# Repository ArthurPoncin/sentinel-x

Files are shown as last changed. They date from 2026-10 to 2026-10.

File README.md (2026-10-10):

<div align="center">

# Sentinel-X

**An autonomous surveillance outpost for remote industrial sites.**

One enclosure senses gas leaks, overheating and intruders, raises its own alarm,
and shows the whole site on a real-time 3D Digital Twin.

<p>
  
  
  
</p>

<p>
  
  
  
  
  
  <br>
  
  
  
  
  
  
  <br>
  
  
  
  
</p>

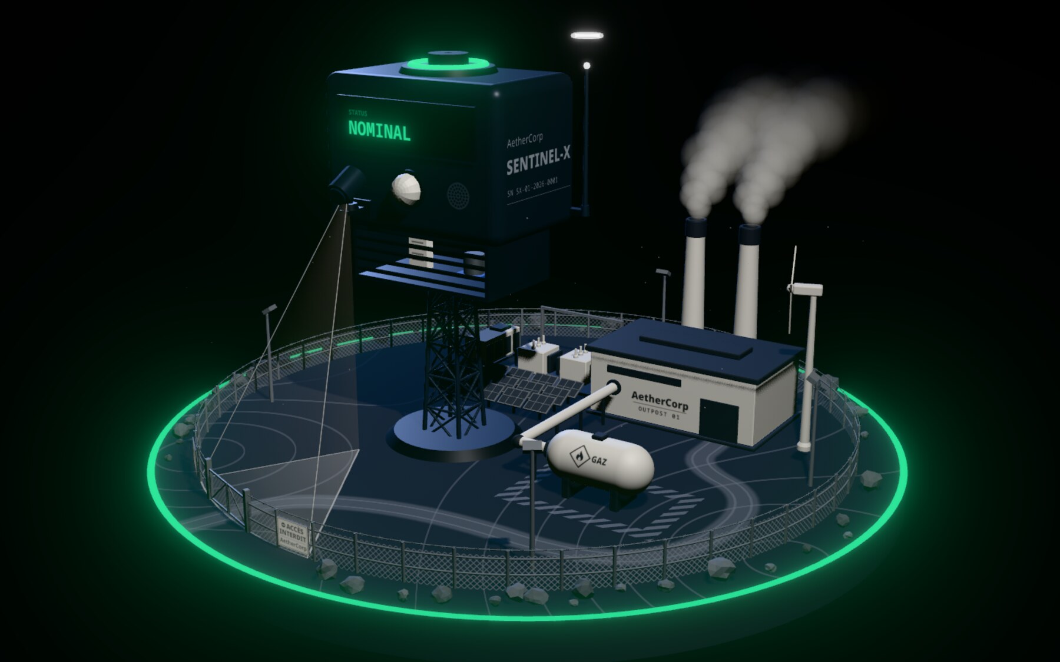
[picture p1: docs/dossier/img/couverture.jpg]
The Digital Twin of the outpost, Status nominal: the Sentinel-X enclosure on its mast, the generator hall, the gas tank, the fence and the camera's field


[Screens](#screens) · [Features](#features) · [Architecture](#architecture) · [Security](#security) · [Quick start](#quick-start) · [Documentation](#documentation)

</div>

## Overview

Sentinel-X answers a brief from the EPSI Workshop 2026: protect a micro power plant in a remote, hostile area where no staff can stay on site. An ESP32 and a Raspberry Pi 4 share one 3D-printed enclosure. Together they watch the site, decide alone, and report to an Operator over an isolated, encrypted Wi-Fi link.

| It guards against | How | Decided on |
|---|---|---|
| Gas leak, overheating | MQ-2 and DHT22 probes, thresholds with hysteresis, siren fired locally | ESP32 |
| Presence, noise | PIR and sound sensor | ESP32 |
| Intrusion | Person detection on a USB webcam that turns to follow whoever it sees | Raspberry Pi 4 |
| A failure before it happens | Isolation Forest on the trend of temperature and gas, no fixed threshold | Raspberry Pi 4 |
| Network attack | TLS and authentication on every channel, two service ports exposed | Whole stack |

Five students built it in one week: more than 270 commits, 78 merged pull requests and 1,483 automated tests.

## Screens

The Twin is not an illustration. It is driven by the same event stream the real enclosure emits.

<table>
  <tr>
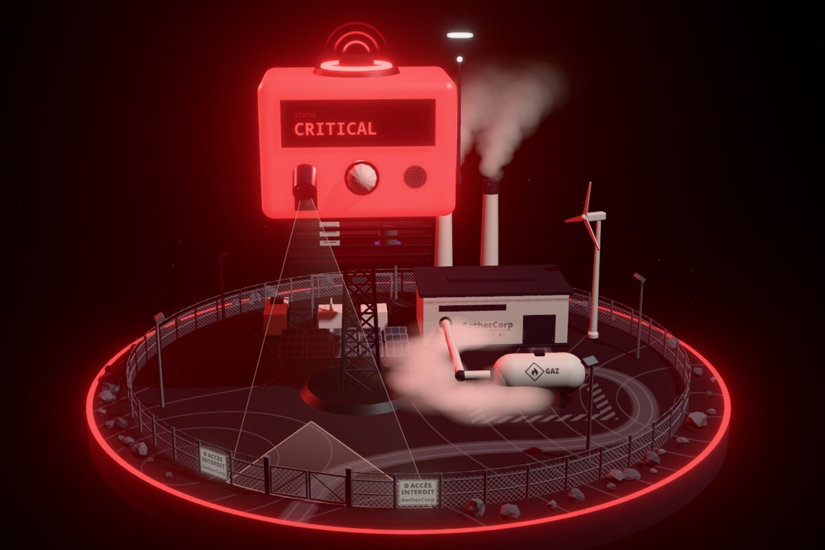
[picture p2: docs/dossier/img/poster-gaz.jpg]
Digital Twin during a gas leak: Status critical, haze around the gas pipe
    <td width="33%"></td>
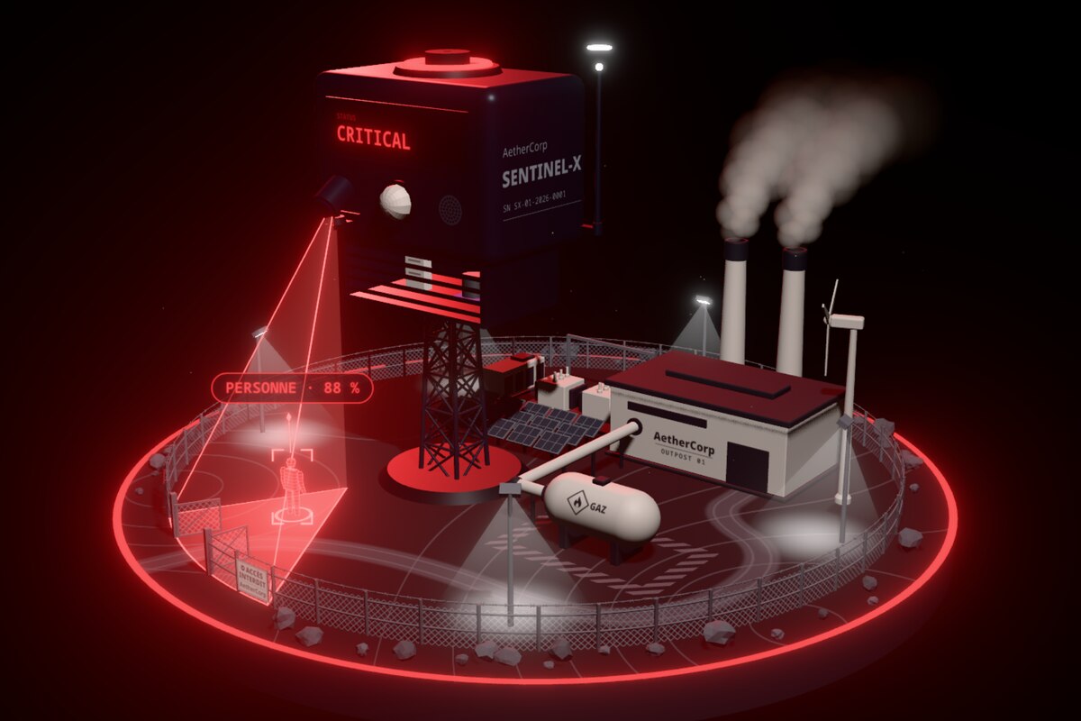
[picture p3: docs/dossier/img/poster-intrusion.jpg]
Digital Twin during an intrusion: a hologram figurine inside the fence, labelled with the model's confidence
    <td width="33%"></td>
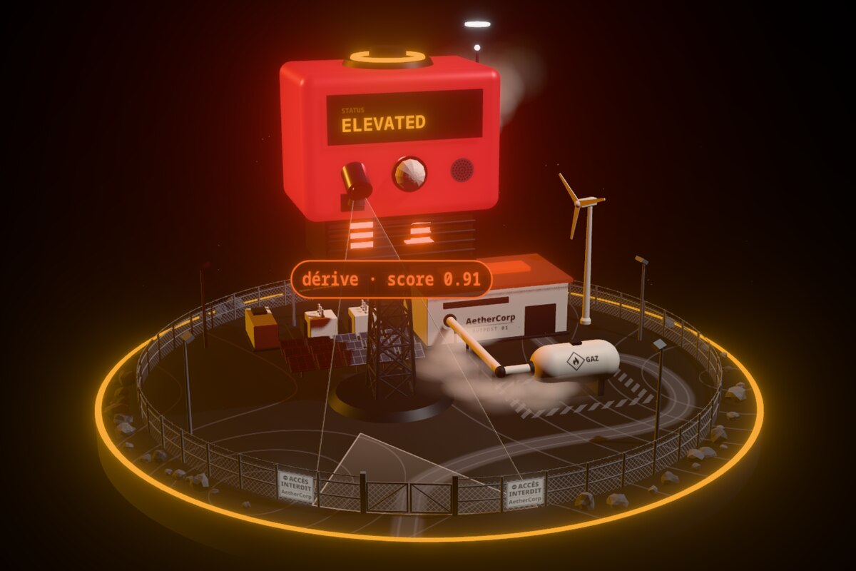
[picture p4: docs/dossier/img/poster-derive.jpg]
Digital Twin during a predicted drift: Status elevated, anomaly score 0.91
    <td width="33%"></td>
  </tr>
  <tr>
    <td align="center"><b>Gas leak</b><br><sub>Status critical, haze thickens at the pipe, the siren sounds</sub></td>
    <td align="center"><b>Intrusion</b><br><sub>A figurine stands where the camera sees the person, floodlights on</sub></td>
    <td align="center"><b>Predicted drift</b><br><sub>The drifting component pulses before any threshold is crossed</sub></td>
  </tr>
</table>

<p align="center">
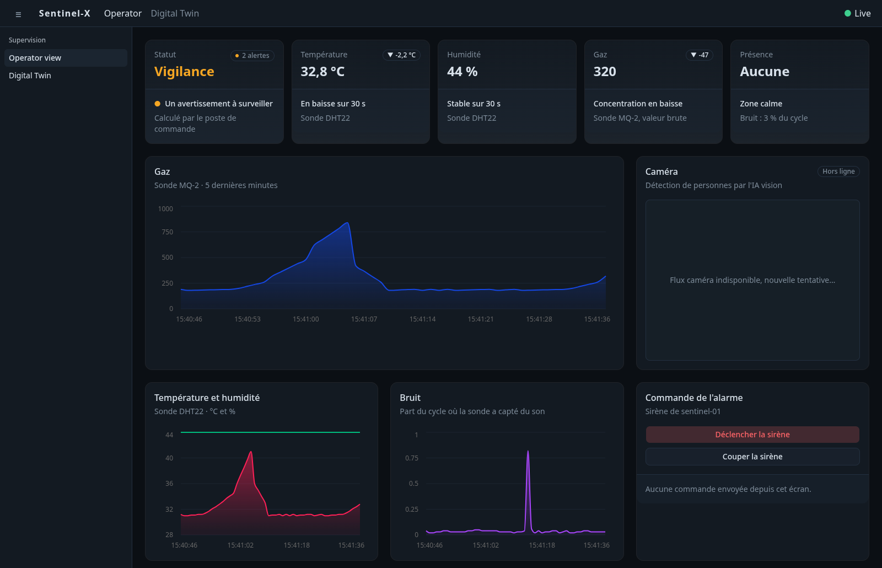
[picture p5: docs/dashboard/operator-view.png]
Operator view: Status, live Readings, gas, temperature and noise charts, camera panel and siren control
  
  <br>
  <sub><b>Operator view.</b> Status, live Readings, charts, camera panel and siren control. Captured on the scripted mock feed, so the camera panel has no webcam to show.</sub>
</p>

<table>
  <tr>
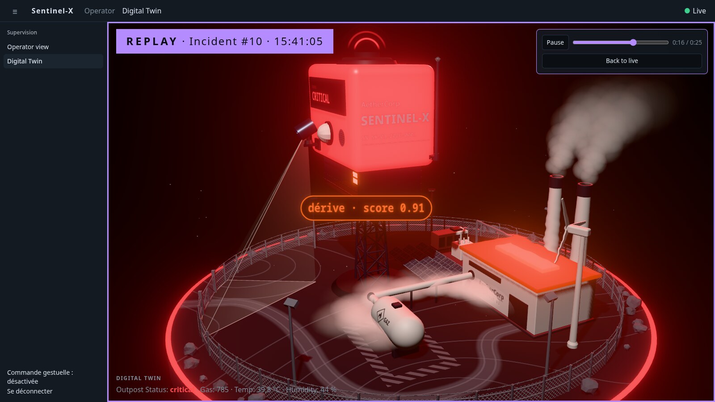
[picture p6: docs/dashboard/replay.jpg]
The Digital Twin replaying a recorded Incident, with the time-scrubber at 0:16 of 0:25
    <td width="50%"></td>
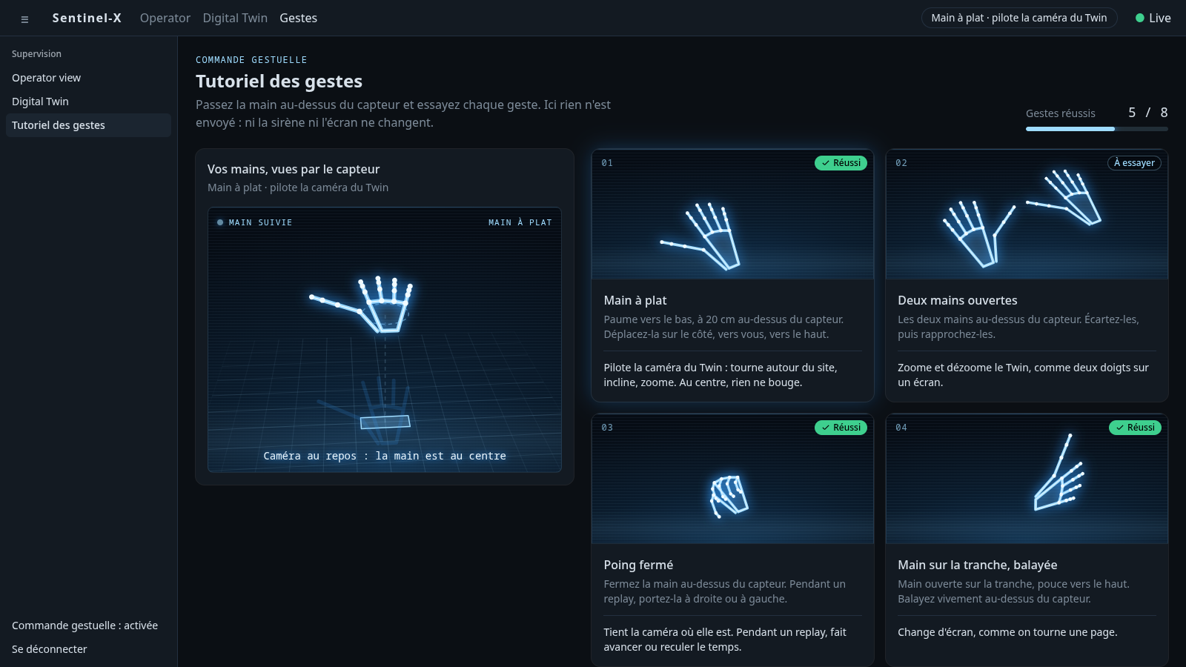
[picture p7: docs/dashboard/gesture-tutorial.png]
Gesture tutorial: the tracked hand in hologram and the gestures already made
    <td width="50%"></td>
  </tr>
  <tr>
    <td align="center"><b>Time-scrubber</b><br><sub>Any recorded Incident replays second by second on the Twin</sub></td>
    <td align="center"><b>Hand control</b><br><sub>The gesture tutorial, here with the bridge's simulated hand</sub></td>
  </tr>
</table>

A 60-second teaser is in the repository: [`docs/livrables/sentinel-x-teaser.mp4`](docs/livrables/sentinel-x-teaser.mp4).

## Features

**Digital Twin.** A live 3D model of the outpost (Three.js, react-three-fiber) fed by the Command Post's WebSocket stream.

| Signal | What the Twin does |
|---|---|
| Gas Reading | Haze thickens around the gas pipe, the enclosure glows red |
| Temperature | The generator hall's roof glows, the air above it ripples on a thermal Alert |
| Presence (PIR) | An amber sweep goes round the fence, the floodlights come on |
| Noise | A wave of light spreads from the enclosure, scaled to how loud it was |
| Intrusion | A hologram figurine stands where the person is, the camera's field turns with the real camera |
| Predictive drift | The drifting component pulses orange, with its anomaly score |
| Status | The scene is flooded in the Status color, then the ring and the LCD keep it |
| Feed lost | The picture drops out like a screen's, so a lost link never passes for a calm site |

**Autonomy at the edge.** The Sentinel decides its own Alerts and fires the siren even when the Command Post is down. One Alert is one transition: hysteresis on every threshold, no flapping.

**Vision.** EfficientDet-Lite0 on LiteRT keeps the `person` class only. A tracker follows the nearest person, tells of up to four others, and sends where they stand (`x_norm`, `h_norm`, `pan`) so the Twin places each one. A stepper motor turns the webcam toward the person followed.

**Predictive maintenance.** No `if temp > 40`. An Isolation Forest scores a 120-second window of seven features: the levels of temperature, humidity and gas, then the slopes and rolling means of temperature and gas. The model in service was trained on 32,101 readings from the real Sentinel (20,009 vectors), and its raise and clear levels are learned from held-out nominal data. On the synthetic drift shipped with the repo, the Alert comes about 43 minutes before the warning threshold.

**Time-scrubber.** Every Incident is recorded in SQLite and replays on the Twin, labelled REPLAY, with the camera turning to where each Alert happens.

**Hand control.** A Leap Motion Controller on the Operator's laptop steers the Twin's camera, winds a replay, changes screen, and sounds or silences the siren with a held thumb. A tutorial screen teaches the eight gestures.

**Plug and play.** One script takes a Raspberry Pi from a fresh OS to a running outpost: Wi-Fi access point, certificates and secrets, container stack, firmware built and flashed on the ESP32. The arm64 images are prebuilt by CI and pulled from GHCR.

## Architecture

The Raspberry Pi 4 is the single server (the brief's Option A, "embedded centralization"). It sits in the enclosure with the ESP32. The Operator's laptop is a browser, nothing more.

```mermaid
flowchart LR
    subgraph enclosure["Sentinel-X Enclosure · 3D-printed"]
        subgraph sentinel["Sentinel · ESP32"]
            DHT["DHT22 · temp / humidity"]
            MQ2["MQ-2 · gas"]
            PIR["PIR · presence"]
            SND["Sound sensor"]
            ALARM["Alarm · speaker"]
        end
        subgraph cp["Command Post · Raspberry Pi 4 · Wi-Fi AP"]
            CAM["USB webcam on a stepper motor"]
            SCREEN["HDMI status screen"]
            subgraph docker["Docker Compose"]
                PROXY["reverse-proxy · HTTPS/WSS :443"]
                BROKER["mosquitto · MQTTS :8883"]
                API["api · REST + WebSocket"]
                DB[("history · SQLite")]
                DASH["dashboard · 3D Twin"]
                VISION["vision · person detection"]
                PRED["predictive · Isolation Forest"]
            end
        end
    end
    OP["Operator laptop · browser only"]

    sentinel -- "MQTTS: telemetry + Alerts" --> BROKER
    BROKER -- "MQTTS: actuator commands" --> sentinel
    BROKER <--> API
    API <--> DB
    CAM --> VISION
    BROKER -- "read-only" --> SCREEN
    VISION -- "POST /api/v1/alerts + token" --> API
    BROKER -- "live telemetry" --> PRED
    DB -. "read-only, training" .-> PRED
    PRED -- "POST /api/v1/alerts + token" --> API
    OP -- "HTTPS / WSS + Operator session" --> PROXY
    PROXY --> DASH
    PROXY --> API
    PROXY -- "camera feed" --> VISION
```

Two ingress paths feed one Alert pipeline: the Sentinel publishes over MQTTS, the AI services post to `POST /api/v1/alerts` on the internal Docker network. The API validates every message against a shared schema, derives the Outpost's `Status` (`nominal`, `elevated`, `critical`), stores the history and pushes it to the dashboard. The contract is in [`docs/ARCHITECTURE.md`](docs/ARCHITECTURE.md).

| Layer | Stack | Folder |
|---|---|---|
| Firmware | C++, Arduino core, PlatformIO, PubSubClient, ArduinoJson | [`firmware/`](firmware/) |
| API | Node 22, TypeScript, Fastify, WebSocket, MQTT.js, Zod, SQLite | [`backend/`](backend/) |
| Dashboard | React 19, react-three-fiber, Three.js, Vite, Tailwind CSS, Recharts | [`dashboard/`](dashboard/) |
| Vision | Python, OpenCV, LiteRT (EfficientDet-Lite0) | [`ai/vision/`](ai/vision/) |
| Predictive | Python, scikit-learn (Isolation Forest), paho-mqtt | [`ai/predictive/`](ai/predictive/) |
| Hand bridge | Node 22, TypeScript, Ultraleap LeapC through FFI | [`leap/`](leap/) |
| Platform | Docker Compose, Mosquitto, Caddy, NetworkManager, dnsmasq, chrony | [`infra/`](infra/) |
| Security | OpenSSL team CA, UFW, hardening and audit scripts | [`cyber/`](cyber/) |
| Enclosures | OpenSCAD, STL for the Creality K2 Plus, no supports | [`enclosure/`](enclosure/) |

## Security

| Channel | Protection |
|---|---|
| Sentinel to broker | MQTTS only, TLS 1.2 or later, broker verified against the team CA, one account and one ACL per client, no anonymous access |
| Operator to dashboard | HTTPS and WSS behind Caddy, login rate-limited to 5 a minute, session cookie `HttpOnly`, `Secure`, `SameSite=Strict` |
| AI services to API | Internal Docker network, one bearer token per service, each bound to its own kind of Alert |
| Network | Isolated WPA2 Wi-Fi access point with no route out, two service ports published (443 and 8883), no plaintext listener |
| Containers | `cap_drop: ALL`, `no-new-privileges`, read-only root filesystem, non-root users, log rotation |
| Payloads | Identity is never read from a message body: the Sentinel comes from the MQTT topic, the source from the channel |
| Repository | No secret in git, checked by CI on every pull request |

The engineering report lists 19 controls: six are proven by the API's automated tests, nine are read in the versioned configuration, and four depend on the host hardening script [`cyber/harden.sh`](cyber/harden.sh) (UFW, key-only SSH, Docker ports kept to the table Wi-Fi).

## Quick start

**On a laptop, without hardware** (Node 22 or later). The API plays a scripted scenario in a loop: a gas leak, a clap, an intruder.

```bash
git clone https://github.com/ArthurPoncin/sentinel-x.git && cd sentinel-x

# terminal 1: the API on its mock feed
cd backend && npm install && OPERATOR_AUTH=off MOCK_FEED=true HISTORY_FILE=:memory: npm run dev

# terminal 2: the dashboard, on http://localhost:5173 (Operator view at /, Twin at /twin)
cd dashboard && npm install && npm run dev
```

**On a Raspberry Pi 4**, with the ESP32 plugged into one of its USB ports and Ethernet for the first run:

```bash
git clone https://github.com/ArthurPoncin/sentinel-x.git && cd sentinel-x
infra/plug-and-play.sh X     # X = table number: the Pi becomes 192.168.X.1
```

The dashboard is then on `https://192.168.X.1/`. Step by step, from a blank SD card: [`docs/INSTALLATION-PI.md`](docs/INSTALLATION-PI.md) (in French).

## Quality

| Aspect | State |
|---|---|
| Tests | 1,483 on `main` on 9 October 2026: 776 dashboard, 437 AI, 255 API, 15 hand bridge |
| CI, on every pull request | Typecheck and tests, production build, smoke render of the dashboard in a headless browser, AI tests on Python 3.11 and 3.13, firmware build, shellcheck, Compose validation, secret check |
| Images | Five arm64 images built on GitHub's Arm runners and published on GHCR on every push to `main` |
| Workflow | One issue per user story, one branch per issue, pull request before `main` |

## Status and limits

- The predictive model trained on the real Sentinel has been in service on the Pi since 9 October 2026.
- `cyber/harden.sh` is ready and was verified in a Debian 12 container. It was not applied to the demo Pi.
- Vision runs on a Pi 4 where the brief assumes a Pi 5. Its latency on the Pi was not recorded; the benchmark tool is `python -m vision.bench`.
- Hand control needs Ultraleap's tracking software, so the bridge runs on a Windows or macOS laptop, not on the Pi.
- The Operator's interface is in French.

## Documentation

| Document | Content |
|---|---|
| [`docs/ARCHITECTURE.md`](docs/ARCHITECTURE.md) | Topology, Alert ownership, JSON contract, security model, network plan |
| [`docs/DIGITAL-TWIN.md`](docs/DIGITAL-TWIN.md) | What each signal does on the Twin, and why |
| [`docs/SCOPE.md`](docs/SCOPE.md) | Demo scenario and build tiers |
| [`GLOSSARY.md`](GLOSSARY.md) | The project's vocabulary: Outpost, Sentinel, Command Post, Alert, Incident |
| [`docs/INSTALLATION-PI.md`](docs/INSTALLATION-PI.md) | Installing the Command Post, step by step (French) |
| [`docs/DURCISSEMENT-PI.md`](docs/DURCISSEMENT-PI.md) | Hardening the Pi before a pentest (French) |
| [`cyber/PENTEST-PLAN.md`](cyber/PENTEST-PLAN.md) | Defensive checklist and offensive audit plan (French) |
| [`docs/dossier/`](docs/dossier/) and [`docs/soutenance/`](docs/soutenance/) | Sources of the engineering report and of the defence deck (French) |

Each folder has its own README: [`firmware`](firmware/README.md), [`backend`](backend/README.md), [`dashboard`](dashboard/README.md), [`ai`](ai/README.md), [`leap`](leap/README.md), [`infra`](infra/README.md), [`cyber`](cyber/README.md), [`enclosure`](enclosure/README.md) (French).

## Team

Built by five students (three developers, two infrastructure) for the EPSI Workshop 2026, from 5 to 9 October 2026. See the [contributors](https://github.com/ArthurPoncin/sentinel-x/graphs/contributors).

The brief is in the repository: [`Workshop-2026_BAC+4_Sujet_Sentinel-X.pdf`](Workshop-2026_BAC+4_Sujet_Sentinel-X.pdf) (French).

## License

[MIT](LICENSE)

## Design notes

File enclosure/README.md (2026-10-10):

# enclosure/ : les boîtiers à imprimer

Trois objets, huit fichiers STL dans [`stl/`](stl/), chacun déjà posé dans le bon sens pour l'impression. Aucun ne demande de support.

| Objet | Ce qu'il contient | Taille hors tout |
|---|---|---|
| **Poste de commande** | Raspberry Pi 4, écran HDMI 800×480 en façade, webcam USB sur un plateau tournant, moteur 28BYJ-48 et sa carte ULN2003 | 150 × 140 × 95 mm, plus la webcam |
| **Sentinel** | ESP32 sur ses deux demi-breadboards, DHT22, MQ-2, PIR HC-SR501, micro CZN-15E, enceinte | 151 × 155 × 61 mm |
| **Support Leap Motion** | Le Leap Motion Controller d'origine, à plat sur le bureau de l'Opérateur | 128 × 58 × 15 mm |

| Poste de commande | Arrière | Intérieur |
|---|---|---|
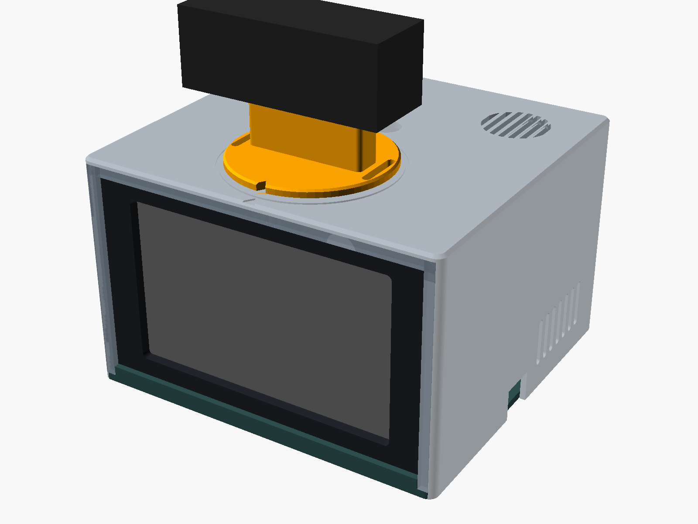
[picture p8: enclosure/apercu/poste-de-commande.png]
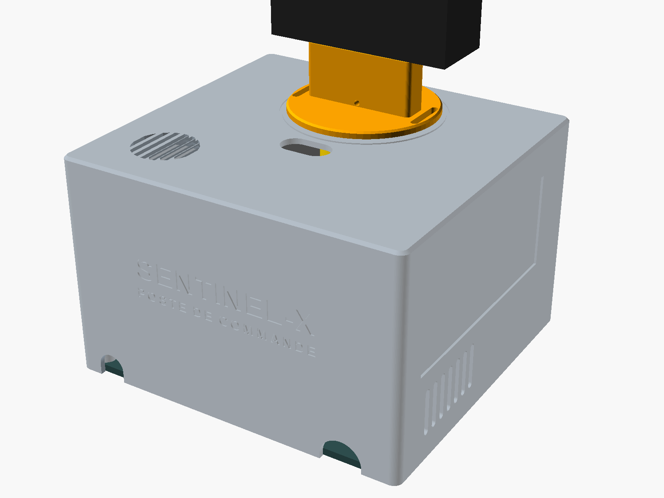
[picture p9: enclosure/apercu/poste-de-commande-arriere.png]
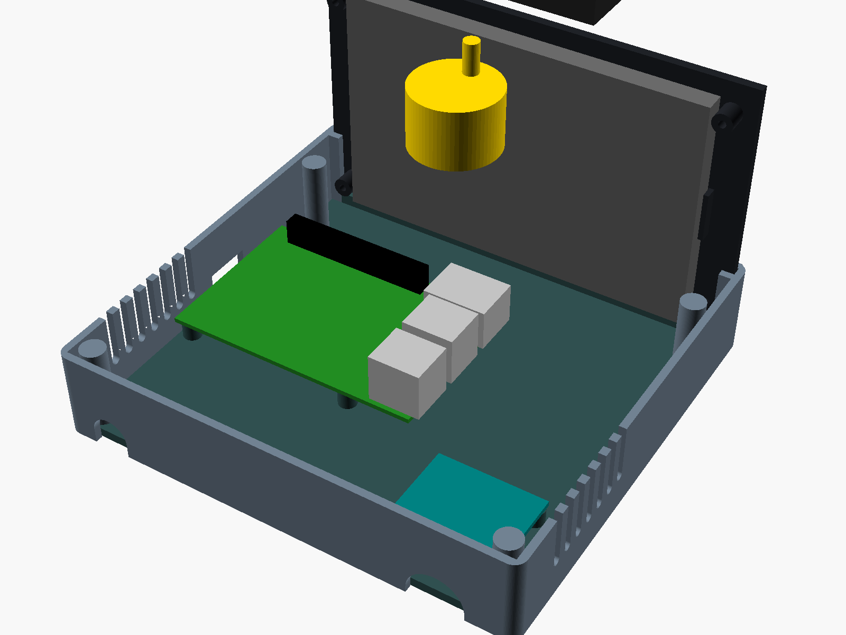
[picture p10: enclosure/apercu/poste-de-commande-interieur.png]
|  |  |  |

| Sentinel | Intérieur, vu de l'arrière | Support Leap Motion |
|---|---|---|
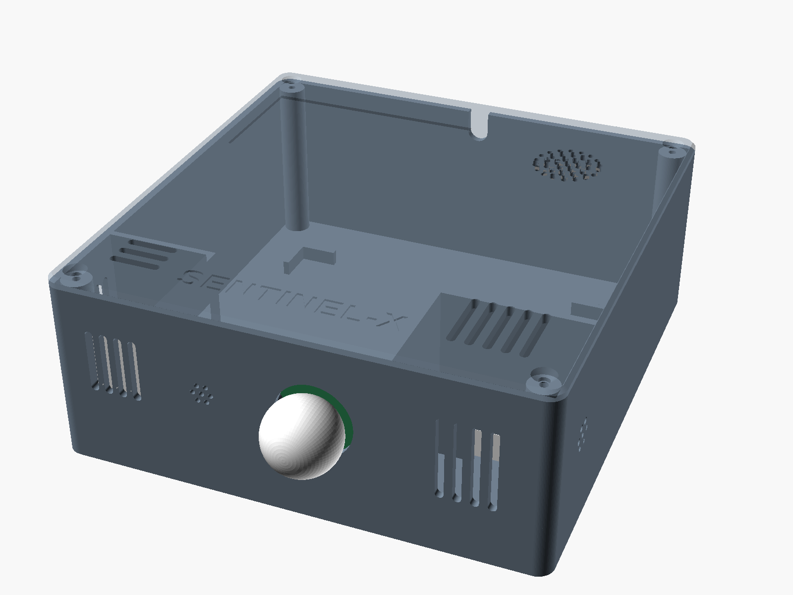
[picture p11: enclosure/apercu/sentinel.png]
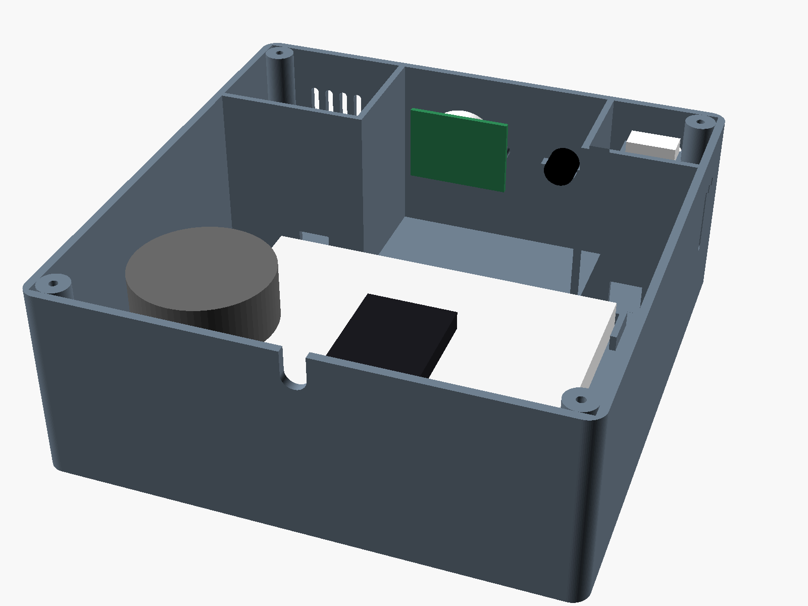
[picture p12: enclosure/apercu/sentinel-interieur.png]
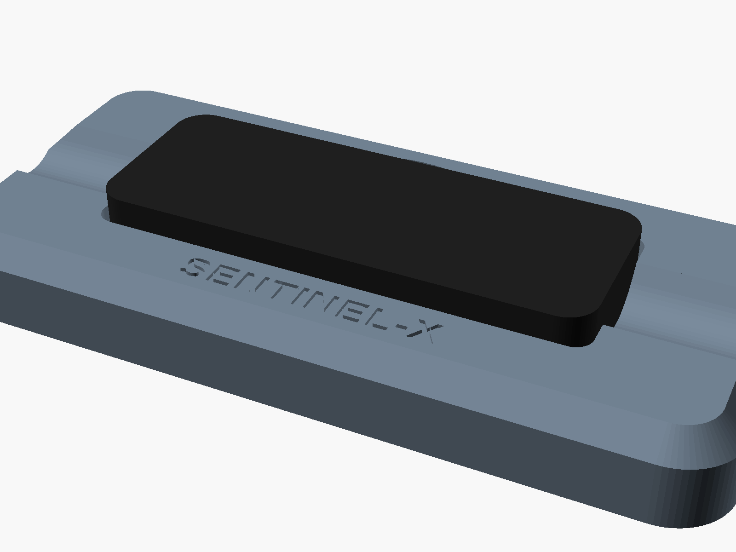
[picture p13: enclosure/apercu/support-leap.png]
|  |  |  |

## Les fichiers

| Fichier | Pièce | Posée sur le plateau par |
|---|---|---|
| `command-post-shell.stl` | Coque : toit et trois murs | le toit |
| `command-post-base.stl` | Socle : le Pi, la carte ULN2003 | le dessous |
| `command-post-bezel.stl` | Façade : la fenêtre de l'écran | la face avant |
| `command-post-clamps.stl` | Les deux brides qui tiennent l'écran | à plat |
| `command-post-turntable.stl` | Plateau de la webcam, sur l'axe du moteur | le dessous |
| `sentinel-base.stl` | Boîte du Sentinel : fond, murs, compartiments | le fond |
| `sentinel-lid.stl` | Couvercle du Sentinel, avec le support de l'enceinte | le dessus |
| `leap-stand-stand.stl` | Support du Leap Motion | le dessous |

## Impression

Sur la Creality K2 Plus du myDiL (350 mm de plateau : chaque pièce passe en une fois).

- **Matière** : PLA pour le Poste de commande et le Leap. **PETG** de préférence pour le Sentinel : la chauffe du MQ-2 dégage près d'un watt dans son compartiment.
- Couches de 0,2 mm, 3 périmètres, remplissage 15 à 20 % (gyroïde), sans support, sans bordure.
- Au plus 750 g de filament pour le tout (le volume plein des pièces), moins avec le remplissage.

## Visserie et petit matériel

| Pour | Quoi |
|---|---|
| Le Pi sur le socle | 4 vis M2,5 × 6 |
| Le socle sous la coque | 4 vis M3 × 12 tête fraisée, par en dessous |
| Le moteur sous le toit | 2 vis M3 × 8 tête fraisée et 2 écrous M3 |
| L'écran sur la façade | 4 vis M3 × 10 |
| La carte ULN2003 | 4 vis M3 × 6, ou un carré d'adhésif double face mousse si ses trous ne tombent pas (prévus à 29,5 × 27 mm) |
| Le plateau sur l'axe, s'il a du jeu | 1 vis M3 × 8, par le trou au dos de la barre |
| Le couvercle du Sentinel | 4 vis M3 × 12 tête fraisée |
| Le PIR | 2 vis M2 × 6, ou un point de colle chaude |
| Le micro, le MQ-2, l'enceinte | Colle chaude |
| Sous chaque boîtier et sous le Leap | 4 patins caoutchouc de 10 mm |
| Option : ventilateur 30 × 30 mm 5 V sous la grille du toit | 4 vis M3 × 16, ses fils sur les broches 2 (5 V) et 6 (GND) du Pi |

## Montage du Poste de commande

1. **Écran sur la façade.** Face contre la façade, la zone affichée dans la fenêtre. Les deux brides se vissent sur les quatre plots, le long de ses bords haut et bas.
2. **Pi sur le socle.** Carte SD vers la droite (l'encoche du mur droit la laisse accessible), connecteur GPIO vers l'avant, ports USB et Ethernet vers la gauche. Quatre vis M2,5.
3. **Carte ULN2003** sur les quatre plots du coin arrière gauche.
4. **Moteur sous le toit.** Son axe sort par le trou du toit, son fil bleu vers l'arrière. Deux vis fraisées par le dessus, les écrous dessous, sur ses pattes.
5. **Plateau.** Enfoncé sur l'axe, sa pointe en face du triangle gravé sur le toit : la caméra regarde droit devant. C'est le zéro du moteur, à refaire avant chaque démarrage (il compte ses pas depuis là).
6. **Webcam.** Son clip se pose sur la barre du plateau comme sur le haut d'un écran. Sans clip, une sangle velcro passe par les deux fentes. Son câble descend par la fente derrière le plateau, jusqu'à un port USB du Pi.
7. **Câblage**, comme sur [`docs/cablage/raspberry-pi.html`](../docs/cablage/raspberry-pi.html) : broches 31, 33, 35, 37 vers IN1 à IN4, 39 vers −, 4 vers + ; le moteur dans la prise blanche de l'ULN2003 ; l'écran sur le micro-HDMI 1, son alimentation USB sur un port USB du Pi. Le câble USB de l'ESP32 et, si besoin, l'Ethernet passent dans l'encoche arrière gauche, l'alimentation USB-C dans l'encoche arrière droite. Toutes les fiches restent dedans : à l'arrière ne sortent que l'alimentation et le câble de l'ESP32, plus l'Ethernet s'il est branché.
8. **Fermeture.** La façade debout dans la rainure à l'avant du socle, on descend la coque par-dessus : la façade glisse dans les rainures des murs jusqu'à celle du toit. Quatre vis M3 × 12 par-dessous.

## Montage du Sentinel

1. **Breadboards** collées entre les quatre équerres du fond (leur adhésif suffit). L'ESP32 à cheval sur la jonction, **son USB contre le mur du fond**, à l'aplomb de l'encoche.
2. **DHT22** glissé par le haut dans son support, grille contre les fentes, posé sur ses deux piliers : ses quatre fiches Dupont passent dessous. Ses fils sortent du compartiment par le passage au ras du fond.
3. **MQ-2** : sa capsule dans le berceau du mur droit, face aux trous, un point de colle chaude sur la carte (pas sur la capsule, qui chauffe). Fils par le passage de son compartiment.
4. **PIR** : le dôme sort par le trou de la façade, la carte se visse sur les deux plots (M2) ou se colle. Ses deux potentiomètres et son cavalier restent accessibles couvercle ouvert.
5. **CZN-15E** : sa capsule dans le petit berceau, face aux trous, un point de colle.
6. **Enceinte** dans la marche du couvercle à sa taille (28, 36, 40 ou 50 mm), un cordon de colle chaude autour. Fils assez longs pour ouvrir le couvercle.
7. Une fois câblé comme sur [`docs/cablage/esp32.html`](../docs/cablage/esp32.html), un bout de mousse ou de ruban bouche les deux passages de fils : la chaleur du MQ-2 reste dans son compartiment, loin du DHT22.
8. Le câble USB couché dans l'encoche du fond, le couvercle se visse aux quatre coins (M3 × 12 fraisées).

## Support Leap Motion

Le capteur se pose dans le creux, sa LED verte vers l'Opérateur ; son câble sort par l'un ou l'autre bout. L'encoche à l'arrière sert à le soulever. Le dessus du capteur dépasse le bord : rien ne gêne son champ de vision.

## Gravure laser

Le sujet demande des plaques gravées (logo, consignes, numéro de série) sur le boîtier. Deux logements de 1 mm de profondeur les attendent :

- Poste de commande, mur gauche : **100 × 40 mm**, plaque à découper à 99,4 × 39,4 mm ;
- Sentinel, couvercle : **70 × 40 mm**, plaque à 69,4 × 39,4 mm.

En plexiglas ou contreplaqué de 3 mm sur la Creality Falcon A1, collées.

## Ce qui a été supposé, à vérifier avant d'imprimer

Toutes ces cotes sont en tête des fichiers `.scad`. Après un changement, `./build.sh` refait les STL et les aperçus (OpenSCAD 2024 ou plus récent : `brew install --cask openscad@snapshot`).

| Cote | Valeur prise | Fichier, variable | Si c'est faux |
|---|---|---|---|
| **Écran** : carte, zone affichée, épaisseur au bord | 121,2 × 78 mm, 108,5 × 65,5 mm, 7 mm (un 5 pouces HDMI 800×480 type Waveshare) | `command-post.scad`, `scr`, `scr_view`, `scr_view_off`, `scr_edge` | Seules la façade et les brides changent, sauf si l'écran est plus grand : la coque et le socle s'élargissent alors d'eux-mêmes |
| Trous de la carte ULN2003 | 29,5 × 27 mm | `uln_holes` | Adhésif mousse sur les plots |
| Pied carré de la lentille du PIR | 4 mm entre le mur et sa carte | `sentinel.scad`, `pir_skirt` | Un point de colle |
| Capsule du MQ-2, du micro | Ø 19,8 mm, Ø 9,7 mm | `cradle(...)` dans `sentinel.scad` | Colle chaude |
| Leap Motion d'origine | 80 × 30 mm | `leap-stand.scad`, `leap` | — |
| Axe du 28BYJ-48 | Ø 5 mm, méplats à 3 mm | `turntable()` | Vis M3 au dos de la barre |
| Webcam | Un clip d'écran | `tt_bar` (barre de 12 mm d'épaisseur) | Sangle velcro par les fentes |

Les sources sont les fichiers `.scad` : `common.scad` (outils partagés), `command-post.scad`, `sentinel.scad`, `leap-stand.scad`. Chacun prend `part="..."` : une pièce posée pour l'impression, `assembly` le boîtier monté avec ses composants en couleur, `inside` son intérieur.

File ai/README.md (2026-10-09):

# ai/ — Local AI & Data

**Node:** Command Post (Raspberry Pi 4) · **Language:** Python · **Runs as:** `vision` and `predictive` containers in the Pi's Docker-Compose stack

Two jobs, both on the Pi (the brief's Option A): **see** (intrusion on the USB webcam) and **predict** (correlation-based maintenance). Results are posted to the API as Alerts.

## Vision — intrusion detection
- **Base:** [`automaticdai/rpi-object-detection`](https://github.com/automaticdai/rpi-object-detection) (MIT) — lightweight Python + OpenCV, built for the Pi. We reuse `src/object-detection-tflite` (EfficientDet-Lite0 or SSD MobileNet, COCO labels) and keep only the `person` class; `src/motion-detection` (OpenCV) is the fallback. Keep its license notice in the copied code.
- Capture the **USB webcam** with OpenCV's `VideoCapture`. In the container: its device node passed with `devices:` — never `privileged`. The ZIF camera first planned (Joy-IT RB-Camera-JT, OV5647, read with Picamera2) was dropped: the Pi detected it but never got a frame from it.
- Resize/throttle frames (**≤ 640x480**, target **< 100 ms/frame**).
- Emit an `intrusion` Alert with **`x_norm`** (normalized horizontal position 0→1), **`h_norm`** (how tall the person is in the image, 0→1: how near) and **`pan`** (how far the camera is turned), so the 3D twin can stand the intruder where they are on the site — and **`others`**, the other people in the image, for it to stand a figurine for each.
- **Turn the camera** to the person it follows, when it is on a servo (`PAN_DRIVE=pwm`, [below](#the-camera-on-its-servo--pan_drivepwm)) or on a stepper motor (`PAN_DRIVE=stepper`, [below](#the-camera-on-a-stepper-motor--pan_drivestepper)).
- `vision` is the only process that opens the camera, so it also **serves the camera feed** to the dashboard (MJPEG, detections drawn), through the reverse proxy behind the Operator session.

### The intrusion Alert's lifecycle — `vision.tracker.IntruderTracker`
Pure, camera and model aside: each inference's person boxes in, the Alerts to post out, the time passed in by the caller.
- **One intrusion at a time, however many people make it.** One of them is **followed**: the nearest, the tallest in the image, when nobody is followed yet (of two as near, the one the detector is surest of). They stay the one for as long as they are seen, whoever comes nearer meanwhile: the Alert places them, and the camera turns to them. `x_norm` = their box's horizontal centre / image width, clamped to 0→1; `h_norm` = their box's height / image height, the box clipped to the image; `bbox` = `[x, y, w, h]` in whole pixels of the captured image, clipped to it; `id` tells them from the others. `severity: critical`.
- **The others**, at most 4, the nearest first: `others: [{ id, x_norm, h_norm, confidence }]`. Someone is told of once seen on 2 inferences, and for 1 s after the detector last saw them (`hold`): a flash is nobody, and a miss of a frame or two takes nobody away. Beyond 5 people in the image, the furthest are left out.
- **The same person from one inference to the next** is the one seen within a quarter of the field of view of where they stood (`gate`, 15° at 60°) — around the camera, not across its image, so a camera that turns does not make everyone someone else. One person left without a detection and one detection left without a person are the same one, who went further than that: someone alone who walks fast keeps their `id`.
- **When the person followed leaves**, the nearest of the others seen often enough is followed in their place, on the same `alert_id`. While there is nobody else, they stay the one the Alert tells of, where they last were, until it clears: a flash elsewhere does not move the last known position.
- **`raised`** once a person is seen on **2 inferences in a row**: a one-frame flash raises nothing.
- **`raised` again, same `alert_id`**, when what the Alert tells has changed since the last one sent: someone moved by **≥ 0.05** across the image or by **≥ 0.08** of its height, the camera turned by **≥ 3°**, someone came or left, or another person is followed — **at most every 500 ms**; a change made inside those 500 ms is sent once they are over, unless it was undone. People standing still in front of a camera that does not turn send nothing.
- **`cleared`** once nobody has been seen for **3 s** (`CLEAR_AFTER_S`), with the last known detail — also when inference stalls, through `tick()`. A shorter miss changes nothing; whoever comes after a clear gets a new `alert_id`.
- **`pan`** is how far the camera was turned when the image was taken, in degrees from where it rests, positive toward the right of its image; `0.0` for a camera that does not turn. The tracker is given it with each inference, and `CAMERA_FOV_DEG` (60), the lens's horizontal field of view, which turns a place across the image into an angle — the same value as the Twin's (`SITE.camera.fov`).
- **`h_norm` says how near only with a person detector.** A blob of `DETECTOR=motion` is as tall as what moved.

### The service — `python -m vision`
The camera in, the tracker's Alerts posted with `VISION_TOKEN`, the annotated feed out. Runs on a laptop with a webcam or a video file: no Pi needed.
- **Source** (`vision.sources`, `CAMERA_SOURCE`): `opencv:0` a webcam (the stack's default: the Pi's USB webcam), `picamera2` the Pi's ZIF camera, `opencv:/path/video.mp4` a video file played in a loop at its own frame rate. Frames larger than 640x480 are shrunk, proportions kept. A capture thread keeps only the **latest** frame. A camera absent or lost stops nothing: `/health` says `down`, the feed shows a "camera down" card, and the source opens it again on its own (after 0.5 s, doubling up to every 10 s).
- **Detector** (`vision.detectors`, `DETECTOR`): `tflite`, the person detector (EfficientDet-Lite0, [below](#the-person-detector--detectortflite)), or `motion`, OpenCV's MOG2 background subtraction, worked at 320 px wide; the largest blobs are the detections, `confidence` = blob area / 4 % of the frame (about a person at the fence), capped at 1. It learns the still scene for 20 frames before reporting anything, and someone who stops moving fades into the background within seconds: motion says someone moves, not that someone is there.
- **Loop** (`vision.service.Vision`): the detector on every `INFER_EVERY`-th new frame, detections under `MIN_CONFIDENCE` dropped, the tracker's Alerts queued on the Alert client. The tracker is ticked between frames too, so a camera that stalls still clears. On SIGTERM / Ctrl-C it stops, clears the intrusion in progress (the api would keep it raised), parks the camera where it rests and sends what is queued.
- **HTTP** on `HTTP_PORT` (8000), never published: the reverse proxy serves it under `/camera`, behind the Operator session.
  - `GET /`, whatever the query string (the dashboard asks for `/camera?attempt=N`, the proxy strips `/camera`): `multipart/x-mixed-replace; boundary=frame`, the latest frame with its boxes, their confidence, a heavier box around the person followed and a status line (time, fps, inference ms, `INTRUSION` / `clear`, and `pan` when the camera turns), at most `STREAM_FPS` (15) a second, each picture encoded once for every client. `MAX_CLIENTS` (4) at once; the next one gets a `503`.
  - `GET /health`: `{"camera": "ok"|"down", "fps", "inference_ms", "clients", "detector"}`, and `"pan"`, in degrees, when the camera is on a servo; `200` while the camera works, `503` when it is down. Anything else is a `404`. Requests are not logged.
- **Configuration**, all from the environment: [`vision/.env.example`](vision/.env.example). `VISION_TOKEN` is required (32 characters or more); a bad variable stops the service at start, with its name.
- **The ZIF camera** (`picamera2`), no longer the stack's (infra/README.md): Picamera2 asks libcamera for 640x480 at 15 frames a second, in its `RGB888` format — bytes in OpenCV's `[B, G, R]` order, nothing to convert. Only the Pi's image carries Picamera2: the Dockerfile adds the Raspberry Pi apt archive (its key checked by sha256) and `python3-picamera2` when it builds for arm64. A camera libcamera does not see, or Picamera2 missing, is a camera down like any other; a camera silent for 2 s is lost and opened again.
- **Another source or detector**: a `CaptureThread` subclass with `_connect` / `_grab` / `_disconnect` (and `_wait_next` if the camera does not set the pace itself) and a line in `SOURCES`; a class with `name` and `detect(image) -> list[Detection]` and a line in `DETECTORS`.

**In development**, three terminals from the repository's root (the `ai/` venv as in [Develop & test](#develop--test)):

```bash
# the api, taking the vision token, without the mock (its scripted intruder would mix with yours)
openssl rand -hex 32 > /tmp/vision-token
cd backend && VISION_TOKEN=$(cat /tmp/vision-token) OPERATOR_AUTH=off MOCK_FEED=false HISTORY_FILE=:memory: npm run dev

# vision on the laptop's webcam (or CAMERA_SOURCE=opencv:/path/video.mp4), its feed on 127.0.0.1 only
cd ai && PYTHONPATH=common:vision CAMERA_SOURCE=opencv:0 ALERTS_URL=http://127.0.0.1:8080/api/v1/alerts \
  VISION_TOKEN=$(cat /tmp/vision-token) HTTP_HOST=127.0.0.1 .venv/bin/python -m vision

# the dashboard on http://localhost:5173, its camera panel on that feed
cd dashboard && CAMERA_URL=http://127.0.0.1:8000 npm run dev
```

Walk in front of the camera: the panel draws the box, the intruder appears on the Twin, and `curl -s 127.0.0.1:8000/health` gives the frame rate and the inference time.

### The camera on its servo — `PAN_DRIVE=pwm`
The webcam stands on a servo that turns it left and right: `vision` keeps the person it follows in the middle of its image, and says how far it is turned in every Alert. `PAN_DRIVE=none` (the default) is a fixed camera: none of this runs.
- **The follower** (`vision.pan.PanFollower`), pure like the tracker: from where the person followed stands around the camera (the tracker's `target`) to how far the camera is turned, at each instant. After each inference of an intrusion in progress it aims most of the way to them (`gain` 0.7: an inference is always a little late) and leaves them be within `PAN_DEADBAND_DEG` (4°) of the middle of the image: it does not hunt. It never turns faster than `PAN_SPEED_DEG_S` (60°/s): what it frames does not blur, and the servo, which says nothing of where it is, is where it was told to be. Nor past `PAN_MIN_DEG` / `PAN_MAX_DEG` (−90° / 90°), the servo's travel.
- **It turns for an intrusion**, not for a first sighting of what may be nobody. When the last inference did not see the person followed it stays where it is, so they are found again where they were lost; once the intrusion is cleared it waits there `PAN_HOME_AFTER_S` more (2 s), then goes back to where it rests, at 30°/s.
- **Where it rests is its 0**: where the camera stands when `vision` starts, after the Pi is turned on or back on. The stepper counts its half-steps from there; `vision` parks the camera there as it stops.
- **With nobody there, it patrols**: once back where it rests, it looks around for intruders, `PAN_PATROL_DEG` (30°) to the right, as many to the left and back again, never past `PAN_MIN_DEG` / `PAN_MAX_DEG`, slowly, at `PAN_PATROL_SPEED_DEG_S` (8°/s): the image does not blur, and the motor does not work for nothing. Someone seen on the way is followed as above, beyond the patrol if need be; once they are gone, it waits, goes back to its 0 and patrols afresh. `PAN_PATROL_DEG=0` keeps it still where it rests. With `MOTION_GATE`, the gate stays open while it patrols: the camera turning, everything moves.
- **An image is always a little old.** The angle that goes with it is the one of when it was taken (`angle_at`): without that, the camera would see the person further along the way it is turning than they are, and swing past them.
- **The servo** (`vision.pan.SysfsPwmServo`): one of the Pi's hardware PWM channels through the kernel's `/sys/class/pwm` — a pulse every 20 ms, `PAN_MIN_US` (500 µs) at one end of the travel to `PAN_MAX_US` (2500 µs) at the other, `PAN_INVERT=true` for a servo mounted the other way up. The kernel times the pulses: no jitter, where pulses timed from Python make a servo, and the camera on it, shake. No package needed, and the tests run it on a temporary directory. A channel that is missing or not writable stops nothing: logged once, tried again every 5 s, the camera fixed meanwhile.
- **It needs a person detector**: with `DETECTOR=motion` the camera stays fixed, whatever `PAN_DRIVE` says, and the service says so as it starts. A camera that turns sees everything move, and would follow its own turning. `MOTION_GATE` is fine: the gate opens while it turns, and the model decides.
- **Calibrate it on the real mount** (the defaults are a standard servo's): turn it to each end with `PAN_MIN_DEG=…`/`PAN_MAX_DEG=…` and read how far it really goes, adjust `PAN_MIN_US` / `PAN_MAX_US` until −90 and 90 are a quarter turn each way, set `PAN_INVERT` if it turns away from people, and measure the webcam's field of view for `CAMERA_FOV_DEG` (and the Twin's `SITE.camera.fov`). On the Pi these go in `.env`: [`../infra/README.md`](../infra/README.md).
- **Another drive**: a class with `name`, `open()`, `turn(angle)` and `close()`, and a line in `DRIVES`; `angle_at(moment)` too if it counts how far it really turned.

### The camera on a stepper motor — `PAN_DRIVE=stepper`
The same follower, another motor: a 28BYJ-48 on its ULN2003 board (`vision.pan.GpioStepper`), its IN1 to IN4 on four of the Pi's GPIOs, `PAN_STEPPER_PINS` (6,13,19,26: pins 31, 33, 35, 37, the ground at 39 beside them).
- **Through the kernel's GPIO character device** (`/dev/gpiochip0`, `PAN_GPIO_CHIP`) and libgpiod, the Debian package `python3-libgpiod` in the image: its version 1 (Bookworm's) or 2. Imported only for this drive; the tests give it a board of their own.
- **Half-steps**, 4096 for a turn of its shaft through its gears (`PAN_STEPS_PER_TURN`), one every `PAN_STEP_MS` (2 ms) at most: faster, it misses some. That is about 44°/s, so `docker-compose.stepper.yml` sets `PAN_SPEED_DEG_S` to 40: the follower does not ask for more.
- **It says nothing of where it is**: it counts the half-steps it made from where it started. The camera is taken to rest there when `vision` starts, and parked there as it stops. Killed without stopping, or turned by hand meanwhile, it is lost: turn it back to look straight ahead before the next start, by hand or with `python -m vision.pan <degrees>`, the service stopped — it turns the camera by that much, positive toward the right of its image, and leaves it there. Also the way to see that the board is wired, and which way the motor turns.
- **A thread of its own** steps toward where it was last told to turn, and lets the coils go once there: the gears hold the camera, the motor does not heat up, and it can be turned by hand.
- **It is always behind where it was told to be**: the loop tells it once an inference, 4° later at 40°/s and 100 ms, more when the inference is slower or the follower faster than it steps. So the angle that goes with an image is the one the motor counted (`GpioStepper.angle_at`), not the follower's: with the follower's, the camera sees the person further round than they are and swings past them, by 9° at 250 ms an inference.
- **A chip or a right that is missing stops nothing**, as for the servo: logged once, tried again every 5 s, the camera fixed meanwhile. `PAN_INVERT=true` for a motor mounted the other way.

### The person detector — `DETECTOR=tflite`
`vision.tflite.TFLiteDetector`, adapted from upstream's `src/object-detection-tflite` (its MIT notice is at the top of [`vision/vision/tflite.py`](vision/vision/tflite.py)).
- **Model:** EfficientDet-Lite0 (COCO, Apache 2.0), at its native **320x320** uint8 input, with its post-processing built in (up to 25 boxes, non-maximum suppression done) — the file TensorFlow's own Raspberry Pi example uses. [`vision/fetch_model.py`](vision/fetch_model.py) pins its URL and sha256. Not MediaPipe's `efficientdet_lite0.tflite` that upstream's README links: that one leaves anchor decoding and NMS to MediaPipe (19 206 raw boxes out), which neither upstream's code nor ours reads.
- **Weights never in git:** the image fetches them when it is built (`python3 fetch_model.py /models/efficientdet_lite0.tflite`: download, sha256 check, atomic rename; non-zero exit and no file on a mismatch). The service reads `TFLITE_MODEL` (`/models/efficientdet_lite0.tflite`); a missing file stops it at start, naming the variable and the command to fetch it.
- **Runtime:** [`ai-edge-litert`](https://pypi.org/project/ai-edge-litert/), TensorFlow Lite's own package (the old `tflite-runtime` stopped at Python 3.11): wheels for 3.11 and 3.13, x86_64 and aarch64, and it runs on the Pi OS's NumPy 1.24. Imported only for `DETECTOR=tflite`. `TFLITE_THREADS` (4, the Pi 4's cores).
- **Frame → model → frame:** the frame is stretched to 320x320 (not letterboxed, as upstream and TensorFlow's example run the model), BGR → RGB. The boxes come back normalised to the whole frame: × its width and height gives its pixels, clipped to it. Only COCO's `person` (class 0, the first line of the label map inside the `.tflite`) is kept.
- **`MIN_CONFIDENCE`** keeps one meaning: under it, a detection is nobody. For `tflite` it is the model's `person` score, 0.5 by default as upstream; for `motion`, a blob half the size of a person. Both defaults are 0.5, so one variable serves; a different `DETECTOR` may call for another value. The detector filters at it itself (the service filters again, harmlessly), so that the benchmark and the motion gate see what the service sees.
- **Motion gate** (`MOTION_GATE=true`, `vision.detectors.MotionGate`): the motion detector sees every inferred frame, the model runs only while the gate is open — `MOTION_GATE_HOLD_S` (3 s) after the last movement **or the last person seen**. The second half keeps someone who stands still tracked: motion lets them fade into its background, the model keeps seeing them and each sighting holds the gate open. The gate starts open, for the motion detector's 20 warm-up frames and 3 s more: it sees nothing while it learns the scene, and someone may already be there. Once nobody moves and nobody is seen for 3 s, the model rests. The limit: someone the model misses for 3 s in a row while they stand still (turned away, half hidden) is lost until they move again — the tracker clears them after `CLEAR_AFTER_S` anyway.

From `ai/`, on a laptop:

```bash
python3 vision/fetch_model.py ~/.cache/sentinel-x/efficientdet_lite0.tflite   # once; the tests use it too
PYTHONPATH=common:vision DETECTOR=tflite TFLITE_MODEL=~/.cache/sentinel-x/efficientdet_lite0.tflite \
  CAMERA_SOURCE=opencv:0 ALERTS_URL=http://127.0.0.1:8080/api/v1/alerts VISION_TOKEN=$(cat /tmp/vision-token) \
  HTTP_HOST=127.0.0.1 .venv/bin/python -m vision
```

The tests run the model on a reference image (NASA's public-domain portrait of Eileen Collins, as scikit-image ships it, fetched once into `~/.cache/sentinel-x/` with its sha256 checked) and on empty images; they are skipped without the model or the runtime.

### Performance on the Pi 4 — benchmark Monday
The main technical risk of Option A, on a Pi 4 that is slower than the Pi 5 the brief assumes: TFLite detection on its CPU runs at a few frames per second. Levers, in order:
1. EfficientDet-Lite0 at its native **320** input (capture stays 640x480); switch to SSD MobileNet if it benchmarks faster.
2. Infer every 2nd–3rd frame (`INFER_EVERY`), and only when the motion detector sees movement (`MOTION_GATE`); the displayed stream stays at full rate. Fewer threads (`TFLITE_THREADS`) leave CPU to the rest of the stack.
3. Fallback allowed by the brief: **OpenCV** motion detection alone (`DETECTOR=motion`).

**`python -m vision.bench`** measures them, with the service's own configuration (`CAMERA_SOURCE`, `DETECTOR`, `TFLITE_*`, `MOTION_GATE`, `INFER_EVERY`; no token needed) and the frames fed as the service's loop takes them: 10 warm-up frames, then `--frames` (200). It prints a Markdown row to paste below. On the Pi, in the container, with the service stopped (one process at a time holds the camera): `docker compose run --rm --entrypoint python3 vision -m vision.bench --machine "Pi 4 4 GB"`; on a laptop, from `ai/`:

```bash
PYTHONPATH=common:vision CAMERA_SOURCE=opencv:/path/video.mp4 DETECTOR=tflite \
  TFLITE_MODEL=~/.cache/sentinel-x/efficientdet_lite0.tflite .venv/bin/python -m vision.bench --machine laptop
```

- **Capture ms:** the capture thread's time per frame, read + shrink to 640x480. A camera's read waits for its next frame, so with a live camera it is about 1000 / its fps; with a video file, the decoding only.
- **Inference ms p50 / p95:** per `detect()` call, preprocessing included; behind the motion gate, a mix of motion-only calls and model runs (**Model runs** counts the latter).
- **Camera fps / processed fps:** the frames the source delivered, and those the loop took, a second. A video file plays at its own frame rate, which caps both: the inference column is the one that says how fast the model is.

**Pi 4 results (#46)** — to fill in on the Pi, camera at 640x480:

| Machine | Source | Detector | Frames | Capture ms p50 / p95 | Inference ms p50 / p95 | Model runs | Camera fps | Processed fps |
|---|---|---|---|---|---|---|---|---|
| Pi 4 | picamera2 640x480 | tflite, 4 threads | | | | | | |
| Pi 4 | picamera2 640x480 | tflite, 4 threads, motion gate | | | | | | |
| Pi 4 | picamera2 640x480 | tflite, 4 threads, every 2 frames | | | | | | |
| Pi 4 | picamera2 640x480 | motion | | | | | | |

**Laptop, for comparison only — not the Pi** (x86_64 Xeon at 2.1 GHz, 4 vCPU, Python 3.13, ai-edge-litert 2.2.0; a synthetic 30 fps 640x480 clip, 20 s: 10 s of an empty yard, then a figure crossing it — motion for the gate, not a person the model recognises):

| Machine | Source | Detector | Frames | Capture ms p50 / p95 | Inference ms p50 / p95 | Model runs | Camera fps | Processed fps |
|---|---|---|---|---|---|---|---|---|
| laptop | opencv:yard.avi 640x480 | tflite, 4 threads | 580 | 1.3 / 1.6 | 10.6 / 13.1 | 580 / 580 | 30.0 | 30.0 |
| laptop | opencv:yard.avi 640x480 | tflite, 4 threads, motion gate | 580 | 1.3 / 1.6 | 12.2 / 15.0 | 371 / 580 | 30.0 | 30.0 |
| laptop | opencv:yard.avi 640x480 | tflite, 4 threads, every 2 frames | 580 | 1.3 / 1.6 | 11.5 / 13.6 | 290 / 290 | 30.0 | 30.0 |
| laptop | opencv:yard.avi 640x480 | tflite, 1 thread | 580 | 1.4 / 1.7 | 21.1 / 28.0 | 580 / 580 | 30.0 | 30.0 |
| laptop | opencv:yard.avi 640x480 | motion | 580 | 1.3 / 1.7 | 2.1 / 3.0 | 580 / 580 | 30.0 | 30.0 |

On the laptop the model takes about 11 ms a frame and the clip's 30 fps caps the rest. The gate adds the motion detector's 2 ms to every frame and spared the model 36 % of them here, where the yard is empty half the time; a real yard is empty most of the time. Expect the Pi 4 to be several times slower on every line.

## Predictive maintenance
- **Live:** subscribe to `sentinel/+/telemetry` over MQTTS (`mosquitto:8883`, own `predictive` MQTT user, broker verified against the team CA) and score a sliding window in memory.
- **Training:** nominal history from the api's SQLite history, opened **read-only** (`mode=ro`, `api-data` volume mounted `:ro`) — see *Capture & training* below.
- **No static thresholds** (`if temp>40` is forbidden). Isolation Forest on an enriched vector: `[temp, humidity, air]` **+ velocity features** `[Δtemp/dt, Δair/dt]` + rolling means.
- Goal: catch the *correlation* — slow temp rise + micro air deviation → predict an incident **before** the critical threshold. Emits a `predictive` Alert with `anomaly_score`.
- Train on **nominal data only**, captured Tuesday (2–4 h). No labelled incidents needed.
- Data quality: the DHT22/MQ-2 sit in their own ventilated compartment, away from the Pi — otherwise the model learns the Pi's inference heat as "thermal drift".

**Without a Sentinel:** `PYTHONPATH=common:predictive .venv/bin/python -m predictive simulate` (from `ai/`, ~3 s) trains on 2 h of synthetic nominal, replays a slow heat + gas drift and prints when the Alert is raised against `THERMAL_WARNING` / `GAS_WARNING` (~43 min ahead), then when it clears.
- **Vector** (`predictive.features`, the same code for training and live): a 120 s window per Sentinel, scored from 20 snapshots spanning ≥ 60 s — `temp`, `humidity`, `air`, `temp_slope`, `air_slope` (least squares, per minute), `temp_mean`, `air_mean`. A snapshot that is invalid, older than or as old as the last one is dropped.
- **Model** (`predictive.model`): `StandardScaler` + `IsolationForest` (200 trees, fixed seed); `anomaly_score` is its 0–1 score. Learned levels: raise ≥ quantile 0.999, clear < quantile 0.99 of **held-out** nominal scores — each 10 min block scored by a forest that never saw it; the forest's scores of its own training windows are too kind and gave a false Alert about once a day. Refuses < 100 vectors; saved with joblib, its format version and scikit-learn version, and refused if either differs.
- **Alert** (`predictive.detector`): `raised` after 5 scores in a row at or above the raise level, `cleared` after 10 in a row under the clear level, a new `alert_id` per episode, `ts` of the snapshot that tipped it; `drivers` as in [`ARCHITECTURE.md`](../docs/ARCHITECTURE.md#alert--sentinelidalert-and-body-of-post-apiv1alerts).
- **Live:** `Model.load(path)`, one `Monitor(model, sentinel)` per Sentinel, `monitor.push(sample_of(payload))` → an Alert to post, or `None`.
- The synthetic room is stationary and bounded (ventilation cycles, drafts, probe noise): the Tuesday capture must cover the demo's conditions likewise, or the model will rightly find them odd.

### The live service — `python -m predictive run` (`predictive.service`)
The image's default command. Configured by its environment, every variable in [`predictive/.env.example`](predictive/.env.example); a missing or invalid one stops it at startup with its name.
- **Broker:** `MQTT_URL` in `mqtts://` only (port 8883 by default), user `MQTT_USERNAME` (`predictive`) / `MQTT_PASSWORD`, the broker verified against `MQTT_CA_FILE` alone, its name included (TLS ≥ 1.2). Subscribes to `sentinel/+/telemetry` each time the connection comes up; retries forever while the broker is away or refuses the login (1 s, doubling up to 30 s), saying why once.
- **Messages:** the Sentinel is the topic's `<id>` (`[\w-]{1,64}`), never the payload's. A foreign topic, a payload over 4 KB or that is not a snapshot (`sample_of`), a snapshot not newer than the last: ignored and counted, the first of each kind logged with its topic, the rest summed up every 5 min.
- **Model:** `MODEL_FILE` (`/model/model.joblib`), checked every `MODEL_POLL_S` (10 s). Without it, the service reads the telemetry, scores none of it and says so (again every 5 min). As soon as it appears, and each time it changes, it is loaded and logged with its range, levels and window, and every Sentinel starts over with a fresh window. A file that cannot be loaded is logged once and skipped: the previous model, if any, keeps scoring. So `docker compose run --rm predictive train …` is enough: the running service takes the new model up by itself.
- **Alerts:** each transition is logged with its score and drivers, and posted through the `AlertClient` with `PREDICTIVE_TOKEN` to `ALERTS_URL`. A new model, or the service stopping, first clears the episodes still raised: nobody else could clear them.
- **SIGTERM / SIGINT:** disconnects, posts what is queued (5 s at most), exits. No secret in any log line.

Against a broker, from `ai/` (with a model saved by `Model.save`, e.g. the Pi's, copied):

```bash
MQTT_URL=mqtts://<pi-ip>:8883 MQTT_PASSWORD=… MQTT_CA_FILE=../infra/secrets/ca.crt \
ALERTS_URL=http://127.0.0.1:8080/api/v1/alerts PREDICTIVE_TOKEN=… MODEL_FILE=model.joblib \
PYTHONPATH=common:predictive .venv/bin/python -m predictive run
```

The image: `docker build -f ai/predictive/Dockerfile ai/` (the context is `ai/`, for `ai/common`); non-root (uid 10001), runs with `read_only` and `cap_drop: ALL`; the model lives on a volume at `/model`.

### Capture & training — Tuesday
`python -m predictive train --from <ISO> --to <ISO>` (`predictive.training`, `predictive.history`) reads the telemetry of the range from `HISTORY_FILE` (default `/history/history.sqlite`, the api's history, the time-scrubber's), opened read-only and while the api writes; `--history <file>` reads another copy, `--jsonl <file>` a capture made away from the Pi (one telemetry payload, Alert or history frame per line). Both ends of the range are included; a time without its zone is refused.
- **Kept:** the telemetry, Sentinel by Sentinel, through the live service's window. **Left out:** the snapshots taken while one of the Sentinel's own Alerts (`gas`, `thermal`, `presence`, `noise`) was active, from its `raised` to the `cleared` of the same `alert_id` — also one raised before `--from`, and to the end of the range if it is never cleared. No window spans such a period, so the levels before and after it make no slope.
- **Refused**, with what to do: a range the api's mock fed (an Alert whose `alert_id` starts with `mock-` in it, or still active at its start), a range with no telemetry, too little nominal (< 100 vectors). Nothing is saved then.
- **Saved** to `MODEL_FILE` (default `/model/model.joblib`, the `predictive-model` volume, out of git), with its range, its number of vectors, its learned levels and its format and scikit-learn versions; the file is replaced in one move, so a running service never reads half of it.

The procedure:
1. Run the stack with the real Sentinel and **`MOCK_FEED` off** (the mock is recorded like a real Sentinel: a range it fed is refused), sensors in their ventilated compartment, the room as it will be for the demo: ventilation, door, people around, the Pi under its usual load. Change nothing during the capture that the demo will not have.
2. Note the start time **in UTC** (`date -u +%FT%TZ`), let it run **2–4 h**, note the end. Don't trigger the Sentinel on purpose: a period under one of its Alerts is left out, so its time is lost to the capture.
3. Train (a few seconds on the Pi), the api still running — a read-only reader needs the `-shm` file only the running api keeps:
   ```bash
   docker compose run --rm predictive train --from 2026-10-13T08:00:00Z --to 2026-10-13T11:00:00Z
   ```
   The `predictive` service, its volumes and environment are wired in the Compose stack (`docker-compose.yml`, [`../infra/README.md`](../infra/README.md#the-ai-services)). Without it, from `ai/`: `PYTHONPATH=common:predictive .venv/bin/python -m predictive train --from … --to … --history <copy of history.sqlite> --model <file>`.
4. Read the summary (here on 4 h of synthetic telemetry, with a 5 min `presence` Alert in it):
   ```
   sentinel-01: 14400 snapshots, 14099 kept, 301 excluded (Alert active), 0 invalid → 13979 vectors
     excluded from 2026-10-06T09:00:00.000Z to 2026-10-06T09:05:00.000Z: presence Alert active
   Trained on 13979 vectors: raise at 0.589, clear under 0.565 (learned quantiles of held-out nominal scores).
   On its own training windows: 0.02% score at or above the raise level, a replay raises 0 predictive Alerts.
   ```
   - *snapshots / kept / excluded / invalid*: what the range held for each Sentinel; ~1 snapshot per second is expected. Many excluded or invalid: look at the Alerts or the Sentinel before trusting the capture.
   - *vectors*: one per kept snapshot once its window is full, the first minute of each run aside.
   - *raise at / clear under*: the learned levels the live service compares the anomaly score to.
   - *on its own training windows*: a sanity check — a share well under 1 % and a replay that raises nothing. A replay that raises on the capture itself means the capture holds an episode that is not nominal: find it in the time-scrubber and train on a range without it.

## Output
Both jobs → `POST /api/v1/alerts` over the **internal Docker network**, using the unified Alert schema in [`../docs/ARCHITECTURE.md`](../docs/ARCHITECTURE.md#alert--sentinelidalert-and-body-of-post-apiv1alerts). Each service sends its own token (`Authorization: Bearer …`, from its `.env`) and may only post its own `kind` (`intrusion` / `predictive`).

### The Alert client — `sentinel_common.alerts`
Both services post through one `AlertClient`: `post()` only queues the Alert, so the detection loop never waits on the network, and a single worker sends the queue in order, so a `cleared` never overtakes its `raised`.

- **Retried** with an exponential backoff (0.5 s, doubling, capped at 8 s, 5 sends at most): a network error, a `5xx`, a `429` after its `Retry-After`. Out of attempts, the Alert is logged and dropped: the next ones still go.
- **Not retried:** any other `4xx` — the Alert itself is wrong. Logged with the api's `message`, then skipped.
- Never through an HTTP proxy, never after a redirect, and the token appears in no log line nor `repr()`.
- `close()` (or leaving the `with`) sends what is queued, for 5 s at most: call it before exiting.

The configuration is the service's: it reads its own variables with `sentinel_common.config`, at startup, so a missing or invalid one stops it with its name — never with a secret's value.

```python
import sys

from sentinel_common.alerts import AlertClient
from sentinel_common.config import ConfigError, env_secret, env_url

try:
    url = env_url("ALERTS_URL", "http://api:8080/api/v1/alerts")
    token = env_secret("VISION_TOKEN")  # predictive: PREDICTIVE_TOKEN
except ConfigError as error:
    sys.exit(f"Invalid configuration: {error}")

with AlertClient(url, token) as alerts:
    ...
    alerts.post(alert)  # returns at once
```

## Develop & test
Product requirements: the AI PRD, issue #67. Layout, one import package per directory:

```
ai/
├── common/       # sentinel_common: the Alert contract mirror, the Alert client — stdlib only, Python 3.11+
├── predictive/   # predictive: the predictive service
└── vision/       # vision: the vision service
```

Everything is tested without a Pi, a camera, a broker or a network, from `ai/`:

```bash
python3 -m venv .venv && .venv/bin/pip install -r requirements-dev.txt
.venv/bin/pytest
```

Every Alert a service emits is checked against `sentinel_common.contract.alert_errors`, the mirror of
`backend/src/contract.ts`: what it refuses, the api refuses with a `400`.

## TODO
Done, without the hardware (PRD #67):
- [x] Alert POST client (with service token) — #68
- [x] Vision inference + `x_norm` extraction — #70, #74
- [x] Annotated MJPEG feed for the dashboard — #73, under `/camera` behind the Operator session (#75)
- [x] MQTTS telemetry subscriber (sliding window) — #72
- [x] Feature engineering + Isolation Forest, the `train` command on the api's history — #69, #71
- [x] `vision` and `predictive` in the Compose stack, their secrets from `infra/setup.sh` — #75

Left, on the hardware:
- [x] ZIF camera capture (Picamera2): the source, the image with the Raspberry Pi apt repository, the Pi 4's device nodes — #46
- [x] The USB webcam in the stack instead: its node found by `plug-and-play.sh`, `CAMERA_SOURCE=opencv:0` by default
- [ ] The image built on the Pi, and the webcam's picture in the dashboard's feed — #46
- [ ] **Latency benchmark (Monday)** on the Pi 4, in [the table above](#performance-on-the-pi-4--benchmark-monday) — #46
- [ ] A person in front of the webcam, seen on the Twin and in the dashboard's feed — #46
- [ ] Tuesday nominal-data capture session (2–4 h, real Sentinel, `MOCK_FEED` off), then `train` on that range — #47
- [ ] Drift demo: a slow rise of heat + a little gas raises the `predictive` Alert before the firmware's `thermal` / `gas` thresholds — #47

> Model weights (`*.tflite`, `*.pt`, `*.onnx`) are gitignored — share via a release or drive. Tokens live in `.env` (gitignored).

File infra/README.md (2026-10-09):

# infra/ — Platform & Network

**Node:** Command Post (Raspberry Pi 4, inside the Enclosure)

Orchestrates the whole server stack on the Pi and owns the isolated table network.

## Plug and play
Step by step, from a blank SD card to the dashboard: [`../docs/INSTALLATION-PI.md`](../docs/INSTALLATION-PI.md).

On a Raspberry Pi 4 with a recent Raspberry Pi OS (64-bit), plugged into Ethernet the first time, with the ESP32 on one of its USB ports:

```bash
git clone https://github.com/ArthurPoncin/sentinel-x.git && cd sentinel-x
infra/plug-and-play.sh X          # X = table number: the Pi becomes 192.168.X.1
```

[`plug-and-play.sh`](plug-and-play.sh) does everything below and more, and can be run again at will (it keeps what exists, `--no-flash` leaves the ESP32 alone):
1. installs Docker, dnsmasq, chrony and PlatformIO, while there is Internet;
2. makes the secrets ([`setup.sh`](setup.sh)) and starts the stack;
3. builds the Sentinel's firmware with this Pi's secrets: no `handover.txt` to carry for the ESP32;
4. turns the Pi's Wi-Fi into the table access point `SentinelX-X` (NetworkManager, 2.4 GHz, WPA2/CCMP, passphrase made once in `infra/secrets/wifi.env`), with DHCP only (dnsmasq: no DNS, no gateway, `sentinel-01` always on `.10`) and the time for the table (chrony: the network has no Internet, and every reading is time-stamped);
5. shows the Command Post's status on the Pi's HDMI screen ([below](#the-status-screen));
6. flashes the ESP32 over USB and waits for its first telemetry snapshot on the broker.

Its images come ready-made: [`.github/workflows/images.yml`](../.github/workflows/images.yml) builds each one for the Pi (linux/arm64, on GitHub's own Arm runners) on every push to `main` and publishes it on GHCR as `ghcr.io/arthurponcin/sentinel-x-<service>:<key>`, the key being that of the code it is built from ([`images.sh`](images.sh): the git trees of its paths, so the same code gives the same key on the CI as on the Pi). `plug-and-play.sh` pulls, all at once, the image whose key matches its checkout and names it as `docker-compose.yml` does; it builds on the Pi only what it cannot pull — code changed on the Pi, a key the CI has not published yet, a package still private — and, offline, keeps the images it has. The packages are private when first published: their owner makes each one public once (*Package settings → Change visibility → Public*). A new path in a Dockerfile's `COPY` goes into its service's paths in `images.sh`, or a stale image could be pulled.

It talks French, through [`ui.sh`](ui.sh): sudo and the Operator password asked first, then 10 numbered steps with a spinner and their time, the commands' output in `~/.local/share/sentinel-x/plug-and-play.log` (its last line shown under the running step), a framed reason and the failed command's last lines when a step fails, a framed summary at the end. Plain lines, without the animation, when its output is not a terminal; `NO_COLOR` turns the colours off.

Everything comes back by itself when the Pi reboots. The manual steps follow, for reference.

Once installed, an update is [`update.sh`](update.sh), with Ethernet plugged in: `git pull`, the images of the new code (pulled or built as above, through [`pull.sh`](pull.sh), which both scripts share), then `docker compose up -d`, which makes again only the containers whose image or settings changed, and a restart of the broker when `mosquitto.conf` changed. No sudo, no table number: the Wi-Fi, the secrets, the status screen and the ESP32 stay as they are, so an SSH session over the table Wi-Fi holds and the hardening stays in place. It does not apply a new firmware, a new broker account or ACL, nor a change to the Pi's own setup or to its hardening: when the pull brought one, it says so at the end, with the command to run (`plug-and-play.sh`, `harden.sh`).

Before the pentest, [`../cyber/harden.sh`](../cyber/harden.sh) closes the Pi down to what the table needs (SSH by key from the Operator laptop only, UFW, Docker's published ports kept to the table Wi-Fi) — [`../cyber/README.md`](../cyber/README.md#hardensh). Run it again after each `plug-and-play.sh`.

## Run the Command Post on the Pi
Everything runs from [`../docker-compose.yml`](../docker-compose.yml). The secrets it needs are made once, on the Pi, by [`setup.sh`](setup.sh), into `infra/secrets/` (git-ignored, never committed).

**1. Prepare the Pi** — while it still has Internet, through Ethernet:

```bash
curl -fsSL https://get.docker.com | sh          # Docker Engine + the compose plugin
sudo usermod -aG docker "$USER" && newgrp docker
git clone https://github.com/ArthurPoncin/sentinel-x.git && cd sentinel-x
```

The repo is public: no SSH key needed to clone or `git pull`. Code changes go through PRs from the laptops; the Pi only pulls.

**2. Make the secrets**, once — `X` is the table number, the Pi is `192.168.X.1`:

```bash
infra/setup.sh X
```

- It asks for the Operator's password (12 characters or more) and makes the team CA, the broker and proxy certificates, one MQTT account per client (`sentinel-01`, `api`, `predictive`), the AI services' tokens and the Operator's password hash.
- Each service gets its own file, read by Compose on the Pi (`env_file`, mode 600): `api.env` (its MQTT password, the Operator's hash, both AI tokens), `vision.env` (`VISION_TOKEN`), `predictive.env` (the `predictive` MQTT password, `PREDICTIVE_TOKEN`) — the same values on both sides, so the api takes the AI services' Alerts and the broker their login.
- What exists is kept: run it again after a `git pull` to pick up a new ACL. An install made before `vision.env` and `predictive.env` gets them on the next run, from `api.env` and `handover.txt`, nothing else made again; only if `handover.txt` no longer holds the `predictive` password is a new one made, in place of the old one in the broker's `passwd`: then `docker compose restart mosquitto`, as the script says. To start over: `sudo rm -rf infra/secrets` (some files belong to the containers' users).
- The proxy certificate is for `192.168.X.1` and for `sentinel-x.local`. The table Wi-Fi has no DNS, and avahi is off once the Pi is hardened: the Operator laptop gets the name from its hosts file (`192.168.X.1 sentinel-x.local`), written by [`operator.sh`](operator.sh). A certificate made before the name is made again by `infra/plug-and-play.sh`, by the same CA.
- `EXTRA_SAN=IP:<ethernet ip> infra/setup.sh X` also puts the Pi's Ethernet address in the HTTPS certificate, to test from the school network.
- **`infra/secrets/handover.txt`** holds what the other teams need: the ESP32's MQTT password, the AI services' tokens. Hand it over out of band (USB key, in person), never in a chat or in git. The firmware also needs `infra/secrets/ca.crt` to verify the broker.

**3. Start the stack:**

```bash
docker compose up -d --build                    # first build: a few minutes on the Pi
docker compose ps                               # api turns (healthy) once it reaches the broker
docker compose logs -f api                      # follow one service
docker compose logs -f vision predictive        # the AI services
MOCK_FEED=true docker compose up -d api         # the scripted scenario, until the Sentinel is there
docker compose up -d api                        # back to the real feed
infra/update.sh                                 # update: git pull, the new images, the containers that changed
```

**4. Open it** from the Operator laptop, on the table Wi-Fi and from its clone of the repo: `infra/operator.sh X <your user on the Pi>` ([`operator.sh`](operator.sh), Linux and macOS; [`operator.ps1`](operator.ps1) on Windows, as administrator) fetches `infra/secrets/ca.crt` over scp, trusts it (the system's store, and Chrome's and Firefox's own lists on Linux) and writes `192.168.X.1 sentinel-x.local` in the hosts file. Then `https://sentinel-x.local/` (or `https://192.168.X.1/`) and log in. From the Pi itself: `curl --cacert infra/secrets/ca.crt https://127.0.0.1/api/v1/auth/check` → `401` until logged in; `https://127.0.0.1/camera` too, the camera feed being for the Operator only.

| Service | Image | Reached at | Runs as |
|---|---|---|---|
| `reverse-proxy` | Caddy ([`caddy/`](caddy/)) | **443** (HTTPS/WSS) → `/api/*` and `/ws` to `api`, `/camera` to `vision` (Operator session checked first), the rest to `dashboard` | `65534`, port 8443 inside |
| `mosquitto` | `eclipse-mosquitto:2.0` ([`mosquitto/`](mosquitto/)) | **8883** (MQTTS) — ESP32 by IP, `api`/`predictive` as `mosquitto:8883` | `1883` |
| `api` | [`../backend/`](../backend/) | `api:8080`, internal only | `node` |
| `dashboard` | [`../dashboard/`](../dashboard/) (static, Caddy) | `dashboard:8080`, internal only | `65534` |
| `vision` | [`../ai/vision/`](../ai/vision/) (Debian's Python 3.11 and OpenCV) | `vision:8000`, internal only; the proxy serves it as `/camera` | `10002`, + the host's `video` group |
| `predictive` | [`../ai/predictive/`](../ai/predictive/) | nothing to reach: it reads the broker, posts to `api` | `10001` |

- Every service: non-root, read-only filesystem, every capability dropped, `no-new-privileges`, log rotation. The `internal` network has no route out; only the proxy and the broker are also on `edge`, where the two published ports are.
- The history (SQLite) lives on the `api-data` volume: it survives `docker compose down`, not `down -v`. There is no `db` container: the history is the api's SQLite file, mounted read-only into `predictive` for its training. The trained model lives on the `predictive-model` volume, likewise.

### The AI services
- **The camera** is a USB webcam. Docker refuses to create a container whose device node is missing on the host, so `vision`'s webcam node is not in `docker-compose.yml` but in [`../docker-compose.camera.yml`](../docker-compose.camera.yml): the stack still starts on a laptop, or on the Pi with the webcam unplugged — `vision` then says `camera down`, on `/health` and in the feed. `plug-and-play.sh` finds the webcam by its name in `/dev/v4l/by-id` (only USB devices have one: any port, never one of the Pi's own video nodes), puts these lines in `.env` when it is there, and takes them out when it is not:
  ```bash
  COMPOSE_FILE=docker-compose.yml:docker-compose.camera.yml    # every docker compose command takes both (and the motor's file, below)
  CAMERA_DEVICE=/dev/v4l/by-id/usb-<the webcam>-video-index0  # /dev/video0 in the container
  ```
  The node only, never `privileged`: the container sees it and nothing else of `/dev`, through the host's `video` group (`group_add`, GID 44 on Debian and Raspberry Pi OS; another one: `VIDEO_GID=$(getent group video | cut -d: -f3)` in `.env`). Another webcam, or the same one plugged in after the stack started: run `plug-and-play.sh <table> --no-flash` again.
- **Which detector.** `DETECTOR` defaults to `tflite`: EfficientDet-Lite0 sees a *person*, its model fetched into the image at build time (sha256 checked). `DETECTOR=motion` in `.env` falls back to OpenCV motion detection. Benchmark on the Pi, the service stopped: `docker compose run --rm --entrypoint python3 vision -m vision.bench` (ai/README.md).
- **The servo** that turns the webcam is optional, and set up apart: [`servo.sh`](servo.sh), once, on the Pi with the servo wired — its signal on **GPIO 18** (pin 12), its ground on the Pi's (pin 14), its **5 V on a supply of its own** with the grounds joined (a servo that stalls draws more than the Pi's 5 V pin gives, and the Pi restarts). It turns the Pi's hardware PWM on for that pin (`dtoverlay=pwm,pin=18,func=2` in `/boot/firmware/config.txt`, one reboot) and installs `sentinel-x-servo.service`, which exports the PWM channel at each boot, before Docker, and gives its `period`, `duty_cycle` and `enable` files to the `gpio` group. With `PAN_DRIVE=pwm` in `.env` — without that line, the motor is the stepper below — `plug-and-play.sh` then finds the channel and adds [`../docker-compose.pan.yml`](../docker-compose.pan.yml) to `COMPOSE_FILE`, with these lines in `.env`:
  ```
  PAN_PWM_CHANNEL=/sys/devices/platform/soc/fe20c000.pwm/pwm/pwmchip0/pwm0   # /pwm in the container
  PAN_GID=<the gpio group>
  ```
  The channel's own directory only, never `privileged` and no capability: the container writes the width of the pulse, the kernel sends it. The file sets `PAN_DRIVE=pwm`: `vision` turns the camera to the person it follows and says how far in each `intrusion` Alert ([`../ai/`](../ai/README.md#the-camera-on-its-servo--pan_drivepwm)). The servo as it is mounted goes in `.env` too, when it differs from the defaults: `PAN_MIN_DEG`, `PAN_MAX_DEG` (its travel either way of where the camera rests), `PAN_MIN_US`, `PAN_MAX_US` (the pulse at each end), `PAN_INVERT`, `PAN_SPEED_DEG_S`, `PAN_HOME_AFTER_S`, `PAN_PATROL_DEG`, `PAN_PATROL_SPEED_DEG_S` (how long it waits before going back to where it rests, and its patrol around it), and `CAMERA_FOV_DEG` for the webcam's field of view; then `docker compose up -d vision`. `docker compose exec vision python3 -c "import urllib.request; print(urllib.request.urlopen('http://127.0.0.1:8000/health').read())"` gives `pan`, in degrees. It needs the person detector: with `DETECTOR=motion`, `vision` leaves the camera fixed and says so in its logs. **Not yet run on the Pi** when this was written: if the container cannot write the channel (`Servo on /pwm unavailable` in `docker compose logs vision`), check the group of the three files (`ls -l /sys/class/pwm/pwmchip0/pwm0/`) against `PAN_GID`.
- **Or a stepper motor** in place of the servo: a 28BYJ-48 on its ULN2003 board, its IN1 to IN4 on **GPIO 6, 13, 19, 26** (pins 31, 33, 35, 37), its − on the ground beside them (pin 39), its + on 5 V (pin 4: it draws some 200 mA, steadily, where a servo that stalls asks for more). Nothing to install: the GPIO chip is always there and does not say whether a board is wired to it, so `plug-and-play.sh` adds [`../docker-compose.stepper.yml`](../docker-compose.stepper.yml) to `COMPOSE_FILE` whenever it is, with `PAN_GPIO_GID=<the gpio group>` in `.env`, and disables the servo's unit if there is one. A camera left fixed says so in `.env`: `PAN_DRIVE=none` (without a board and without that line, `vision` believes it turns the camera). `DETECTOR=motion` leaves it fixed too. The chip's device node only (`devices: /dev/gpiochip0`), never `privileged` and no capability: the file sets `PAN_DRIVE=stepper` and `PAN_SPEED_DEG_S` to 40, what the motor keeps up with ([`../ai/`](../ai/README.md#the-camera-on-a-stepper-motor--pan_drivestepper)). Other GPIOs: `PAN_STEPPER_PINS=IN1,IN2,IN3,IN4` in `.env`. The motor says nothing of where it is: turn the camera by hand to look straight ahead before each start of `vision`, or by command, the service stopped: `docker compose stop vision`, `docker compose run --rm --entrypoint python3 vision -m vision.pan 30` (30° toward the right of its image, `-30` the other way: also the way to see that the board is wired), `docker compose start vision`. **Not yet run on the Pi** when this was written: `docker compose logs vision` says `Stepper on /dev/gpiochip0, GPIO 6, 13, 19, 26, ready`, or why not.
- **Which camera.** `CAMERA_SOURCE` defaults to `opencv:0`, the webcam that `docker-compose.camera.yml` puts at `/dev/video0` in the container. To replay a video instead: put `CAMERA_SOURCE=opencv:/path/in/the/container.mp4` in `.env` and mount the file in a compose override. The image still carries Picamera2 (`CAMERA_SOURCE=picamera2`), but the stack no longer gives it the ZIF camera's nodes: the team's ZIF camera was detected by the Pi and never sent a frame (`Camera frontend has timed out`).
- **The feed.** The proxy asks the api first (`forward_auth` on `GET /api/v1/auth/check`): without the Operator's session, `401`; with it, `/camera` goes to `vision` with the prefix stripped, query kept (`/camera?attempt=1` → `/?attempt=1`), each picture passed on as it comes (`flush_interval -1`).
- **Training the predictive model**, on a range of the history recorded with `MOCK_FEED` off, the api running (a read-only reader of its WAL-mode SQLite file needs the `-shm` file only the api keeps) — the procedure is in [`../ai/README.md`](../ai/README.md#capture--training--tuesday):
  ```bash
  docker compose run --rm predictive train --from 2026-10-13T08:00:00Z --to 2026-10-13T11:00:00Z
  ```
  It reads `api-data` mounted `:ro` at `/history` (the api writes it as `node`, files `0644`: readable by `predictive`'s uid 10001, writable by the api only) and writes `/model/model.joblib` on `predictive-model`; the running `predictive` takes the new model up by itself, no restart.

## Container stack (Docker-Compose, on the Pi)
`reverse-proxy` · `mosquitto` · `api` · `dashboard` · `vision` · `predictive` (the history: SQLite on the `api-data` volume) — roles in [`../docs/ARCHITECTURE.md`](../docs/ARCHITECTURE.md#container-stack-docker-compose-on-the-pi).
Resilient & reproducible — `docker compose up` brings the Command Post online.

- **Only `reverse-proxy` (443) and `mosquitto` (8883) publish ports.** Everything else talks over the internal Compose network.
- Every service gets the shared hardening + log-rotation block (rotation keeps a message flood from filling the SD card):

```yaml
x-hardened: &hardened
  restart: unless-stopped
  security_opt: ["no-new-privileges:true"]
  cap_drop: [ALL]
  logging:
    driver: json-file
    options: { max-size: "10m", max-file: "3" }
```

- Mosquitto listens on **8883 only** (TLS), no anonymous access. The explicit `listener` binds every interface of the container (Mosquitto 2.x is localhost-only without one): the ESP32 reaches it through the published port, `api` and `predictive` as `mosquitto:8883` on the Compose network. ACL content in [`../docs/ARCHITECTURE.md`](../docs/ARCHITECTURE.md#security-model-binding-for-every-workstream):

```conf
# all interfaces: table Wi-Fi (published port) + Compose network (mosquitto:8883)
listener 8883
cafile   /mosquitto/config/certs/ca.crt
certfile /mosquitto/config/certs/broker.crt
keyfile  /mosquitto/config/certs/broker.key
tls_version tlsv1.2
allow_anonymous false
password_file /mosquitto/config/passwd
acl_file      /mosquitto/config/acl
max_packet_size 4096
```

## The status screen
The Pi's HDMI screen (800×480, either micro-HDMI port) shows what the brief's OLED showed on the Sentinel, and more: the table Wi-Fi and whether its access point is up, the dashboard's address, the Sentinel (`EN LIGNE`, `SUR LE WI-FI`, `MUET`, `ABSENT`), its last readings and raised Alerts, the webcam and the containers. Redrawn every second by [`screen.py`](screen.py), the Pi OS's Python and `python3-paho-mqtt`, on the console in large Terminus letters, without a desktop.
- **Where it reads:** the broker, with its own MQTT account `screen` (made by `setup.sh`, in `infra/secrets/screen.env`), which may only read `sentinel/+/telemetry` and `sentinel/+/alert`; the DHCP leases, NetworkManager and `docker ps` with the user's own rights. The `intrusion` and `predictive` Alerts go to the api, not to the broker: they are on the dashboard only. Text from the network is stripped of control characters before it reaches the console.
- **How it runs:** the `sentinel-x-screen` systemd unit, as the user, on `tty1` in place of its login prompt (`getty@tty1` disabled; ctrl+alt+F2 gives one); its errors in `journalctl -u sentinel-x-screen`.
- **A black screen:** `video=HDMI-A-2:800x480M@60D` at the end of `/boot/firmware/cmdline.txt` forces the second port on, at 800×480.

## Network topology
- The **Pi is the Wi-Fi access point** (hostapd, WPA2-PSK CCMP) with DHCP reservations (dnsmasq) for **`192.168.X.0/24`** — IP plan in [`../docs/ARCHITECTURE.md`](../docs/ARCHITECTURE.md#network-topology).
- The **Sentinel (ESP32)** and the **Operator laptop** join that Wi-Fi.
- No route/NAT to other networks; the Pi's Ethernet is for setup only — **pull Docker images and Python packages before going isolated**.
- No interference with neighboring tables (own SSID, own channel if possible).

## TODO
- [x] `docker-compose.yml` + `setup.sh` (secrets) — `reverse-proxy`, `mosquitto`, `api`, `dashboard`, `vision`, `predictive`
- [x] Mosquitto config (TLS + ACL, with Cyber)
- [ ] DB + volumes (history on the `api-data` volume for now; separate `db` to decide)
- [x] Wi-Fi AP + DHCP + time server: `plug-and-play.sh`
- [ ] IP plan / network schema for the report
- [ ] Pre-pull images, test a full cold boot offline

> Deliverable: the **network schema** for the engineering report.

## MCO monitoring
On the Pi itself, the HDMI status screen shows the containers' state ([above](#the-status-screen)). The brief lists MCO monitoring under the Cyber pillar: show `docker stats` (CPU/RAM), container health, the MQTT message rate and the log rotation in the engineering report.

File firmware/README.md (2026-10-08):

# firmware/ — Edge / IoT (the Sentinel)

**Node:** Sentinel · **MCU:** ESP32 · **Language:** C++ (PlatformIO)

Firmware for the Sentinel: reads the probes, drives the Alarm, **decides its own local Alerts**, and streams secure telemetry to the Command Post (the Pi in the same Enclosure).

## Hardware (committed core)
- **MCU:** ESP32 DevKitC V4 by AZ-Delivery (ESP32-WROOM-32, 38 pins; Wi-Fi 2.4 GHz to the Pi's access point) — ESP8266 deviation justified in [`../docs/ARCHITECTURE.md`](../docs/ARCHITECTURE.md#deviations-to-validate-with-the-coach-monday)
- **Probes:** DHT22 (temp/humidity), MQ-2 (gas — 5 V heater; its analog output needs a divider to stay under 3.3 V), PIR HC-SR501 (presence), CZN-15E sound sensor (digital output only: HIGH/LOW against the threshold set by its potentiometer; the firmware samples it fast and reports the share of the cycle that was loud). Analog probes go on ADC1 pins: ADC2 is unusable while Wi-Fi is on.
- **Display:** none on the ESP32. The status screen is the Pi's HDMI screen ([`../infra/README.md`](../infra/README.md#the-status-screen)): it shows whether the Sentinel is online, its readings and its raised Alerts. Why it is not online, the serial monitor says
- **Alarm:** a passive speaker (4–8 Ω) between IO25 and GND, through **100 Ω or more**: about 30 mA, what a pin may give. Or the buzzer, straight between IO25 and GND, louder for the same current. The firmware plays a square wave on it: the siren, a tune of 523 to 1397 Hz. **Never the speaker on 5V**: through IO25 it is a short circuit of the 5 V rail, which then fails everything on it, and the pin with it. Louder still through an NPN transistor (2N2222, BC547): IO25 → 1 kΩ → base, emitter → GND, collector → the speaker's black wire, its red wire → 47 Ω → 5 V

## Responsibilities
- Cadenced probe sampling → one **telemetry snapshot** per cycle, published over **MQTTS**.
- **Own its Alerts** (`gas`, `thermal`, `presence`, `noise`) with threshold **hysteresis** — one Alert per transition, no flapping.
- **Fire the Alarm locally and immediately** on a critical condition — even if the Command Post is down (this is what makes the Sentinel *autonomous*).
- Subscribe to actuator commands from the API. The contract's actuator is still called `buzzer`: it drives the speaker.

## Security
- MQTTS on port 8883 only; **broker certificate verified against the team CA** (`setCACert`) — never `setInsecure()`.
- Own MQTT credentials (`sentinel-01`). The broker ACL only lets it publish `sentinel/sentinel-01/{telemetry,alert}` and read `command/sentinel-01/actuator`.

## Build and flash
**Plug and play:** plug the ESP32 into a USB port of the Pi, then on the Pi run [`../infra/plug-and-play.sh`](../infra/plug-and-play.sh) `<table>`. It writes `include/secrets.h` from the Pi's own `infra/secrets/` (the credentials never leave the Command Post), builds the firmware and flashes it.

By hand, from a laptop with PlatformIO: copy `include/secrets.example.h` to `include/secrets.h` (git-ignored), fill it from `infra/secrets/handover.txt` and `infra/secrets/ca.crt`, then `pio run -t upload` and `pio device monitor`.

| File | Role |
|---|---|
| `include/pins.h` | GPIOs, as on the wiring diagram: [`../docs/cablage/esp32.html`](../docs/cablage/esp32.html), the Pi's in [`raspberry-pi.html`](../docs/cablage/raspberry-pi.html) |
| `include/config.h` | cycle, thresholds, hysteresis, warm-ups: **calibrate here** |
| `src/probes.*` | DHT22, MQ-2 (millivolts at IO34, 16-sample average, on the ADC's fine 0–1 V range below 0.9 V), PIR, sound share (sampled every ms on an esp_timer: a 50 ms window is loud past 2 ms of sound) |
| `src/alerts.*` | one state machine per kind; a severity change is raised again on the same `alert_id` |
| `src/speaker.*` | the Alarm: siren (the "Axel F" riff of Crazy Frog as a square wave, 523 to 1397 Hz, looping; played on an esp_timer every 5 ms, so a TLS reconnection holding the loop does not stretch it) while an Alert is critical; `on` (steady 2600 Hz) / `pattern` (siren) / `off` from the Operator (`off` silences until the next critical) |
| `src/uplink.*` | Wi-Fi (hostname `sentinel-01`), time from the Pi, MQTTS with the team CA, commands |
| `src/main.cpp` | one cycle per second: read, decide, sound, publish, and a line on the serial monitor |

**What to expect:** a short beep from the speaker at boot, then the Pi's HDMI screen shows the Sentinel `EN LIGNE`. Until then, the serial monitor (`pio device monitor`) says what it waits for, a line a second: `T=… H=… air=… pir=… son=… | wifi=… heure=… broker=… <problem>`, the problem being `Wi-Fi...` or `MQTT: …` (TLS/network, password) until the broker is reached. Telemetry starts once the DHT22 has answered and the Pi gave the time: the contract wants every reading and a real `ts`. The MQ-2 and the PIR raise no Alert during their first minute (warm-up). If the sound sensor already hears sound at boot, the serial monitor says so: its screw is set too sensitive. The settings of the three probes (screws, jumper, the MQ-2 test with a lighter) are under « Réglages » in [`../docs/cablage/esp32.html`](../docs/cablage/esp32.html). Alert transitions made while the broker is unreachable are queued (16), and every raised Alert is sent again on reconnection.

## Contract
Telemetry, Alert and command schemas + topics: [`../docs/ARCHITECTURE.md`](../docs/ARCHITECTURE.md#json-schemas-the-contract--lock-monday-change-only-by-team-agreement). Lock Monday.

## TODO
- [x] Breadboard wiring diagram
- [x] Probe read loop, telemetry snapshot, Alert state machine (hysteresis), autonomous Alarm
- [x] MQTTS connection with team CA cert + MQTT credentials, actuator commands
- [x] The Alarm on a speaker, in place of the buzzer
- [ ] Calibrate the thresholds in `include/config.h` on the real kit (MQ-2 in clean air, a clap, a hand on the DHT22)

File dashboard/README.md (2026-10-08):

# dashboard/ — Web UI & 3D Digital Twin

**Node:** served by the Command Post (Pi) through the reverse proxy (HTTPS/WSS), rendered in the Operator's browser · **Stack:** Vite + React + TypeScript, Tailwind CSS v4 + [shadcn/ui](https://ui.shadcn.com/docs/components) (Recharts for the charts), react-three-fiber (Three.js) for the Twin

The face of Sentinel-X and our **"wow" centerpiece**. See [`../docs/DIGITAL-TWIN.md`](../docs/DIGITAL-TWIN.md).

**One app, two screens on the same live feed:** `/` is the Operator's dashboard, `/twin` the Digital Twin (lazy-loaded, so three.js only loads there). For the demo, open each in its own window. One origin, one container, one Operator session, as in [`../docs/ARCHITECTURE.md`](../docs/ARCHITECTURE.md).

## Must have (from the brief)
- Real-time environmental curves.
- Logical box status.
- Live camera feed — the annotated MJPEG stream served by the `vision` service.
- Reactive control panel to trigger the actuator (buzzer) remotely — `POST /api/v1/commands`.

## Security
- **Operator login** screen; every view, the WebSocket (`wss://`) and the camera feed sit behind the session. A session that ends brings the login screen back — see [Operator session](#operator-session--featuresauth). In the control room's look: a grid floor, the perimeter radar, the Enclosure's hexagon turning faster while the Command Post checks, red and a shake on a refusal, "Accès autorisé" before the dashboard; whether the channel is encrypted (HTTPS) is read from the page, never claimed. Still with reduced motion. Screenshots in [`../docs/dashboard/`](../docs/dashboard/).
- No token or secret in the front-end bundle.

## Our extra — the Digital Twin
- Live 3D replica of the **Outpost** reacting to the real WebSocket event stream.
- **Intruder**: a human figurine in hologram, stood inside the fence from the `intrusion` Alert's `x_norm` (where across the camera's image), `h_norm` (how tall in it: how near) and `pan` (how far the camera is turned), framed by detection brackets and labelled with the vision model's `confidence`: « PERSONNE · 88 % ». It walks to where the camera sees it next, turned the way it goes: in toward the Enclosure as the real person comes nearer. Each other person the camera sees (`others`) has a figurine of their own, five at most. A thin line ties the head of each to the lens, one a person. Once someone is no longer seen, the hollow outline of their figurine stays for about 5 s where it last stood: the last known position, one for each person the camera saw.
- **Camera field**: a translucent volume from the lens on the Enclosure's front down to the arc of the fence it watches, faint at rest, lit on an `intrusion`. It turns with the real camera, which a servo turns to whom it follows.
- **Perimeter**: a chain-link fence under a strand of barbed wire, its gate closed, which opens for as long as an intrusion goes on. The camera's field, the intruder and the presence's sweep read through it.
- **Component pulse** on a `predictive` anomaly; sound ripples on `noise`.
- **The link, seen**: an antenna on the Enclosure sends an impulse of white light for each frame of telemetry received, and a padlock reads « WSS » by it when the live feed really is encrypted, never otherwise.
- **`Status`** floods the twin in its color as it rises, then stays on its ring, its rim light and the Enclosure (`nominal`/`elevated`/`critical`).
- **Time-scrubber** replays a past Incident second by second, labelled REPLAY — demo insurance (#15).
- **Scenario mode** plays the scripted reference scenario on demand, network or not (#15).

## Run it
Node ≥ 22. Start the mock feed first, then the app:

```bash
# terminal 1 — the Command Post API playing its scripted scenario (gas leak, clap, intruder)
cd backend && npm install && OPERATOR_AUTH=off MOCK_FEED=true HISTORY_FILE=:memory: npm run dev

# terminal 2 — the app on http://localhost:5173 (/ and /twin)
cd dashboard && npm install && npm run dev

npm test            # store, feed client, config, gas level, heat level, scene mapper, site plan, steam, haze, Alarm,
                    # fades, escalation flash, pulse, presence sweep, noise wave, the link's impulses, automatic orbit, pixel ratio, framing,
                    # the camera's field, the intruder's track and last known position, walk cycle and figurine,
                    # its detection's label and frame, the camera's turn to an Alert,
                    # Incidents, replay, scenario, Incidents client, the Twin on a replay
npm run build       # typecheck + production bundle in dist/
npm run smoke       # smoke-render of that bundle, on the mock feed — see below
```

**Smoke-render** (#16) — `npm run build && npm run smoke` opens `/` and `/twin` of the production bundle in a headless Chromium and fails on any runtime error: an uncaught exception, an error on the console, the feed not live, the Status or the Readings missing, the Twin without a WebGL context. It starts what it needs itself, on ports of its own (`playwright.config.ts`): the API from `../backend` on its mock feed (`npm install` there first) and `vite preview`, pointed at it by `BACKEND_URL`. The Twin is rendered in software, as on a CI runner. The browser: `npx playwright install chromium` once, or `SMOKE_BROWSER=/path/to/chrome` for one already on the machine. The tests are in [`smoke/`](smoke/).

**CI** — [`.github/workflows/ci.yml`](../.github/workflows/ci.yml), on every pull request and on `main`: the backend's typecheck and tests (the contract the front imports), then here `npm test`, `npm run build` and the smoke-render; and a check that nothing `.gitignore` lists as a secret is tracked.

**Filming the Twin for the teaser** — open `/twin?capture` in a vertical 9:16 window (1080 × 1920) and record the screen while the scenario plays: the Twin alone on black, no interface, on the same feed. See [capture mode](#digital-twin--featurestwin).

The app always talks to its **own origin** (`/ws`, `/api`): the Vite dev server proxies them to `BACKEND_URL`, the reverse proxy does it on the Pi. Mock or live is the backend's setting, the front never changes.

| Variable | Default | Purpose |
|---|---|---|
| `BACKEND_URL` | `http://127.0.0.1:8080` | Command Post API that `/ws` and `/api` are proxied to in `dev` and `preview` (e.g. the Pi's address). Set it in `.env` (see `.env.example`). |
| `CAMERA_URL` | — | The `vision` service's MJPEG stream that `/camera` is proxied to in `dev` and `preview`. Unset: the camera panel shows "unavailable" and retries every 5 s. |

Run the backend with `OPERATOR_AUTH=on` (and an `OPERATOR_PASSWORD_HASH`) to get the login screen; with `OPERATOR_AUTH=off` the app goes straight in.

## Structure — feature-driven

```
src/
├── main.tsx
├── app/                     # composition only: shell, router, routes
│   ├── app.tsx              # AuthGate + LiveFeedProvider + router
│   ├── router.tsx           # /  and  /twin (lazy)
│   ├── layout.tsx
│   └── routes/              # operator.tsx, twin.tsx — assemble features, no logic
├── features/
│   ├── live-feed/           # #10 — the socket, the store, the hook
│   │   ├── api/             # connectFeed(): WebSocket client, backoff, drops bad frames
│   │   ├── stores/          # apply(state, event): pure reducer + tiny external store · stateAfter(frames)
│   │   ├── hooks/           # useLiveFeed(selector)
│   │   ├── components/      # LiveFeedProvider, ConnectionIndicator
│   │   └── index.ts         # the feature's public API
│   ├── auth/                # #48 — AuthGate (login screen until a session exists, and again once it is gone)
│   │                        # useSignOut(), useSessionCheck() · afterCheck(session, answer): pure
│   ├── status/              # StatusCard, StatusBadge — the Status the backend computes
│   ├── telemetry/           # #21 #11 — ReadingTiles, Gas / Climate / Sound charts, toSeries()
│   ├── alerts/              # #11 — ActiveAlerts, AlertLog (+ filters: filterLog()), AlertToasts
│   ├── incidents/           # ThreatOverview, IncidentTable, useIncidents() on GET /api/v1/incidents
│   ├── camera/              # #14 — CameraPanel on /camera, intruder marker from x_norm
│   ├── actuators/           # #14 — ActuatorPanel, POST /api/v1/commands
│   ├── replay/              # #15 — the time-scrubber and scenario mode
│   │   ├── api/             # fetchIncidents(), fetchIncidentReplay(id): the Command Post's recorded Incidents
│   │   ├── hooks/           # usePlayer(): second by second · useRecordedIncidents(key)
│   │   ├── components/      # TimeScrubber: the LIVE/REPLAY label and the scrubber, over the Twin
│   │   ├── utils/           # incidents(history) · replayOf(history, incident) · framesAt(replay, t)
│   │   │                    # withStatus(frames) · scenario(start), scenarioFrames(start) · labels
│   │   └── index.ts
│   └── twin/                # #20, #12, #30, #31, #32, #33, #40, #13, #36, #34, #35, #37, #23, #38, #91, #92, #93, #94, #96, #95, #97, #98, #99, #101, #102, #103 — the Outpost as a maquette, on its studio stage
│       ├── components/      # OutpostTwin: the scene, drawn from SceneProps · Enclosure · OrbitCamera · Halo
│       │                    # Socle · PowerPlant · Perimeter · Steam: the site, drawn from SITE
│       │                    # ChainLinkMaterial: the fence's mesh and the gate's, drawn by their material · inDiamonds
│       │                    # Signage: its no-entry signs, the tank's danger zone and pictogram, the site's name
│       │                    # Rocks: the rocks around the site, in instances · Dust: the motes adrift over it
│       │                    # Renewables: the solar field, in instances, the wind turbine and the batteries
│       │                    # Haze: the gas around the pipe · VapourMaterial: what steam and haze are made of
│       │                    # HeatShimmer: the hot air above the hall · NoiseWaves: a clap's wave over the socle
│       │                    # Antenna: the Enclosure's antenna, its impulses and the padlock by it
│       │                    # Intruder: a hologram figurine for each person the camera sees, inside the fence, in its
│       │                    # detection's brackets, the one it follows tied to its lens, and the outline that one leaves
│       │                    # LabelCard: a signal's label, a card that faces the camera
│       │                    # Box · Turned: the bevelled volumes it is built from · boxShape, turnedShape: their shapes · palette
│       ├── hooks/           # usePixelRatio(element) · useFade(target), useColorFade(color) · useSweep(present)
│       │                    # useWaves(frames) · useStatusLight(level, neutral) · useFraming(anchor, frames)
│       │                    # useImpulses(frames, live)
│       ├── utils/           # toScene(state): the scene's props, pure · gasLevel(air), heatLevel(temp): 0–1
│       │                    # SITE: the ground plan · lensPoint(), lensHeight() · fencePosts() · bearingTo(from, to)
│       │                    # sightBearing(xNorm, pan), watchedPoint(xNorm, pan): where the camera looks, turned or not
│       │                    # standingSpan(bearing), standingPoint(xNorm, pan, hNorm): where someone it sees stands
│       │                    # panToward(shown, pan, elapsed): the camera's pan as it is drawn
│       │                    # bearingAlongFence(point, way): the way to face to walk along it · gatePoint()
│       │                    # fenceLength() · meshCell(): a diamond of the mesh · barbedHeight(), fenceBarbs(): the barbed
│       │                    # wire · gateLine(): the closed gate's line and the opening its leaves fit in
│       │                    # gateSigns(), dangerZone(), hallSign(): where the signage is
│       │                    # hallDoor() · track(): the track's two stretches · fromPath(point, path) · rocks():
│       │                    # the rocks, drawn from a seed · DUST, moteAt(index, seconds): a mote of dust's drift
│       │                    # solarPanels(): where each solar panel stands · panelGround(): the ground one takes
│       │                    # cameraField(steps), fieldBase(field), fieldWalls(field): the camera's field, a volume
│       │                    # alongPipe(share) · puffAt(age): a puff of steam's life · wispAt(age): a wisp
│       │                    # of haze's · blink(t), arcsAt(t): the Alarm · ENCLOSURE_PARTS, ENCLOSURE_SHAPE
│       │                    # autoOrbitSpeed(touch, now), resumeRamp(elapsed) · pixelRatio(density, width, height)
│       │                    # newlyRaised(seen, frames), shortestTurn(from, to), cameraTurn(framing, azimuth, touch, now):
│       │                    # the camera's turn to an Alert
│       │                    # wholeStageDistance(aspect) · fadeTo(fade, to, now), fadeValue(fade, now)
│       │                    # statusShare(from, to, elapsed): the Status's share of the light as it rises
│       │                    # lightTo(light, level, now), lightShares(light, now), lit(shares, neutral, colors)
│       │                    # DRIVER_PROBES: driver → Probe · pulse(t): a drifting Probe's beat
│       │                    # sweepsAt(sweeps, present, now), lapAt(sweeps, now): the fence's sweeps on a presence
│       │                    # sweepGlow(place, lap) · domeFlash(lap)
│       │                    # framesSince(seen, frames), clapsIn(frames), wavesAt(waves, claps, now): the waves a
│       │                    # clap sends · waveShape(elapsed, amplitude): a wave's radius, width and glow
│       │                    # telemetryIn(frames), impulsesAt(impulses, received, live, now): the impulses the
│       │                    # telemetry sends from the antenna · impulseShape(elapsed): its height, radius and glow
│       │                    # trackAt(track, seen, elapsed): a figurine's track, walking to where its person was seen
│       │                    # lastKnown(track): the last known position · figurineLevel(track), marksLevel(track)
│       │                    # tracksAt(tracks, intrusion, elapsed): a track for each person, and those going out
│       │                    # walkPhase(walked), walkCycle(phase, share): its walk cycle · turnedTo(from, to, share)
│       │                    # FIGURE: the figurine's plan · figureHeight(), headHeight() · sweptTo(age): its sweep
│       │                    # detectionLabel(confidence) · detectionFrame(), brackets(): the detection's frame
│       └── index.ts
└── shared/
    ├── contract/            # re-exports backend/src/contract.ts — never redeclare a schema
    ├── config/              # feedUrl(), feedEncrypted() · captureMode() · STATUS_COLORS
    ├── api/                 # getJson / postJson on the app's own origin · onUnauthorized(listener): a 401
    ├── lib/                 # cn(), French labels, Status/severity colors, fr-FR formats · paginate(), inOrder()
    ├── components/          # LevelBadge: the outline badge with a colored dot · Pager, SortByTime
    ├── hooks/               # use-mobile (shadcn sidebar)
    └── ui/                  # shadcn/ui components (components.json points the CLI here)
```

**Rules**
- A feature owns everything it needs (`api/`, `stores/`, `hooks/`, `components/`, `utils/`… only the folders it uses).
- Import a feature through its `index.ts` only (`@/features/live-feed`), never its folders.
- Features don't import each other; `app/routes` composes them. `shared/` imports nothing from `features/` or `app/`.
- Logic goes in pure functions next to their tests (`*.test.ts`), so it is tested without a browser; components stay thin.
- Imports use the `@/` alias for `src/`.

- UI building blocks come from shadcn/ui: `npx shadcn@latest add <component>` writes them to `src/shared/ui/` (check that its imports say `@/shared/lib/utils`). No icon library: a state is said with a colored `●` and words, a trend with `▲` / `▼` — the top bar's `● En direct` sets the tone. A shadcn component added later comes with lucide icons (still installed: `ui/` uses it internally): swap them for that. The theme is shadcn's neutral one, dark only, in `app/styles.css`; `nominal` / `elevated` / `critical` are Tailwind colors too (`text-critical`, `bg-nominal`…), kept to dots and figures.
- The UI text is in French (the Operator and the jury are); code, comments and docs stay in English. Labels shared by several features live in `shared/lib/labels.ts`.
- `app/` holds the shell (`layout.tsx`): the original top bar across the window — `☰`, `Sentinel-X`, `Operator`, `Digital Twin`, `● Live`, its words in English — and under it the shadcn sidebar (`app-sidebar.tsx`), with the two surfaces and the sign-out.
- The shell is exactly the window's height and only the page scrolls inside it (`[data-scroll=page]`): the top bar and the sidebar never move, and "Se déconnecter" stays in sight on both screens.
- The sidebar folds away: the top bar's ☰ (or Ctrl+B) hides it and gives the page its room, and the choice survives a reload (`sidebarOpenFrom(document.cookie)` reads shadcn's `sidebar_state` cookie back). Under 768 px it is a drawer that a choice closes, and the top bar keeps only ☰, the brand and the feed.
- Responsive down to a 390 px phone: the Alert log's filters stack in two columns; on a phone the Alert log puts the state under the Alert's name and the Incidents put the outcome under the start, rather than scroll sideways; the pager drops its words.

**Features to come**

| Feature folder | Tickets | On |
|---|---|---|
| `features/telemetry` | #21 gas curve, #11 every curve | `/` |
| `features/status` · `features/alerts` | #11 Status badge, active Alerts | `/` |
| `features/camera` · `features/actuators` | #14 camera feed, actuator panel | `/` |

## Live feed — `features/live-feed`

```tsx
import { useLiveFeed } from '@/features/live-feed'

const status = useLiveFeed((state) => state.status)                  // 'nominal' | 'elevated' | 'critical'
const telemetry = useLiveFeed((state) => state.latestTelemetry)      // last snapshot, or null
const alerts = useLiveFeed((state) => state.activeAlerts)            // raised, not cleared yet
const history = useLiveFeed((state) => state.history)                // every frame, oldest first (last 1000)
```

- Select a state field as is; derive anything else with `useMemo` (a selector returning a new array each call loops).
- The Status comes from the Command Post: the front never recomputes it on the live feed. A replay is the one exception: the history keeps no Status, so `features/replay` works it out from the replayed Alerts by the Command Post's rule.
- On every (re)connection the backend sends its snapshot (current Status + latest telemetry) and the active Alerts start over, since some may have cleared while the socket was down.
- `connection` is the socket as it is now (`connecting`, `open`, `closed`), `connectedOnce` whether it has ever been open. Together they tell a signal lost (not open any more) from a first connection still being tried.
- Types come from `@/shared/contract`: `Telemetry`, `Alert`, `Status`, `Frame`…
- The Status colors are defined once, in `shared/config/status-colors.ts` (`STATUS_COLORS`). `main.tsx` hands them to the stylesheet as `--nominal`, `--elevated` and `--critical`; the Twin lights its scene with the same.

## Operator session — `features/auth`

```tsx
import { AuthGate, useSessionCheck, useSignOut } from '@/features/auth'

<AuthGate>{/* the login screen until there is a session: nothing below mounts without one */}</AuthGate>
const signOut = useSignOut()             // POST /api/v1/auth/logout, then the login screen
const checkSession = useSessionCheck()   // asks GET /api/v1/auth/check again
```

- **At load**, `GET /api/v1/auth/check`: `204` → the app, anything else → the login screen, on `/` as on `/twin`. `POST /api/v1/auth/login`: `204` lets in and the feed opens; `401` « Mot de passe incorrect. », `429` « Trop de tentatives. Patientez une minute. » (5 tries a minute), no answer « Le poste de commande est injoignable. ». **Se déconnecter**, at the foot of the sidebar, signs out.
- **A session that ends** (#48) — after 12 h, or when the API restarts (it keeps its sessions in memory) — brings the login screen back, and everything under the gate stops with it: the feed no longer retries. Two things say the session is gone:
  - **the feed going down.** A socket that closes does not say why, so `app.tsx` asks for the session again each time (`LiveFeedProvider`'s `onDown` → `useSessionCheck()`). `401` → the login screen. `204`, or no answer at all (the Command Post is out of reach, or restarting behind its proxy) → still in: the Twin says "Signal lost" and the feed keeps retrying. `afterCheck(session, answer)` is that rule, pure and tested.
  - **any call the API answers `401`** (`onUnauthorized` in `shared/api/http.ts`): the Incidents asked for every 15 s on `/`, a command.
- **Not covered** — a socket already open outlives its session: the API checks the session when the socket opens, not after. On `/twin`, where nothing else is asked through `shared/api`, the login screen comes back when that socket drops.
- With `OPERATOR_AUTH=off` the check always answers `204`: nothing changes in development.
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

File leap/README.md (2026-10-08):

# leap/ — hand bridge (Leap Motion Controller → dashboard)

The Operator's hands over a **Leap Motion Controller**, sent to the dashboard open on the same machine. It is an
extra on the Operator's laptop: nothing of it runs in the Enclosure, and the dashboard works the same without it.

```
Leap Motion Controller ─USB→ Ultraleap tracking service ─LeapC→ this bridge ─ws://127.0.0.1:6438→ dashboard
```

## What the hands do

Switch it on in the dashboard's side menu: **Commande gestuelle : activée**. The top bar then says what the sensor
sees and what the hand does.

| Gesture | What it does |
|---|---|
| Flat hand over the sensor, palm down | Steers the Digital Twin's camera: to the side turns round the Outpost, pushed away or pulled back tilts, lowered or raised zooms. Still at the middle, about 20 cm above the sensor. |
| Fist | Holds the camera where it is. During a replay, held to the right or the left, it winds the time-scrubber forward or back. |
| Thumb up, held 1.2 s | Silences the Alarm (the actuator panel's « Couper la sirène »). |
| Thumb down, held 1.2 s | Sounds the Alarm (« Déclencher la sirène »). |
| Hand on its edge, swept across | Changes screen: Operator view ↔ Digital Twin. |
| Index pointed at the screen, palm down | On the Twin, a sight follows the fingertip as a mouse would in the air. On the gas tank, the generator hall, the Enclosure or an intruder, a card by the sight says what the system knows of it: the Probe's reading, the Status and the link, or what the vision model tells of that person (its confidence, where they are in the image, since when). Nothing about who they are: the model does not know. |
| Two open hands, moved apart or brought together | Zooms the Twin in or out, as two fingers do on a screen, from where the camera stood as they took hold. One hand's steering and the swipe wait meanwhile. |

On the Twin, the hand floats in hologram in the lower left of the view: cold white while it steers, green as a
thumb is raised, red as one is turned down. A ring fills in the top bar while a thumb is held: let go before it
is full and nothing is sent.

One more, which the top bar does not tell of: while pointing, hold the thumb out to the side, then bring it
down along the index. It fires where the sight is: an intruder that is hit comes apart in motes of light, and is back
a few seconds later. It is a wink for the demo and changes nothing: no Alert is cleared, no command is sent.

While the hand control is on, the menu has a third screen, **Tutoriel des gestes**: the hands as the sensor
sees them, in a hologram over the desk, what they do at that instant, and every gesture played by a hand of
light. A gesture made is marked. Nothing is sent from there: neither the Alarm nor the screen changes.

## Set it up (Windows or macOS)

1. Install the **Ultraleap tracking software** (Gemini 5.17 or later, or Hyperion) from Ultraleap's site, plug
   the sensor in, and check in its control panel that it shows your hands.
2. With Node 22 or later installed, double-click **`start.bat`** (Windows) or **`start.command`** (macOS) in
   this folder. The first time it installs what it needs, which takes Internet: do it **before** joining the
   table Wi-Fi, which has none. By hand, it is `npm install` then `npm start`.

   It says `Hand bridge listening on ws://127.0.0.1:6438`, then `The sensor is tracking.` once frames come.
3. Join the table Wi-Fi, open the dashboard **on that same machine**, in Chrome, Edge or Firefox, and switch
   the hand control on.

The bridge loads Ultraleap's own library (`LeapC`) where its installer puts it: nothing to compile.

**Why not on the Pi, with the rest?** `infra/plug-and-play.sh` cannot set this up: Ultraleap's tracking software
does not read the original Leap Motion Controller on a Raspberry Pi (only the Controller 2), so the sensor has
to be plugged into the Operator's Windows or macOS machine, and what reads it has to run there.

| Variable | For |
|---|---|
| `LEAPSDK_INSTALL_LOCATION` | The `LeapSDK` folder, when the tracking software is not installed in its default place. |
| `LEAPC_LIBRARY` | The path of `LeapC.dll` / `libLeapC.dylib` / `libLeapC.so` itself. |
| `LEAP_BRIDGE_PORT` | Another port than 6438. The dashboard only looks on 6438. |

## Without a sensor

```sh
npm run simulate
```

plays a made-up hand through the one-hand gestures (not the zoom, nor the pointed finger), over and over (about 35 s a round): the dashboard answers to it as to
a real one. To tell a problem of the sensor from one of the dashboard, and to work on the gestures without one.
Mind that its thumbs really send the Alarm's commands.

## If it does not work

| The top bar says | Look at |
|---|---|
| « Pont du capteur injoignable sur ce poste » | The bridge is not running on this machine, or the browser blocks a page from reaching `127.0.0.1` (Safari does; Chrome may ask for the permission to reach the local network). |
| « En attente du capteur de main » | The bridge runs but no frame comes: sensor unplugged, or the Ultraleap tracking service stopped. |
| « Capteur prêt · approchez la main » | All is well: no hand over the sensor. |
| « Main détectée » | A hand, in no pose the dashboard knows. |

The gestures' thresholds are constants, one file each, in `dashboard/src/features/gestures/utils/`: `pose.ts`
(what counts as a thumb up, a flat hand, a thumb drawn back or down), `steer.ts` (the joystick's dead zone and
reach, how far the fingertip moves the sight), `interpret.ts` (how long a thumb is held, how fast a swipe is). They were set on the simulated hand: expect to tune them on a real
one.

## Security

- The bridge listens on the loopback address only: nothing of it is reachable from the network.
- It sends and never reads: a page that connects to it learns where a hand is, and can ask nothing of it.
- A gesture has no power of its own: a thumb goes through `POST /api/v1/commands` like the actuator panel's
  buttons, under the Operator's session and the same rate limit.

## Develop

```sh
npm test         # the byte offsets read from LeapC, the simulated hand, the socket
npm run typecheck
```

`src/tracking.ts` reads LeapC's packed structs as bytes. Its offsets were checked with `offsetof` against
`LeapC.h` (5.x), and the whole chain run against a stand-in library built from that header. It has **not** yet
been run against a real sensor: the tracking software's Linux packages could not be had on the machine it was
written on.

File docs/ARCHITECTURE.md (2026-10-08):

# Architecture

## Topology — Option A "Embedded centralization"

We implement the brief's **Option A**: the Local Server ("PC Serveur Local") is a **Raspberry Pi 4 fixed inside the Sentinel-X Enclosure**. It runs the whole containerized stack — web front-end and API — *and* the vision AI, on a **USB webcam**. The ESP32 joins the Pi's Wi-Fi. A laptop is only the Operator's browser. See [`../GLOSSARY.md`](../GLOSSARY.md) for the canonical terms.

| Node | Hardware | Role |
|---|---|---|
| **Sentinel** | ESP32 + probes + Alarm | Senses, decides its own local Alerts, fires the Alarm autonomously |
| **Command Post** | Raspberry Pi 4 + USB webcam on a stepper motor + HDMI status screen | The single server: Wi-Fi AP, MQTT broker, API and its history, dashboard host, vision + predictive AI |
| *Operator laptop* | any laptop | Browser only — nothing of the system runs on it |

The Sentinel and the Command Post live in the same 3D-printed **Enclosure** (see [Physical layout](#physical-layout-option-a)).
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

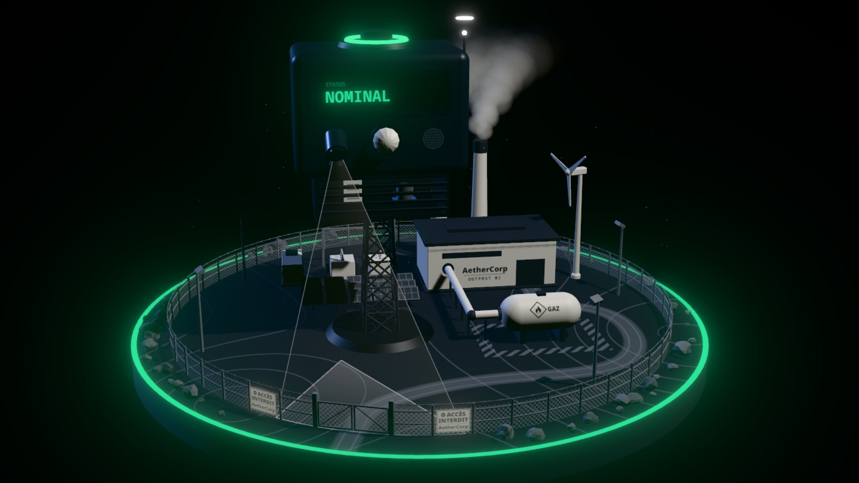
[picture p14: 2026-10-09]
docs/dossier/img/poster-site.jpg

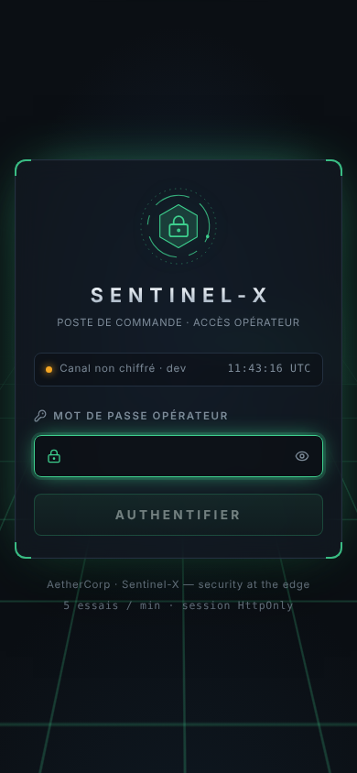
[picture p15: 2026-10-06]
docs/dashboard/login-mobile.png

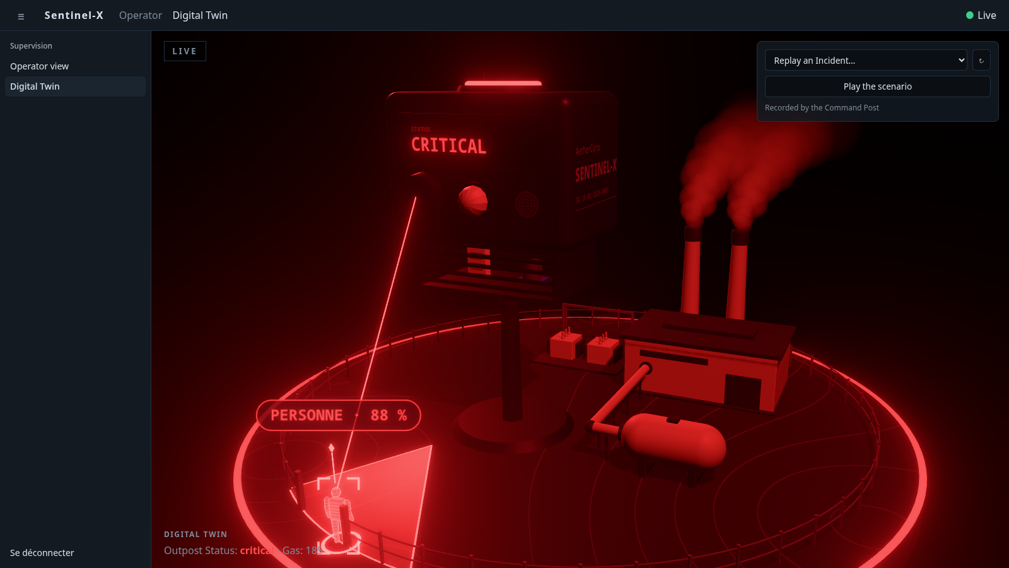
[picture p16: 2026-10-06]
docs/twin/status-flash.png

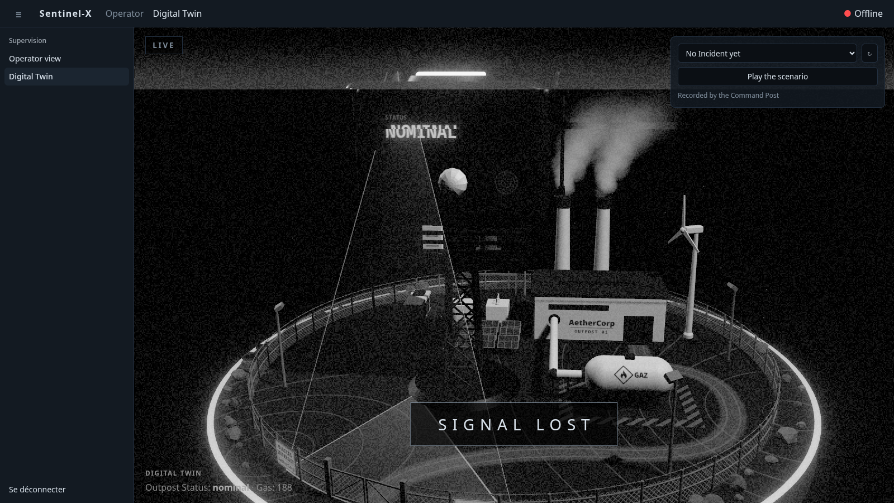
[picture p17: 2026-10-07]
docs/twin/signal-lost.png

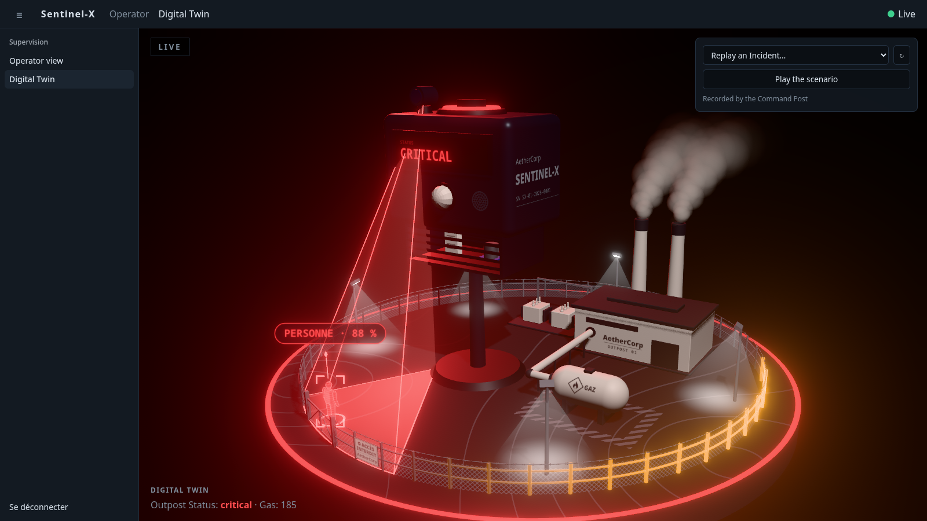
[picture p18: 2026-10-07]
docs/twin/floodlights.png

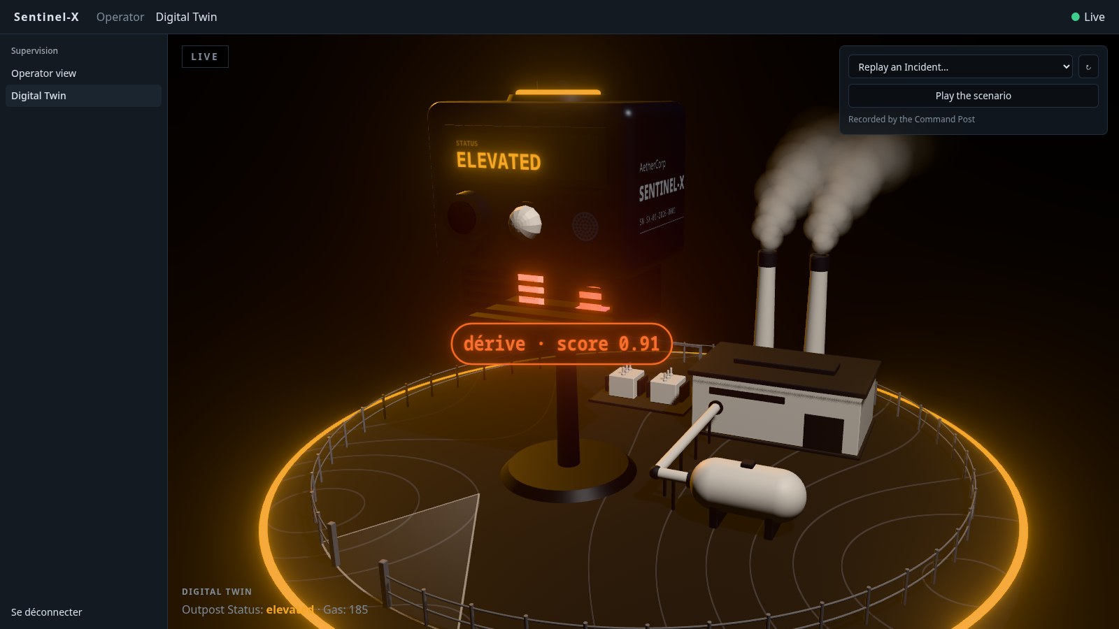
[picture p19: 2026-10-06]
docs/twin/predictive-pulse.png

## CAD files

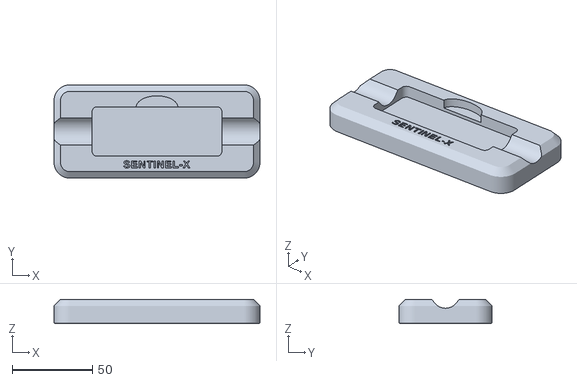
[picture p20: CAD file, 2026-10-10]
enclosure/stl/leap-stand-stand.stl
128.0 x 58.0 x 15.0

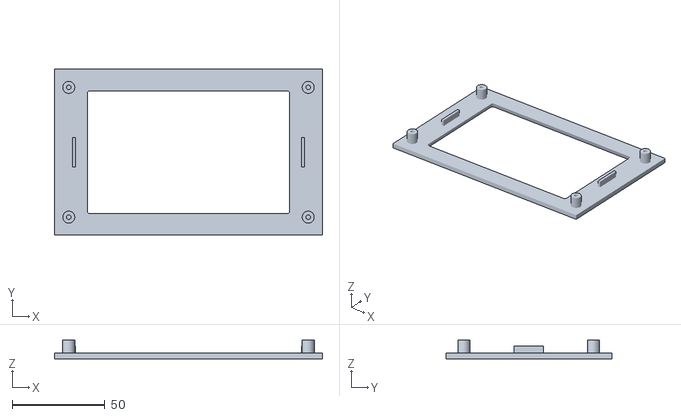
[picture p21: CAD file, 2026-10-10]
enclosure/stl/command-post-bezel.stl
144.6 x 89.7 x 10.0

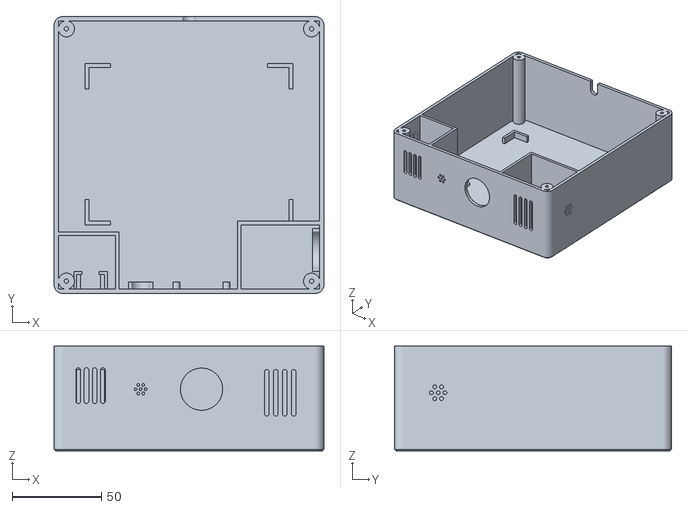
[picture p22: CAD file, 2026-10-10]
enclosure/stl/sentinel-base.stl
150.8 x 154.8 x 58.4

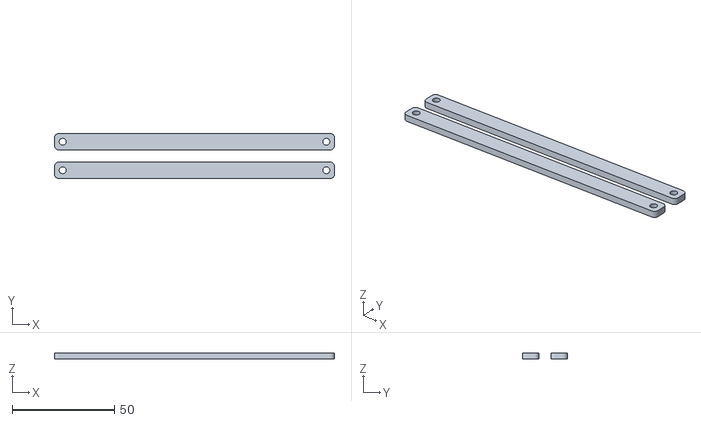
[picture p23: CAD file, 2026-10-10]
enclosure/stl/command-post-clamps.stl
137.2 x 22.0 x 3.00

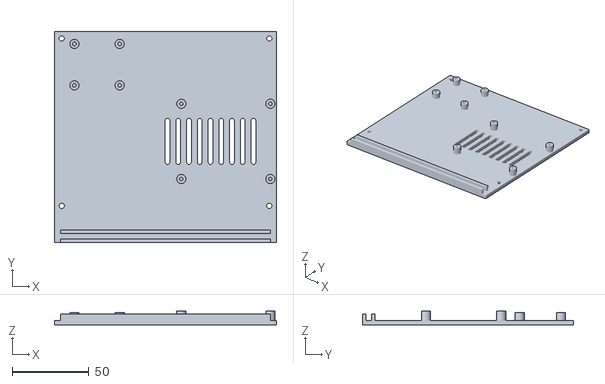
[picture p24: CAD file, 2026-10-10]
enclosure/stl/command-post-base.stl
144.6 x 137.7 x 9.00

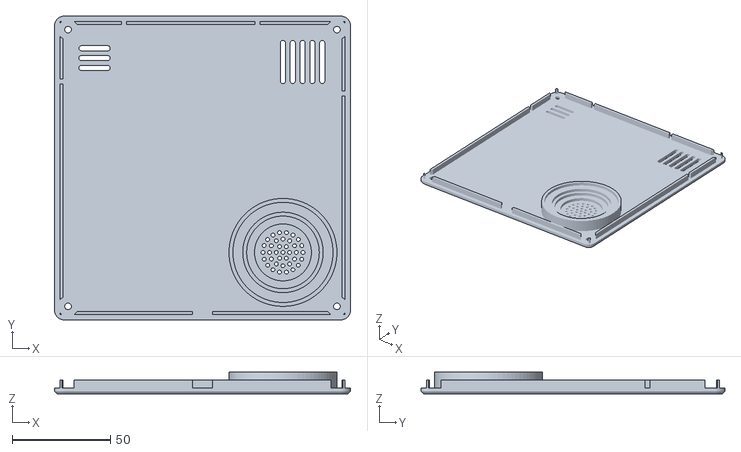
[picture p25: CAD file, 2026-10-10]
enclosure/stl/sentinel-lid.stl
150.8 x 154.8 x 11.0

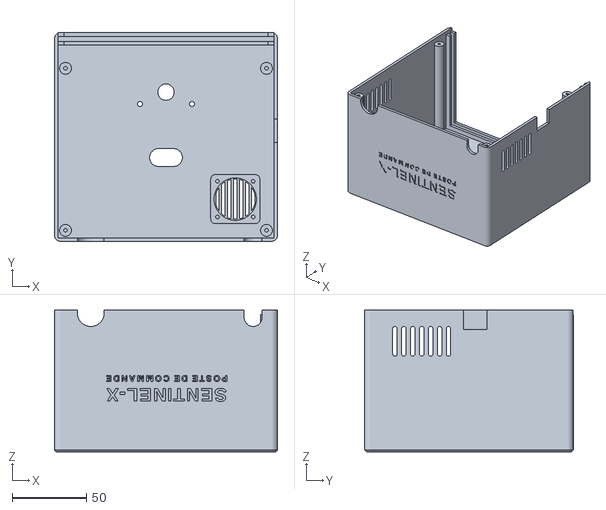
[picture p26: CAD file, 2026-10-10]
enclosure/stl/command-post-shell.stl
150.0 x 140.4 x 95.4

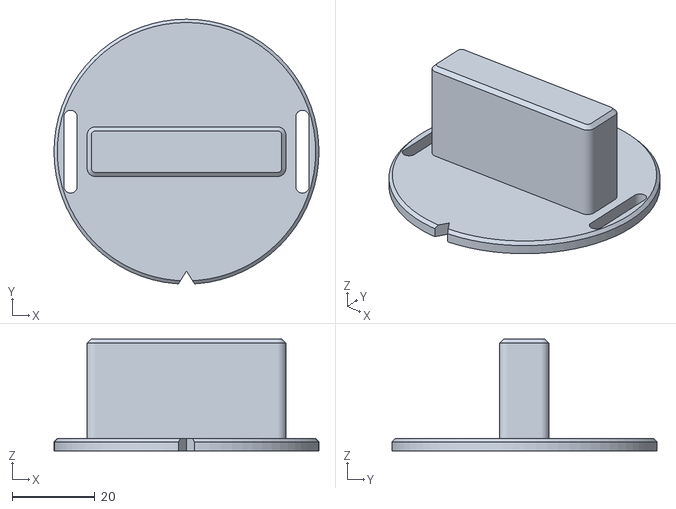
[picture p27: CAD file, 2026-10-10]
enclosure/stl/command-post-turntable.stl
64.0 x 63.9 x 27.0

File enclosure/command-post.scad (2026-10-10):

// Command Post enclosure: the Raspberry Pi 4, its HDMI status screen in the front,
// and the USB webcam on a turntable that the 28BYJ-48 stepper turns, on the roof.
//
// part = "shell" | "base" | "bezel" | "clamps" | "turntable" (each laid as it prints) | "assembly" | "inside"
// Interior coordinates: X from the left wall's inner face, Y from the front, Z from the base plate's top.

include <common.scad>

part = "assembly";

/* [Screen: measure yours] */
scr = [121.2, 78];         // module outline, glass and board, width x height. Default: a 5" HDMI 800x480
scr_view = [108.5, 65.5];  // visible area, cut out of the bezel
scr_view_off = [0, 0];     // centre of the visible area from the module's centre, seen from the front: right, up
scr_edge = 7;              // module thickness along its top and bottom edges, where the clamps press

/* [Shell] */
wall = 2.4;
roof = 2.4;
base_t = 3;
r_out = 4;

/* [Raspberry Pi 4] */
pi = [85, 56];
pi_holes = [[3.5, 3.5], [61.5, 3.5], [3.5, 52.5], [61.5, 52.5]];
pi_so = 6;     // standoffs
pcb_t = 1.5;
y_pi = 38;     // the Pi's GPIO edge from the front: the screen's room is in front of it

W = max(143, scr[0] + 24);  // interior width
H = max(88, scr[1] + 12);   // interior height, base plate to roof
D = y_pi + pi[1] + 44;      // interior depth: behind the Pi, the plugs of its USB-C and micro-HDMI, and the ULN2003

// The Pi lies turned half a turn: its GPIO toward the screen, its USB and Ethernet toward the left,
// its SD card against the right wall. pi_at() takes a point of the Pi's own drawing to the box.
x_sd = W - 0.8;
function pi_at(p) = [x_sd - p[0], y_pi + pi[1] - p[1]];

/* [Front frame: the bezel slides up between lips and ribs] */
lip_d = 2.5;               // lips, in front of the bezel
lip_in = 4;                // how far lips and ribs reach in
bz_t = 3;                  // bezel thickness
y_slot = lip_d;
y_rib = lip_d + bz_t + 0.4;
rib_d = 2.5;

/* [Turret] */
tt_d = 64;                 // turntable
tt_gap = 1;                // between turntable and roof
shaft = [W / 2, 40];
motor_c = shaft + [0, 8];  // the motor's body sits behind its shaft
motor_tabs = [motor_c - [17.5, 0], motor_c + [17.5, 0]];
cam_slot = [shaft[0], shaft[1] + tt_d / 2 + 12];  // the webcam's cable goes in there

fan = [W - 26, D - 26];    // 30 mm fan, optional
uln = [28, D - 22];        // ULN2003 board centre
uln_holes = [29.5, 27];
corner = [[5, 24], [W - 5, 24], [5, D - 5], [W - 5, D - 5]];  // the base's screws, into the shell
feet = [[14, 12], [W - 14, 12], [14, D - 14], [W - 14, D - 14]];

module front_cut(x, z, depth) translate([x, 1, z]) rotate([90, 0, 0]) linear_extrude(depth) children();
module back_cut(x, z, depth) translate([x, D - 1, z]) rotate([90, 0, 180]) linear_extrude(depth) children();
module left_cut(y, z, depth) translate([1, y, z]) rotate([90, 0, -90]) linear_extrude(depth) children();
module right_cut(y, z, depth) translate([W - 1, y, z]) rotate([90, 0, 90]) linear_extrude(depth) children();

// The shell's outline, seen from above.
module outline_2d() translate([-wall, 0]) rrect([W + 2 * wall, D + wall], r_out);

// ---------------------------------------------------------------- shell: roof and three walls, printed roof down

module shell() {
  difference() {
    union() {
      difference() {
        translate([-wall, 0, -base_t]) rbox([W + 2 * wall, D + wall, base_t + H + roof], r_out, ch_top = 1.2);
        translate([0, -1, -base_t - 1]) cube([W, D + 1, base_t + H + 1]);
      }
      // lips and ribs, on both walls and under the roof
      for (y = [[0, lip_d], [y_rib, y_rib + rib_d]]) {
        for (x = [0, W - lip_in]) translate([x, y[0], 0]) cube([lip_in, y[1] - y[0], H]);
        translate([0, y[0], H - lip_in]) cube([W, y[1] - y[0], lip_in]);
      }
      for (c = corner) translate([c[0], c[1], 0]) cylinder(h = H, d = 8);
      // the fan's frame: it presses against it, the air goes through the grille
      translate([fan[0], fan[1], H - 3]) linear_extrude(3 + eps) difference() {
        crect([33, 33], 3);
        circle(d = 28.5);
      }
    }
    for (c = corner) translate([c[0], c[1], -eps]) cylinder(h = 12, d = 2.5, $fn = 24);

    // turret: the shaft and its boss, the motor's two screws, a ring and a zero mark engraved on the roof
    translate([shaft[0], shaft[1], H - 1]) cylinder(h = roof + 2, d = 11);
    for (t = motor_tabs) translate([t[0], t[1], H + roof]) cs_m3(roof + 2);
    translate([shaft[0], shaft[1], H + roof - 0.6]) linear_extrude(1) difference() {
      circle(d = tt_d + 6);
      circle(d = tt_d + 3.6);
    }
    translate([shaft[0], shaft[1] - tt_d / 2 - 5.5, H + roof - 0.6]) linear_extrude(1)
      polygon([[-2.6, -1.8], [2.6, -1.8], [0, 2.2]]);

    translate([cam_slot[0], cam_slot[1], H - 1]) linear_extrude(roof + 2) stadium(22, 12);

    // fan grille and its four screws
    translate([fan[0], fan[1], H - 1]) linear_extrude(roof + 2) intersection() {
      circle(d = 27);
      for (i = [-3 : 3]) translate([i * 4, 0]) square([2.2, 30], center = true);
    }
    for (sx = [-1, 1], sy = [-1, 1]) translate([fan[0] + 12 * sx, fan[1] + 12 * sy, H - 3 - eps]) cylinder(h = 5, d = 2.5, $fn = 24);

    // air in, low on both sides, behind the Pi
    left_cut(102, 18, wall + 2) slot_row(7, 20, 3, 6);
    right_cut(102, 18, wall + 2) slot_row(7, 20, 3, 6);

    // the SD card, right wall
    translate([W - 1, pi_at([0, 28])[1] - 8, -base_t - 1]) cube([wall + 2, 16, base_t + 1 + pi_so + pcb_t + 2.5]);

    // cables out at the back, laid in from below before the base closes: the ESP32's USB and the Ethernet, then the power
    for (n = [[22, 18], [W - 14, 12]]) back_cut(n[0], 0, wall + 2) hull() {
      translate([-n[1] / 2, -base_t - 1]) square([n[1], 1]);
      translate([0, 8 - n[1] / 2]) circle(d = n[1]);
    }

    translate([W / 2, D + wall, H * 0.6]) rotate([90, 0, 180]) label("SENTINEL-X", 9);
    translate([W / 2, D + wall, H * 0.6 - 11]) rotate([90, 0, 180]) label("POSTE DE COMMANDE", 4.2, spacing = 1.25);

    // left wall: the laser-engraved plate (100 x 40) goes in this recess
    translate([-wall - eps, 26, 36]) cube([1 + eps, 100, 40]);
  }
}

// ---------------------------------------------------------------- base plate, inside the walls

module base() {
  difference() {
    union() {
      translate([0, 0, -base_t]) linear_extrude(base_t) intersection() {
        translate([clr, 0]) square([W - 2 * clr, D - clr]);
        outline_2d();
      }
      // the bezel's bottom edge stands between these two
      for (y = [[0, lip_d], [y_rib, y_rib + rib_d]]) translate([lip_in + clr, y[0], 0]) cube([W - 2 * (lip_in + clr), y[1] - y[0], lip_in]);
      for (h = pi_holes) translate(pi_at(h)) boss(pi_so, 6, 2.3, 5);
      for (sx = [-1, 1], sy = [-1, 1]) translate(uln + [sx * uln_holes[0], sy * uln_holes[1]] / 2) boss(5, 6, 2.5, 5);
    }
    for (c = corner) translate([c[0], c[1], -base_t]) mirror([0, 0, 1]) cs_m3(base_t + 1);
    for (f = feet) translate([f[0], f[1], -base_t - eps]) cylinder(h = 1, d = 10.5);
    // air in, under the Pi
    translate([x_sd - pi[0] / 2, y_pi + pi[1] / 2, -base_t - 1]) linear_extrude(base_t + 2) slot_row(9, 30, 3, 7);
  }
}

// ---------------------------------------------------------------- bezel: the front, with the screen behind it

module_at = [(W - scr[0]) / 2, (H - scr[1]) / 2];  // the module's lower left corner, X and Z
clamp_x = scr[0] / 2 + 4;
clamp_z = scr[1] / 2 - 4;

module bezel() {
  y0 = y_slot + 0.2;
  difference() {
    union() {
      translate([clr, y0, 0]) cube([W - 2 * clr, bz_t, H - clr]);
      for (sx = [-1, 1], sz = [-1, 1]) translate([W / 2 + sx * clamp_x, y0 + bz_t, H / 2 + sz * clamp_z])
        rotate([-90, 0, 0]) boss(scr_edge, 6.5, 2.5, scr_edge);
      // guides on the module's left and right edges
      for (sx = [-1, 1]) translate([W / 2 + sx * (scr[0] / 2 + 1.2), y0 + bz_t + 2, H / 2]) cube([1.6, 4, 16], center = true);
    }
    // window, chamfered toward the front
    translate([W / 2 + scr_view_off[0], y0 - eps, H / 2 + scr_view_off[1]]) rotate([-90, 0, 0]) hull() {
      translate([0, 0, 1.2]) linear_extrude(bz_t) crect(scr_view, 1);
      linear_extrude(eps) crect(scr_view + [2.4, 2.4], 2.2);
    }
  }
}

// The two bars that hold the module against the bezel, along its top and bottom edges.
module clamps() for (i = [0, 1]) translate([0, i * 14, 0]) difference() {
  linear_extrude(3) crect([2 * clamp_x + 8, 8], 2);
  for (sx = [-1, 1]) translate([sx * clamp_x, 0, -1]) cylinder(h = 5, d = 3.4);
}

// ---------------------------------------------------------------- turntable: on the stepper's shaft, the webcam clips on its bar

tt_bar = [48, 12, 24];  // a monitor's top edge, for the webcam's clip
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

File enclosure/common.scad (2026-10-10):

// Helpers shared by the Sentinel-X enclosures. Units: mm.

$fn = 72;
eps = 0.01;
clr = 0.3;  // play between two printed parts that fit together

// Rounded rectangle, its corner at the origin.
module rrect(size, r) {
  rr = max(min(r, min(size[0], size[1]) / 2 - eps), eps);
  translate([rr, rr]) offset(r = rr) square([size[0] - 2 * rr, size[1] - 2 * rr]);
}

// Rounded rectangle centred on the origin.
module crect(size, r) translate(-size / 2) rrect(size, r);

// Block with rounded vertical edges, its corner at the origin. ch_top and ch_bot chamfer the top and bottom edges.
module rbox(size, r, ch_top = 0, ch_bot = 0) {
  hull() {
    translate([ch_bot, ch_bot, 0]) linear_extrude(eps) rrect([size[0] - 2 * ch_bot, size[1] - 2 * ch_bot], r - ch_bot);
    translate([0, 0, ch_bot]) linear_extrude(size[2] - ch_bot - ch_top) rrect([size[0], size[1]], r);
    translate([ch_top, ch_top, size[2] - eps]) linear_extrude(eps) rrect([size[0] - 2 * ch_top, size[1] - 2 * ch_top], r - ch_top);
  }
}

// Slot with round ends, l long along X and w wide, centred.
module stadium(l, w) hull() for (s = [-1, 1]) translate([s * (l - w) / 2, 0]) circle(d = w);

// n slots side by side, each l long (along Y) and w wide, p apart along X, centred.
module slot_row(n, l, w, p) for (i = [0 : n - 1]) translate([(i - (n - 1) / 2) * p, 0]) rotate(90) stadium(l, w);

// Round holes of diameter d on rings around the centre, filling a disc of diameter span.
module hole_disc(span, d = 2, pitch = 3.6) {
  circle(d = d);
  for (r = [pitch : pitch : (span - d) / 2]) {
    n = floor(2 * PI * r / pitch);
    for (i = [0 : n - 1]) rotate(i * 360 / n) translate([r, 0]) circle(d = d, $fn = 24);
  }
}

// Hole for a countersunk M3 screw: the head flush at z = 0, the shank along -Z.
module cs_m3(len = 20) {
  translate([0, 0, -len]) cylinder(h = len + eps, d = 3.4);
  translate([0, 0, -1.9]) cylinder(h = 1.9 + eps, d1 = 3.4, d2 = 7);
  cylinder(h = 5, d = 7);
}

// Boss from z = 0 to h, with a pilot hole `depth` deep from its top for a self-tapping screw.
module boss(h, d, pilot, depth) difference() {
  cylinder(h = h, d = d);
  translate([0, 0, h - depth]) cylinder(h = depth + eps, d = pilot, $fn = 24);
}

// Half a ring (its lower half once turned into place) that a round part rests in: a capsule, a gas sensor's can.
// Built along +Z, the half kept is y >= 0.
module cradle(id, od, depth) intersection() {
  difference() {
    cylinder(h = depth, d = od);
    translate([0, 0, -eps]) cylinder(h = depth + 1, d = id);
  }
  translate([-od, 0, -eps]) cube([2 * od, od, depth + 1]);
}

// Text to cut into a face: place it `depth` under the surface, it comes out above.
module label(t, size, depth = 0.6, font = "Liberation Sans:style=Bold", spacing = 1.1)
  translate([0, 0, -depth]) linear_extrude(depth + 1)
    text(t, size = size, font = font, halign = "center", valign = "center", spacing = spacing);

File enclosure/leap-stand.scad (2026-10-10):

// Stand for the original Leap Motion Controller (80 x 30 mm, 11.3 to 13 mm thick), on the Operator's desk.
// The sensor lies flat, its top well above the rim: nothing gets in its 150 degree field of view.
// Its USB cable leaves through either end, whichever way it is laid.

include <common.scad>

part = "stand";  // "stand" (as it prints) | "assembly"

leap = [80, 30];
fit = 0.6;
depth = 7;        // pocket
L = 128;
Wd = 58;
Ht = 15;

module stand() difference() {
  translate([-L / 2, -Wd / 2, 0]) rbox([L, Wd, Ht], 10, ch_top = 4, ch_bot = 0.6);
  translate([0, 0, Ht - depth]) linear_extrude(depth + 1) crect(leap + [fit, fit], 3);
  // the cable, at either end
  for (s = [-1, 1]) translate([s * (leap[0] / 2 + 20), 0, 0]) rotate([90, 0, 90]) linear_extrude(40, center = true) hull() {
    translate([0, Ht - depth + 1.5 + 8.5]) circle(d = 17);
    translate([-8.5, Ht]) square([17, 10]);
  }
  // to lift the sensor out
  translate([0, leap[1] / 2, Ht - depth + 2]) scale([1, 0.55, 1]) cylinder(h = depth, d = 26);
  translate([0, -(leap[1] / 2 + Wd / 2 - 4) / 2 - 0.4, Ht]) label("SENTINEL-X", 4.6);
  for (sx = [-1, 1], sy = [-1, 1]) translate([sx * (L / 2 - 14), sy * (Wd / 2 - 12), -eps]) cylinder(h = 1, d = 10.5);
}

module ghost() color([0.12, 0.12, 0.12]) translate([0, 0, Ht - depth]) linear_extrude(11.3) crect(leap, 5);

if (part == "stand") stand();
else if (part == "assembly") { color("SlateGray") stand(); ghost(); }

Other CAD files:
enclosure/sentinel.scad

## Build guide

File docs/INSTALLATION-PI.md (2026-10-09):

# Installer le Command Post sur le Raspberry Pi

Pas à pas, de la carte SD vierge au dashboard qui affiche les mesures du Sentinel. Tout repose sur [`infra/plug-and-play.sh`](../infra/plug-and-play.sh) : il configure le Pi, démarre la stack et flashe l'ESP32 branché en USB. Détails techniques : [`infra/README.md`](../infra/README.md) et [`firmware/README.md`](../firmware/README.md).

Dans cette page, la table est la n° **4**. Remplace `4` par ton numéro de table partout : le Pi devient `192.168.<table>.1`.

## 0. Le matériel

- Le Raspberry Pi 4, son alimentation officielle (USB-C, 5 V / 3 A) et une carte microSD d'au moins 16 Go.
- Un **câble Ethernet** branché sur un réseau qui a Internet (box, routeur, prise de l'école). Indispensable seulement la première fois.
- L'ESP32 câblé selon [le schéma de l'ESP32](cablage/esp32.html) (à ouvrir dans un navigateur) et [`firmware/include/pins.h`](../firmware/include/pins.h), avec un **câble USB qui transmet les données**. Beaucoup de câbles ne font que charger : avec eux, le Pi ne voit pas l'ESP32.
- Une **webcam USB**, pour la détection d'intrusion.
- En option, un moteur qui fait tourner la webcam pour suivre la personne détectée : un **moteur pas à pas** 28BYJ-48 et sa carte ULN2003 ([Le moteur pas à pas](#le-moteur-pas-à-pas-de-la-caméra-en-option)), ou un **servo** ([Le servo](#le-servo-de-la-caméra-en-option)).
- L'**écran HDMI** 800×480, branché sur un port micro-HDMI du Pi (le deuxième, côté prise jack, convient) : il affiche le statut du Poste de commande, à la place de l'écran de l'ESP32.

## 1. Préparer la carte SD (sur ton PC)

Dans **Raspberry Pi Imager** :

1. Appareil : *Raspberry Pi 4*. Système : *Raspberry Pi OS (64-bit)* (la version *Lite* suffit). Stockage : la carte SD.
2. Dans *Modifier les réglages* :
   - nom d'hôte `sentinel-x` ;
   - un nom d'utilisateur et un mot de passe ;
   - fuseau *Europe/Paris* ;
   - pays Wi-Fi **FR** ;
   - onglet *Services* : **activer SSH** ;
   - ne configure **aucun** réseau Wi-Fi : le Wi-Fi du Pi deviendra le point d'accès de la table.
3. Écris la carte.

## 2. Démarrer le Pi

Mets la carte SD dans le Pi. Branche l'**Ethernet**, l'**ESP32** et la **webcam** sur des ports USB du Pi, puis l'alimentation. Attends 2 minutes.

## 3. Se connecter au Pi

Depuis ton PC, sur le même réseau :

```bash
ssh ton-utilisateur@sentinel-x.local
```

Si ça ne répond pas (certains réseaux d'école bloquent), branche un écran et un clavier sur le Pi. Une fois le script passé, l'écran affiche le statut : **Ctrl+Alt+F2** donne une console de connexion.

## 4. Mettre le Pi à jour

```bash
sudo apt update && sudo apt full-upgrade -y && sudo apt install -y git
sudo reboot
```

Reconnecte-toi après le redémarrage, comme à l'étape 3.

## 5. Vérifier que le Pi voit l'ESP32

```bash
ls /dev/ttyUSB*
```

Ça doit afficher `/dev/ttyUSB0`. Sinon, change de câble USB.

## 6. Lancer le script

```bash
git clone https://github.com/ArthurPoncin/sentinel-x.git
cd sentinel-x
infra/plug-and-play.sh 4
```

- **Tout est demandé au début** : le mot de passe `sudo`, puis **deux fois le mot de passe Opérateur** (12 caractères minimum ; retiens-le, c'est celui du dashboard). Ensuite, le script tourne seul.
- La première fois, c'est surtout des téléchargements : les images Docker arrivent toutes construites de GitHub (voir l'étape 2 ci-dessous). Si elles ne le peuvent pas, le Pi les construit lui-même, et il faut compter **30 à 60 minutes**.
- Lance-le **en SSH par l'Ethernet** : à l'étape 7, le Wi-Fi du Pi devient le point d'accès de la table, et une session passée par le Wi-Fi serait coupée.

Il déroule 10 étapes numérotées. Chacune affiche un spinner et son temps, avec en gris la dernière ligne de ce qu'elle fait ; une fois finie, elle passe à `✓` (ou à `!` s'il y a une remarque). Ce que disent les commandes (Docker, PlatformIO…) va dans un journal, `~/.local/share/sentinel-x/plug-and-play.log`, au lieu d'inonder l'écran.

1. **Logiciels** : Docker, PlatformIO, dnsmasq (DHCP) et chrony (heure), tant qu'il y a Internet.
2. **Images Docker** : chaque image construite par GitHub pour ce code exact est téléchargée ; les autres sont construites sur le Pi (code modifié sur le Pi, image pas encore publiée, ou pas d'Internet : alors celles déjà là servent).
3. **Secrets et certificats** : dans `infra/secrets/`, jamais commités.
4. **Webcam USB** : elle est donnée au service `vision` si elle est branchée, avec le moteur pas à pas qui la fait tourner.
5. **Démarrage de la stack** : les conteneurs, sur les images de l'étape 2.
6. **Firmware du Sentinel** : compilé avec les secrets de ce Pi ; les mots de passe ne quittent jamais le Pi.
7. **Wi-Fi de la table** : le Wi-Fi du Pi devient le réseau `SentinelX-4`, en 2,4 GHz, WPA2, sans Internet. L'ESP32 a toujours l'adresse `192.168.4.10`, et le Pi lui donne l'heure.
8. **Écran HDMI** : l'écran du Pi affiche en continu le statut du Poste de commande (voir [L'écran de statut](#lécran-de-statut)), à la place de l'invite de connexion.
9. **Flash de l'ESP32** par USB (`– ignoré` avec `--no-flash`).
10. **Première mesure du Sentinel** : il attend que l'ESP32 rejoigne le Wi-Fi, puis sa première mesure sur le broker.

Si une étape échoue, le script s'arrête sur un `✗`, avec la raison encadrée en rouge et les dernières lignes de la commande qui a échoué. Ctrl+C l'interrompt proprement ; relancé, il reprend sans rien casser.

## 7. Lire la fin

Le script finit sur un encadré : **vert** « Command Post prêt » si tout s'est bien passé, **jaune** « avec des remarques » sinon.

- **Wi-Fi** et **Passphrase** : note la phrase de passe du Wi-Fi de la table. Elle est aussi gardée dans `infra/secrets/wifi.env`.
- **Sentinel** `✓ 192.168.4.10` et l'étape 10 qui affiche `première mesure : 23.4 °C · humidité 41 % · gaz 312` : **tout marche**, l'ESP32 envoie ses mesures au Pi.
- **Webcam** `✓ donnée à vision` : la webcam va au service `vision`.
- **Moteur** `✓ moteur pas à pas, donné à vision` (ou `servo`) : la caméra tourne pour suivre la personne détectée. `sans : caméra fixe` : c'est ce que demande ton `.env` (la raison est entre parenthèses), tout le reste marche pareil.
- **Écran HDMI** `✓ statut affiché` : l'écran du Pi montre le statut (ci-dessous).
- Sous **À voir**, chaque remarque `!` dit ce qui manque : voir aussi [Dépannage](#dépannage).
- Sous **Ensuite**, les commandes à copier telles quelles : récupérer le certificat, puis les journaux.

### Le moteur pas à pas de la caméra (en option)

La webcam peut être posée sur un moteur pas à pas 28BYJ-48, au-dessus du boîtier : elle tourne alors toute seule pour garder au centre de l'image la personne qu'elle suit, et le jumeau numérique place le bonhomme du bon côté du site.

1. **Câble la carte ULN2003, Pi éteint**, le moteur branché dans sa prise blanche. Le [schéma du Raspberry Pi](cablage/raspberry-pi.html) montre ses ports et son connecteur GPIO :

   | Carte ULN2003 | Raspberry Pi |
   |---|---|
   | IN1 · IN2 · IN3 · IN4 | GPIO 6 · 13 · 19 · 26 (broches **31 · 33 · 35 · 37**) |
   | − | masse, broche **39** (juste à côté) |
   | + | 5 V, broche **4** |

   Les broches impaires sont celles de la rangée intérieure, la broche 1 étant à l'opposé des ports USB. Le moteur tire environ 200 mA, sans à-coups : la broche 5 V du Pi suffit, contrairement à un servo qui force. Laisse du mou au câble USB de la webcam.
2. **Tourne la caméra à la main** pour qu'elle regarde droit devant, puis lance `infra/plug-and-play.sh 4 --no-flash`. L'étape 4 affiche `moteur pas à pas de la caméra sur GPIO 6,13,19,26, donné à vision`. Il n'y a rien d'autre à installer : le script donne le moteur à `vision` tout seul, et retire le servo s'il y en avait un.

Sans moteur branché, mets `PAN_DRIVE=none` dans `.env` avant de lancer le script : sinon `vision` croit tourner la caméra, et le jumeau place le bonhomme de travers.

**Le point 0** : là où la caméra regarde quand `vision` démarre, au premier allumage du Pi comme après l'avoir éteint et rallumé. Quand personne n'est là, elle y revient 2 s après la fin de l'intrusion, puis fait sa **ronde** : elle tourne lentement jusqu'à +30°, puis jusqu'à -30°, et ainsi de suite, pour chercher les intrus. Quelqu'un apparaît : elle le suit, puis revient à son 0 et reprend sa ronde.

Le moteur ne sait pas où il est : il compte les pas qu'il fait depuis son démarrage. `vision` le ramène au centre quand il s'arrête proprement. Si le Pi a été coupé brutalement, ou si tu as tourné la caméra à la main, **remets-la droit devant avant de relancer** `vision`. Entre deux mouvements, le moteur n'est plus alimenté : ses engrenages tiennent la caméra, et il ne chauffe pas.

**Tester le moteur, ou remettre la caméra droite sans la forcer** — la commande fait tourner la caméra du nombre de degrés donné (positif : vers la droite de son image) et la laisse là, ce qui devient sa position de repos :

```bash
docker compose stop vision
docker compose run --rm --entrypoint python3 vision -m vision.pan 30     # 30° à droite ; -30 : à gauche
docker compose start vision
```

Les LED de la carte clignotent pendant qu'il tourne. Si la caméra part à gauche, le moteur est monté dans l'autre sens : `PAN_INVERT=true`.

**Régler le moteur** — dans le fichier `.env` à la racine du dépôt, puis `docker compose up -d vision` :

| Réglage | Défaut | À changer si |
|---|---|---|
| `PAN_INVERT` | `false` | La caméra tourne du mauvais côté, à l'opposé de la personne : mets `true` |
| `PAN_STEPPER_PINS` | `6,13,19,26` | Tu as branché IN1 à IN4 sur d'autres GPIO |
| `PAN_MIN_DEG` / `PAN_MAX_DEG` | `-90` / `90` | Le câble de la webcam tire en bout de course : réduis (par exemple `-60` / `60`) |
| `PAN_STEP_MS` | `2` | Le moteur vibre sans tourner, ou la caméra n'est pas au bon endroit après un aller-retour : il manque des pas, mets `3` |
| `PAN_STEPS_PER_TURN` | `4096` | Un tour demandé ne fait pas un tour : c'est le nombre de demi-pas d'un tour de l'axe |
| `PAN_HOME_AFTER_S` | `2` | La caméra revient trop vite (ou trop tard) à son 0 quand elle a perdu la personne : c'est l'attente, en secondes, après la fin de l'intrusion |
| `PAN_PATROL_DEG` | `30` | La ronde est trop large ou trop étroite : la caméra va de 0 à +30°, puis -30°, et ainsi de suite. `0` : pas de ronde, elle reste à son 0 |
| `PAN_PATROL_SPEED_DEG_S` | `8` | La ronde est trop lente, ou l'image est floue pendant la ronde |
| `CAMERA_FOV_DEG` | `60` | Le bonhomme du jumeau n'est pas du bon côté quand la personne est au bord de l'image |
| `PAN_DRIVE` | — | Pas de moteur, ou caméra à laisser fixe : `PAN_DRIVE=none` |

### Le servo de la caméra (en option)

La webcam peut être posée sur un servo, au-dessus du boîtier : elle tourne alors toute seule pour garder au centre de l'image la personne qu'elle suit, et le jumeau numérique place le bonhomme du bon côté du site.

1. **Câble le servo, Pi éteint** : son fil de signal sur le **GPIO 18** (broche 12), sa masse sur une masse du Pi (broche 14), et son **5 V sur une alimentation à part**, les masses reliées entre elles. Ne l'alimente pas par la broche 5 V du Pi : un servo qui force tire plus de courant qu'elle n'en donne, et le Pi redémarre. Laisse du mou au câble USB de la webcam.
2. **Sur le Pi, une seule fois** :
   ```bash
   infra/servo.sh
   sudo reboot
   ```
3. **Après le redémarrage** : ajoute `PAN_DRIVE=pwm` dans `.env` (sans cette ligne, c'est le moteur pas à pas que le script donne à `vision`), puis `infra/plug-and-play.sh 4 --no-flash`. L'étape 4 affiche `servo de la caméra sur GPIO 18, donné à vision`.

Au démarrage de `vision`, le servo se met au centre : c'est la position de repos, celle où la caméra regarde droit devant. Elle y revient 2 s après la fin d'une intrusion, puis fait sa ronde de -30° à +30° autour, comme le moteur pas à pas.

**Régler le servo** — dans le fichier `.env` à la racine du dépôt, puis `docker compose up -d vision` :

| Réglage | Défaut | À changer si |
|---|---|---|
| `PAN_INVERT` | `false` | La caméra tourne du mauvais côté, à l'opposé de la personne : mets `true` |
| `PAN_MIN_DEG` / `PAN_MAX_DEG` | `-90` / `90` | Le servo bute ou force en bout de course : réduis (par exemple `-80` / `80`) |
| `PAN_MIN_US` / `PAN_MAX_US` | `500` / `2500` | À `-90` et `90` la caméra ne fait pas un quart de tour de chaque côté : ce sont les impulsions aux deux bouts de la course, en microsecondes |
| `PAN_SPEED_DEG_S` | `60` | La caméra est trop lente à suivre, ou l'image devient floue quand elle tourne |
| `PAN_HOME_AFTER_S` | `2` | La caméra revient trop vite (ou trop tard) à son 0 quand elle a perdu la personne : c'est l'attente, en secondes, après la fin de l'intrusion |
| `PAN_PATROL_DEG` | `30` | La ronde est trop large ou trop étroite : la caméra va de 0 à +30°, puis -30°, et ainsi de suite. `0` : pas de ronde, elle reste à son 0 |
| `PAN_PATROL_SPEED_DEG_S` | `8` | La ronde est trop lente, ou l'image est floue pendant la ronde |
| `CAMERA_FOV_DEG` | `60` | Le bonhomme du jumeau n'est pas du bon côté quand la personne est au bord de l'image : c'est l'angle de champ horizontal de la webcam |

### L'écran de statut

Il remplace l'écran de l'ESP32 et se redessine chaque seconde : le Wi-Fi de la table et son point d'accès, l'adresse du dashboard, le Sentinel et ses dernières mesures, ses alertes en cours (en rouge et en capitales quand elles sont critiques), la webcam et les conteneurs. Les alertes d'intrusion et prédictives ne passent pas par le broker : elles sont sur le dashboard.

| Ligne **Sentinel** | Ce que ça veut dire |
|---|---|
| `EN LIGNE` | Il envoie ses mesures : tout va bien |
| `SUR LE WI-FI` | Il a son adresse mais n'envoie rien : le moniteur série dit pourquoi (broker, heure ou DHT22, voir [Dépannage](#dépannage)) |
| `MUET` | Il envoyait, puis plus rien depuis le temps affiché : alimentation, redémarrage, moniteur série |
| `ABSENT` | Il n'est pas sur le Wi-Fi de la table : alimentation, puis moniteur série |
| `BROKER ?` | L'écran ne joint pas le broker : `docker compose ps`, puis relance le script |

L'écran occupe la première console du Pi : pour se connecter avec un clavier, **Ctrl+Alt+F2** ouvre une console de connexion, **Ctrl+Alt+F1** ramène le statut.

## 8. Connecter le PC Opérateur

1. Connecte le PC au Wi-Fi **`SentinelX-4`** avec la phrase de passe de l'étape 7.
2. Dans le dépôt cloné sur le PC, **une commande** fait le reste (elle est aussi affichée à la fin du script du Pi) :
   ```bash
   infra/operator.sh 4 ton-utilisateur          # Mac, Linux
   ```
   ```powershell
   powershell -ExecutionPolicy Bypass -File infra\operator.ps1 4 ton-utilisateur     # Windows, PowerShell ouvert en administrateur
   ```
   Elle prend le certificat de l'équipe sur le Pi, l'installe comme autorité de confiance (système et navigateurs) et écrit `192.168.4.1 sentinel-x.local` dans le fichier hosts du PC : le Wi-Fi de la table n'a pas de DNS, c'est le PC qui sait où est `sentinel-x.local`. Elle demande le mot de passe du Pi, puis celui du PC.
3. Ferme et rouvre le navigateur, ouvre **`https://sentinel-x.local/`** (ou `https://192.168.4.1/`) et connecte-toi avec le mot de passe Opérateur.

Tant que la commande n'est pas passée, le navigateur affiche « Non sécurisé » et raye le `https` : la connexion est chiffrée, mais il ne connaît pas l'autorité qui a signé le certificat.

<details>
<summary>À la main, si la commande ne passe pas</summary>

1. Récupère le certificat : `scp ton-utilisateur@192.168.4.1:sentinel-x/infra/secrets/ca.crt .`
2. Installe-le comme autorité de confiance :
   - **Mac** : double-clic sur `ca.crt`, trousseau *Système*. Double-clic ensuite sur « Sentinel-X Team CA », puis *Se fier* → *Toujours approuver*.
   - **Windows** : double-clic, *Installer le certificat* → *Ordinateur local* → magasin *Autorités de certification racines de confiance*.
   - **Linux** : `sudo trust anchor ca.crt` (Arch, Fedora) ou `sudo cp ca.crt /usr/local/share/ca-certificates/sentinel-x.crt && sudo update-ca-certificates` (Debian, Ubuntu). Chrome et Chromium ont leur propre liste : `chrome://certificate-manager`, puis importer dans les autorités de confiance.
   - **Firefox** a sa propre liste : *Paramètres → Certificats → Importer*, en cochant *Confirmer cette AC pour identifier des sites web*.
3. Ajoute `192.168.4.1 sentinel-x.local` au fichier hosts du PC (`/etc/hosts` sur Mac et Linux, `C:\Windows\System32\drivers\etc\hosts` sur Windows, en administrateur).

</details>

## 9. Tester

Laisse **1 minute** au MQ-2 et au PIR pour chauffer, puis :

- **Gaz** : approche un briquet **éteint** du MQ-2 et appuie sur le bouton sans l'allumer. La courbe de gaz monte ; au-delà du seuil critique, la sirène sonne.
- **Température** : pose la main sur le DHT22, elle monte doucement.
- **Présence** : passe devant le PIR.
- **Son** : tape dans les mains près du capteur.

Les seuils se règlent dans [`firmware/include/config.h`](../firmware/include/config.h), puis on relance le script pour reflasher.

## Ensuite

- **Au quotidien** : il suffit d'allumer le Pi. Le Wi-Fi de la table, la stack et l'ESP32 redémarrent tout seuls.
- **Mettre à jour** : branche l'Ethernet, puis
  ```bash
  cd ~/sentinel-x && infra/update.sh
  ```
  Il récupère le code et ses images, et ne remplace que les conteneurs qui ont changé : ni sudo, ni Wi-Fi relancé, l'ESP32 n'est pas touché. Si la mise à jour apporte un nouveau firmware ou change l'installation du Pi, il le dit à la fin, avec la commande à lancer.
- **Tout repasser** (nouveau firmware, webcam ou servo ajouté, installation du Pi changée) : `infra/plug-and-play.sh 4`, ou `infra/plug-and-play.sh 4 --no-flash` pour ne pas toucher à l'ESP32.
- **Durcir le Pi avant le pentest** : [`DURCISSEMENT-PI.md`](DURCISSEMENT-PI.md), une fois que tout marche ici. Après, `sentinel-x.local` ne répond plus et SSH n'accepte que le PC Opérateur, sur le Wi-Fi de la table : `ssh ton-utilisateur@192.168.4.1`.

## Dépannage

L'écran HDMI dit si le Sentinel envoie ses mesures ([L'écran de statut](#lécran-de-statut)). S'il ne les envoie pas, son moniteur série dit ce qu'il attend : branche l'ESP32 en USB sur le Pi, puis `~/.local/share/sentinel-x/platformio/bin/pio device monitor -d firmware`. Chaque seconde, une ligne `T=… H=… air=… pir=… son=… | wifi=… heure=… broker=… <problème>` :

| Moniteur série | Quoi faire |
|---|---|
| `wifi=0` et `Wi-Fi...` | Vérifie que l'écran HDMI dit le point d'accès `ACTIF` (sinon `nmcli connection show --active`), puis relance le script |
| `MQTT: TLS/reseau` | Vérifie avec `docker compose ps` que `mosquitto` tourne, puis relance le script : il refait le certificat si besoin |
| `MQTT: mot de passe` | Relance le script : il reflashe l'ESP32 avec le bon mot de passe |
| `heure=0` | `systemctl status chrony` |
| `T=nan` | Câblage du DHT22 et sa résistance de 10 kΩ entre DATA et 3V3. Rien n'est envoyé tant qu'il ne répond pas |
| Pas de bip au démarrage, pas de sirène | L'enceinte : un fil sur IO25 **par une résistance de 100 Ω au moins**, l'autre sur **GND**, jamais sur le 5V. Ou le buzzer, + sur IO25 et − sur GND. Le moniteur doit afficher `[command] buzzer pattern` quand tu cliques sur la sirène : sinon, l'ordre n'arrive pas (Wi-Fi, broker) |
| Tout s'éteint quand la sirène s'arrête, et repart quand elle sonne | Un fil de l'enceinte est sur le 5V : IO25 court-circuite alors le rail 5V. Débranche-la tout de suite, et rebranche-la entre IO25 (par 100 Ω) et GND |

L'écran HDMI :

| Problème | Quoi faire |
|---|---|
| Écran noir | Force la sortie du deuxième port en 800×480 : `sudo sed -i '1 s/$/ video=HDMI-A-2:800x480M@60D/' /boot/firmware/cmdline.txt`, puis `sudo reboot` |
| Une invite de connexion au lieu du statut | `systemctl status sentinel-x-screen` ; ses erreurs : `journalctl -u sentinel-x-screen` |
| `BROKER ?` et `paho-mqtt manque` ou `pas de compte screen` | Relance le script (avec Internet la première fois) |

Le script lui-même :

| Message | Quoi faire |
|---|---|
| `pas d'ESP32 en USB` | Branche l'ESP32 sur le Pi avec un câble de données, puis relance |
| `le flash a échoué` | Maintiens le bouton **BOOT** de l'ESP32 au début de l'envoi, puis relance |
| `paquets manquants` / `Docker manque` / `PlatformIO manque` | Le Pi n'a pas Internet : branche l'Ethernet, puis relance |
| `les images préconstruites sont encore privées` | Rien ne casse : le Pi les construit, c'est juste plus long. Pour aller vite, le propriétaire du dépôt (Arthur) rend publics, une fois, les paquets `sentinel-x-*` sur GitHub (*Package settings → Change visibility → Public*) |
| `pas encore d'image préconstruite pour ce code` | La CI de GitHub la construit encore (quelques minutes après un push sur `main`) : attends la fin de l'action *Images*, puis relance |
| `l'image … ne se construit pas` | Lis les lignes affichées sous l'encadré ; sans Internet, branche l'Ethernet, puis relance |
| `la stack ne démarre pas` | Lis les lignes affichées sous l'encadré (le journal complet est dans `~/.local/share/sentinel-x/plug-and-play.log`) ; sans Internet, une image qui manque ne peut pas être construite |
| `le firmware ne compile pas` | La première fois, PlatformIO télécharge ses outils : il faut Internet |
| `NetworkManager ne tourne pas` | Le système est trop ancien : réinstalle un Raspberry Pi OS (64-bit) récent |
| `pas de webcam USB` | Branche la webcam sur un port USB du Pi (elle doit apparaître dans `ls /dev/v4l/by-id`), puis relance avec `--no-flash` |
| `pas d'écran HDMI détecté` | Branche l'écran : le statut s'y affiche seul. Écran noir : tableau ci-dessus |
| Le moteur pas à pas ne bouge pas | `docker compose logs vision` : « Stepper on /dev/gpiochip0, GPIO 6, 13, 19, 26, ready » quand il est pris en main. « unavailable » : relance `infra/plug-and-play.sh <table> --no-flash`. Pour le faire tourner sans attendre une intrusion : « Tester le moteur », dans [Le moteur pas à pas](#le-moteur-pas-à-pas-de-la-caméra-en-option). Vérifie les fils IN1 à IN4, et le + et le − de la carte : ses LED s'allument quand le moteur tourne |
| Le moteur pas à pas vibre sans tourner | Il manque des pas : `PAN_STEP_MS=3` dans `.env`, puis `docker compose up -d vision`. Ou IN1 à IN4 ne sont pas dans l'ordre |
| Le servo ne bouge pas | `docker compose logs vision` : « Servo on /pwm ready » quand il est pris en main. « unavailable » : relance `infra/servo.sh`, redémarre le Pi, puis `infra/plug-and-play.sh <table> --no-flash`. Vérifie aussi son alimentation et le fil de signal sur le GPIO 18 |
| Le Pi redémarre quand le servo bouge | Le servo est alimenté par le Pi : donne-lui une alimentation 5 V à part, masses reliées |
| La caméra ne tourne plus du tout | `DETECTOR=motion` dans `.env` : une caméra qui tourne a besoin du détecteur de personnes, `vision` la laisse fixe et le dit dans ses journaux. Enlève cette ligne pour qu'elle suive à nouveau |
| La caméra dépasse la personne, puis revient | `PAN_SPEED_DEG_S` au-dessus de 40 dans `.env` : le moteur ne suit pas, enlève cette ligne |
| `le Sentinel n'est pas encore sur le Wi-Fi` | Vérifie qu'il est alimenté, puis ce que dit son moniteur série (tableau ci-dessus) |

Journaux :

- **l'ESP32 en direct** : `~/.local/share/sentinel-x/platformio/bin/pio device monitor -d firmware` (Ctrl+C pour quitter) ;
- **le script** : `~/.local/share/sentinel-x/plug-and-play.log`, tout ce qu'ont dit les commandes de son dernier passage (`update.log` pour `infra/update.sh`) ;
- **le Pi** : `docker compose logs -f api mosquitto` ;
- **la caméra** : `docker compose logs -f vision` (« Camera opencv:0 up, 640x480 » quand elle marche). Dans le dashboard, une image grise « camera down, retrying » veut dire que `vision` tourne sans caméra.

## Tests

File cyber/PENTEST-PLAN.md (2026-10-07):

# Plan de test & règles d'engagement — Pentest croisé (jeudi)

L'après-midi du jeudi est consacrée au **pentest croisé national** : chaque table audite les autres et défend la sienne. Ce document fixe les règles de l'exercice, ce qu'on vérifie sur notre propre système (volet défensif) et comment on mène l'audit d'une table consentante (volet offensif). Les résultats remplissent le [modèle de rapport](RAPPORT-AUDIT.md) et la matrice de sécurité du dossier (#52).

Le modèle de sécurité qu'on vérifie est dans [`../docs/ARCHITECTURE.md` § Security model](../docs/ARCHITECTURE.md#security-model-binding-for-every-workstream) ; le durcissement du Pi dans [`README.md`](README.md) et [`../docs/DURCISSEMENT-PI.md`](../docs/DURCISSEMENT-PI.md).

---

## Règles d'engagement

- **Cibles consentantes seulement.** On n'audite que les tables du workshop qui participent à l'exercice, et seulement pendant le créneau prévu. Rien hors du périmètre du workshop.
- **Périmètre réseau :** le sous-réseau de la table cible (`192.168.<n>.0/24`) et ses services exposés. Pas d'attaque de l'infrastructure de l'école, du Wi-Fi de l'établissement, ni d'un poste personnel.
- **Pas de destruction de données ni de persistance.** On démontre une faille, on ne détruit pas, on ne laisse rien derrière. Aucun identifiant récupéré n'est réutilisé hors de la démonstration.
- **DoS encadré :** une démonstration courte et mesurée pour prouver (ou réfuter) une limite de débit, pas une inondation prolongée. On prévient la table cible avant.
- **Traçabilité :** chaque test est horodaté et noté dans le rapport, qu'il réussisse ou non.
- **Respect mutuel :** on signale à la table auditée ses failles à la fin ; le but est l'audit, pas le sabotage.

> Pentesting scoped to the workshop's consenting teams only. Aucun secret ni clé récupéré n'est conservé ou publié.

## Outillage

- **Nmap** — cartographie des ports et des services.
- **Wireshark / tcpdump** — observation du trafic de la table (preuve du chiffrement, recherche de clair).
- **Metasploit** — cadre de test des services exposés.
- Un client **MQTT** (`mosquitto_pub`/`mosquitto_sub`) et **curl** pour sonder le broker et l'API.

---

## Volet défensif — vérifier notre Command Post avant l'audit

À passer sur notre propre table, dans l'ordre, avant que les autres ne nous auditent. Chaque ligne attend un résultat précis : si le réel diffère, c'est une anomalie à corriger ou à justifier dans le rapport. `cyber/harden.sh <n> --check` relit déjà la checklist de durcissement ligne par ligne ; ce tableau vérifie en plus le comportement vu de l'extérieur.

| # | Ce qu'on vérifie | Depuis | Attendu | Réf. |
|---|---|---|---|---|
| D1 | **Ports TCP exposés** : `nmap -sS -p- 192.168.<n>.1` | PC Opérateur | seuls 22, 443, 8883 répondent ; tout le reste `filtered` | surface exposée |
| D2 | **Ports UDP** : `nmap -sU -p 53,67,68,69,123,137,161,1900,5353 192.168.<n>.1` | PC Opérateur | seuls 67 et 123 servent (confirmés par les scripts `dhcp-discover` / `ntp-info`) | surface exposée |
| D3 | **Docker ne contourne pas le pare-feu** : refaire D1 depuis l'Ethernet et depuis une autre machine de la table | Ethernet / autre PC | 443 et 8883 ne répondent que depuis le Wi-Fi de la table ; rien par l'Ethernet | chaîne `DOCKER-USER` |
| D4 | **SSH par clé seulement** : tentative de connexion par mot de passe | PC Opérateur | refusée ; seul le compte admin par clé ed25519 entre, et seulement depuis le PC Opérateur | SSH |
| D5 | **Pas de port en clair** : recherche d'un listener MQTT 1883 et HTTP 80 | PC Opérateur | aucun ; connexion refusée | surface exposée |
| D6 | **TLS du broker** : `openssl s_client -connect 192.168.<n>.1:8883` | PC Opérateur | TLS ≥ 1.2, certificat signé par la CA d'équipe, SAN `IP:192.168.<n>.1` ; une connexion sans la CA échoue | Transport |
| D7 | **TLS/HTTPS du dashboard** : `openssl s_client -connect 192.168.<n>.1:443` et test HTTP→rien | PC Opérateur | HTTPS seulement, certificat de la CA | Transport |
| D8 | **Le trafic est bien chiffré** : capture Wireshark pendant une session de démo | PC Opérateur | MQTT et HTTP illisibles en clair ; aucun identifiant ni mesure lisible | Transport |
| D9 | **Broker fermé aux anonymes** : `mosquitto_sub` sans identifiants, puis avec la CA mais sans compte | PC Opérateur | refusé (`allow_anonymous false`) | Auth |
| D10 | **ACL du broker** : avec le compte `sentinel-01`, tenter de publier sur `command/...` ou de lire une autre table | PC Opérateur | refusé ; chaque compte tient dans son périmètre d'ACL | Auth (ACL) |
| D11 | **API sans session** : `curl` sur un endpoint protégé sans cookie | PC Opérateur | `401` ; le flux WebSocket et la caméra refusent de même | Operator session |
| D12 | **Jeton de service borné** : `POST /api/v1/alerts` avec le jeton `vision` mais un `kind` qui n'est pas le sien | interne | refusé ; un service ne poste que son `kind` | Auth (tokens) |
| D13 | **Payload non fiable** : poster une Alerte avec un `sentinel` ou un `source` mensonger | interne | ignoré : l'`api` dérive `sentinel` du topic et `source` du canal | « Never trust the payload » |
| D14 | **Limite de connexion (login)** : plus de 5 tentatives/min sur `/api/v1/auth/login` | PC Opérateur | `429` avec `Retry-After` au-delà de 5 | Rate limits |
| D15 | **Limites de débit (commandes/alertes)** : dépasser 2 commandes/s, 20 alertes/s par jeton | PC Opérateur / interne | rejeté au-delà de la limite | Rate limits |
| D16 | **Inondation MQTT** : message au-dessus de `max_packet_size` (4096), rafale de messages | PC Opérateur | message trop gros rejeté ; la rotation des logs empêche de remplir la carte SD | DoS |
| D17 | **Isolation des daemons Docker** : revue de la stack | revue | aucun `privileged`, pas de montage du socket Docker, `cap_drop: [ALL]`, `no-new-privileges`, `read_only`, utilisateur non-root, services internes sans port publié | durcissement Docker |
| D18 | **Wi-Fi de la table** : revue de la config de l'AP | revue | WPA2-PSK, CCMP/AES seulement, WPS coupé, passphrase longue hors git, pas de NAT vers un autre réseau | Wi-Fi |
| D19 | **Session Opérateur** : cookie `sx_session` | navigateur | `HttpOnly; Secure; SameSite=Strict`, 12 h ; `Origin` vérifié sur le WebSocket (autre origine → `403`) | Operator session |

> D3, D6–D16 démontrent la même chose vue de l'attaquant : c'est aussi la grille qu'on applique à une table consentante dans le volet offensif.

---

## Volet offensif — auditer une table consentante

Même méthode, retournée vers la cible `192.168.<cible>.1`. On documente chaque étape, réussie ou non, dans le [rapport](RAPPORT-AUDIT.md).

1. **Reconnaissance.** Cartographie des ports TCP/UDP (Nmap). Relever les services exposés, leurs versions, les éventuels ports en clair.
2. **Analyse du transport.** `openssl s_client` sur chaque port TLS : version, certificat, chaîne de confiance. Capture Wireshark d'une session : chercher un identifiant ou une mesure lisibles en clair.
3. **Authentification.** Broker : tentative anonyme, test de l'ACL avec un compte si on en obtient un. API : appel d'un endpoint protégé sans session ; forge d'un `kind` ou d'un `source` si un jeton fuite.
4. **Résilience (DoS mesuré, cible prévenue).** Dépasser les limites de login/commandes/alertes et vérifier le `429`/rejet. Message MQTT surdimensionné. Observer si le service tient.
5. **MitM (sur le segment de la table, avec accord).** Tenter d'intercepter/rejouer du trafic ; vérifier que le chiffrement et la vérification de la CA l'empêchent.
6. **Clôture.** Restituer les constats à la table auditée, ne rien conserver, remplir le rapport.

## Barème visé

L'axe 2 de la soutenance note le « durcissement prouvé du serveur » et la « preuve matérielle du chiffrement des flux ». Les captures Nmap (D1–D3), la capture Wireshark (D8) et la sortie de `harden.sh --check` sont cette preuve : elles vont dans la matrice de sécurité du dossier et sur une diapositive de la présentation.

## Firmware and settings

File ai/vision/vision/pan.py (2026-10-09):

"""The camera on its servo: it turns to keep the person followed in the middle of its image.

- `PanFollower`, the logic: from where that person stands around the camera to how far it is turned, at
  each instant. Pure, like the tracker: no servo and no clock in it, the caller passes the monotonic time.
- `PanDrive`, what turns the camera: `PAN_DRIVE`, `pwm` (`SysfsPwmServo`, a servo on one of the Pi's
  hardware PWM pins), `stepper` (`GpioStepper`, a geared stepper motor on four of its GPIOs) or `none` (the
  camera is fixed: nothing here runs). Another one plugs in the same way: a class with `open()`, `turn()`
  and `close()`, and a line in `DRIVES`.

- `python -m vision.pan <degrees>`, the service stopped: turns the camera by that much and leaves it
  there. Says whether the motor is wired and which way it turns, and puts a camera back to where it rests.

Angles are in degrees from where the camera rests, positive toward the right of its image: the `pan` of an
`intrusion` Alert. Where it rests, its 0, is where it stands when the service starts: the stepper counts
its half-steps from there, and the service parks it there as it stops.
"""

import logging
import math
import os
import sys
import threading
import time
from collections import deque
from typing import Callable, Protocol, Sequence

from sentinel_common.config import ConfigError, env_bool, env_float, env_str

logger = logging.getLogger(__name__)


def _is_number(value: object) -> bool:
    return isinstance(value, (int, float)) and not isinstance(value, bool) and math.isfinite(value)


class PanFollower:
    """How far the camera is turned, from one instant to the next.

    - while an intrusion goes on (`aim`), it turns toward the person followed, most of the way at each
      inference (`gain`: an inference is always a little late on where they are), and leaves them be once
      they are within `deadband` degrees of the middle of its image: it does not hunt for the last degree;
    - it never turns faster than `speed` degrees a second, so that what it frames does not blur and the
      servo, which says nothing of where it is, is where it was told to be; nor past `low` and `high`, the
      servo's travel;
    - when the last inference did not see that person, it stays where it is: they are found again where
      they were lost;
    - with no intrusion (`rest`), it stays where it is for `home_after` seconds (someone lost may come
      back into its image), then goes back to where it rests, at `home_speed`;
    - and once there, with `patrol` degrees, it looks around for intruders: from `patrol` degrees to the
      left to as many to the right and back again, no further than its travel, slowly, at `patrol_speed`,
      so that what it frames does not blur and the motor does not work for nothing. With 0, it stays
      where it rests.

    It remembers where it was for the last `memory` seconds: an image is always a little old, and the
    angle that goes with it is the one of when it was taken (`angle_at`).
    """

    def __init__(
        self,
        *,
        low: float = -90.0,
        high: float = 90.0,
        speed: float = 60.0,
        home_speed: float = 30.0,
        deadband: float = 4.0,
        gain: float = 0.7,
        memory: float = 2.0,
        home_after: float = 0.0,
        patrol: float = 0.0,
        patrol_speed: float = 8.0,
    ) -> None:
        if not (_is_number(low) and _is_number(high) and low <= 0 <= high and low < high):
            raise ValueError(f"low and high: a travel that holds 0, where the camera rests, expected, got {low!r} to {high!r}")
        if not (_is_number(speed) and speed > 0 and _is_number(home_speed) and home_speed > 0):
            raise ValueError(f"speed and home_speed: numbers > 0 expected, got {speed!r} and {home_speed!r}")
        if not (_is_number(deadband) and deadband >= 0):
            raise ValueError(f"deadband: a number >= 0 expected, got {deadband!r}")
        if not (_is_number(gain) and 0 < gain <= 1):
            raise ValueError(f"gain: a number in ]0, 1] expected, got {gain!r}")
        if not (_is_number(memory) and memory > 0):
            raise ValueError(f"memory: a number > 0 expected, got {memory!r}")
        if not (_is_number(home_after) and home_after >= 0):
            raise ValueError(f"home_after: a number >= 0 expected, got {home_after!r}")
        if not (_is_number(patrol) and patrol >= 0 and _is_number(patrol_speed) and patrol_speed > 0):
            raise ValueError(f"patrol and patrol_speed: numbers >= 0 and > 0 expected, got {patrol!r} and {patrol_speed!r}")
        self._low, self._high = low, high
        self._speed, self._home_speed = speed, home_speed
        self._deadband, self._gain, self._memory = deadband, gain, memory
        self._home_after, self._patrol_speed = home_after, patrol_speed
        # Its patrol, within its travel: on one side only when where it rests is an end of it.
        self._patrol = (max(-patrol, low), min(patrol, high)) if patrol > 0 else None
        self._idle_since: float | None = None  # since when there is no intrusion, None during one
        self._patrolling = False  # it is back where it rests, and looks around from there
        self._angle = 0.0  # how far it is turned
        self._goal = 0.0  # how far it is turning to
        self._pace = speed  # and how fast, in degrees a second
        self._at: float | None = None  # when it was last moved on
        self._trail: deque[tuple[float, float]] = deque()  # (when, how far turned), oldest first

    @property
    def angle(self) -> float:
        """How far the camera is turned, as of the last call."""
        return self._angle

    def aim(self, bearing: float | None, now: float) -> float:
        """After an inference of an intrusion in progress: `bearing` is where the person followed stands
        (the tracker's `target`), None when that inference did not see them. Returns the angle to turn to
        now."""
        self.step(now)
        self._idle_since, self._patrolling = None, False
        self._pace = self._speed
        off = bearing - self._angle if bearing is not None and _is_number(bearing) else 0.0
        if abs(off) > self._deadband:
            self._goal = min(max(self._angle + self._gain * off, self._low), self._high)
        else:
            self._goal = self._angle
        return self._angle

    def rest(self, now: float) -> float:
        """After an inference with no intrusion in progress: after `home_after` seconds, back to where it
        rests, then on patrol around it."""
        if self._idle_since is None:
            self._idle_since = now
            self._goal = self._angle  # it waits where it is
        return self.step(now)

    def step(self, now: float) -> float:
        """Turns on toward where it is going, for the time gone by since the last call. Returns the angle
        to turn to now. A clock that goes back turns nothing."""
        if self._at is not None:
            reach = self._pace * max(0.0, now - self._at)
            off = self._goal - self._angle
            # Right there when within reach, give or take the rounding of the steps before: an end of its
            # patrol is reached, and it turns back.
            self._angle = self._goal if abs(off) <= reach + 1e-9 else self._angle + math.copysign(reach, off)
        if self._idle_since is not None:
            self._idle(now)
        if self._at is None or now > self._at:
            self._at = now
            self._trail.append((now, self._angle))
            while len(self._trail) > 1 and now - self._trail[1][0] >= self._memory:
                self._trail.popleft()
        return self._angle

    def _idle(self, now: float) -> None:
        """Where it goes with no intrusion: nowhere for `home_after` seconds, then where it rests, then
        from one end of its patrol to the other."""
        if now - self._idle_since < self._home_after:
            return
        if not self._patrolling:
            self._goal, self._pace = 0.0, self._home_speed
            if self._angle == 0.0 and self._patrol is not None:
                # From where it rests, to the right first.
                self._patrolling, self._goal, self._pace = True, self._patrol[1], self._patrol_speed
        elif self._angle == self._goal:
            low, high = self._patrol
            self._goal = low if self._goal == high else high

    def angle_at(self, moment: float) -> float:
        """How far the camera was turned at `moment`, between the two instants it remembers around it.
        Further back than it remembers, the oldest it does; later than the last call, where it is now."""
        before = None
        for at, angle in self._trail:
            if at >= moment:
                if before is None or at == moment:
                    return angle
                share = (moment - before[0]) / (at - before[0])
                return before[1] + (angle - before[1]) * share
            before = (at, angle)
        return self._angle

    def way_home(self, every: float) -> list[float]:
        """The angles to go through, one every `every` seconds, to be back where it rests at `speed`: for
        the service to park the camera as it stops. Empty when it is there."""
        stride = self._speed * every
        steps = math.ceil(abs(self._angle) / stride - 1e-9) if stride > 0 else 0
        return [self._angle * (1 - step / steps) for step in range(1, steps + 1)]


class PanDrive(Protocol):
    """What turns the camera. One that counts how far it really turned it also has `angle_at(moment)`, on
    the monotonic clock: the service then takes its word rather than the follower's, which only supposes
    that the motor kept up."""

    name: str

    def open(self) -> None:
        """Gets ready to turn the camera, to where it rests. Never raises because the servo is not there."""

    def turn(self, angle: float) -> None:
        """Turns the camera to `angle` degrees. Called on the loop's thread, many times a second."""

    def close(self) -> None:
        """Lets the servo go."""


class SysfsPwmServo:
    """A hobby servo on a hardware PWM channel of the Pi, through the kernel's /sys/class/pwm: a pulse
    every 20 ms, whose width says the angle, `min_us` microseconds at `low` degrees to `max_us` at `high`.
    The kernel times the pulses: none of the jitter of pulses timed from Python, which a servo shakes
    with, and the camera on it.

    `directory` is the channel's own directory (`…/pwmchip0/pwm0`), exported by the host and given to the
    container: docker-compose.pan.yml. `invert` is for a servo mounted the other way up: it turns the
    other way for the same pulse.

    A servo, a channel or a right that is missing stops nothing: it is logged, tried again every
    `retry` seconds, and the camera stays fixed meanwhile.
    """

    name = "pwm"

    def __init__(
        self,
        directory: str,
        *,
        low: float = -90.0,
        high: float = 90.0,
        min_us: float = 500.0,
        max_us: float = 2500.0,
        invert: bool = False,
        period_ms: float = 20.0,
        retry: float = 5.0,
        clock: Callable[[], float] = time.monotonic,
    ) -> None:
        if not directory:
            raise ValueError("directory: the PWM channel's directory expected")
        if not low < high:
            raise ValueError(f"low and high: low < high expected, got {low!r} to {high!r}")
        if not 0 < min_us < max_us < period_ms * 1000:
            raise ValueError(f"min_us and max_us: 0 < min < max < the period expected, got {min_us!r} to {max_us!r}")
        self._directory = directory
        self._low, self._high = low, high
        self._min_us, self._max_us, self._invert = min_us, max_us, invert
        self._period_ns = round(period_ms * 1_000_000)
        self._retry, self._clock = retry, clock
        self._ready = False
        self._tried_at: float | None = None
        self._problem: str | None = None
        self._duty_ns: int | None = None  # the pulse last written

    @classmethod
    def from_env(cls) -> "SysfsPwmServo":
        low, high = _env_travel()
        min_us = env_float("PAN_MIN_US", 500, min=100, max=5000)
        max_us = env_float("PAN_MAX_US", 2500, min=100, max=5000)
        if not min_us < max_us:
            raise ConfigError(f"PAN_MIN_US and PAN_MAX_US: PAN_MIN_US < PAN_MAX_US expected, got {min_us:g} and {max_us:g}")
        return cls(
            env_str("PAN_PWM_DIR", "/sys/class/pwm/pwmchip0/pwm0"),
            low=low,
            high=high,
            min_us=min_us,
            max_us=max_us,
            invert=env_bool("PAN_INVERT", False),
        )

    def pulse_us(self, angle: float) -> float:
        """The width of the pulse that turns the servo to `angle`, kept within its travel."""
        share = (min(max(angle, self._low), self._high) - self._low) / (self._high - self._low)
        if self._invert:
            share = 1 - share
        return self._min_us + share * (self._max_us - self._min_us)

    def open(self) -> None:
        self._start(0.0)

    def turn(self, angle: float) -> None:
        if not self._ready:
            if self._tried_at is not None and self._clock() - self._tried_at < self._retry:
                return
            self._start(angle)
            return
        duty = round(self.pulse_us(angle) * 1000)
        if duty == self._duty_ns:
            return
        try:
            self._write("duty_cycle", duty)
            self._duty_ns = duty
        except OSError as error:
            self._lost(error)

    def close(self) -> None:
        if not self._ready:
            return
        self._ready = False
        try:
            self._write("enable", 0)
        except OSError as error:
            logger.warning("Servo on %s could not be let go (%s)", self._directory, error)

    def _start(self, angle: float) -> None:
        self._tried_at = self._clock()
        duty = round(self.pulse_us(angle) * 1000)
        try:
            # The period first: a channel just exported has none, and refuses everything else until it
            # has one. One left with a pulse longer than this period refuses the period: without its
            # pulse, it takes it.
            try:
                self._write("period", self._period_ns)
            except OSError:
                self._write("duty_cycle", 0)
                self._write("period", self._period_ns)
            self._write("duty_cycle", duty)
            self._write("enable", 1)
        except OSError as error:
            self._lost(error)
            return
        self._ready, self._duty_ns, self._problem = True, duty, None
        logger.info("Servo on %s ready", self._directory)

    def _lost(self, error: OSError) -> None:
        self._ready, self._duty_ns = False, None
        # Logged when the reason changes, not on every retry of a servo left unplugged.
        if str(error) != self._problem:
            self._problem = str(error)
            logger.warning("Servo on %s unavailable (%s): the camera stays fixed, retrying every %g s", self._directory, error, self._retry)

    def _write(self, name: str, value: int) -> None:
        with open(os.path.join(self._directory, name), "w") as file:
            file.write(str(value))


# The coils of a 28BYJ-48, IN1 to IN4 of its ULN2003 board, at each of the 8 half-steps that turn its rotor
# once: one coil, then two, then the next one alone. Each half-step is next to the one before.
HALF_STEPS: tuple[tuple[int, int, int, int], ...] = (
    (1, 0, 0, 0),
    (1, 1, 0, 0),
    (0, 1, 0, 0),
    (0, 1, 1, 0),
    (0, 0, 1, 0),
    (0, 0, 1, 1),
    (0, 0, 0, 1),
    (1, 0, 0, 1),
)
_COILS_OFF = (0, 0, 0, 0)


class Lines(Protocol):
    """The four GPIO lines of a stepper's board, IN1 to IN4: `put` sets them, `release` gives them back."""

    def put(self, values: Sequence[int]) -> None: ...

    def release(self) -> None: ...
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

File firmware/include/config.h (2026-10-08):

#pragma once

#include <stdint.h>

// The broker's ACL only lets sentinel-01 publish on sentinel/sentinel-01/{telemetry,alert}.
constexpr const char *SENTINEL_ID = "sentinel-01";

constexpr uint32_t CYCLE_MS = 1000;        // one telemetry snapshot per cycle
constexpr uint32_t SOUND_WINDOW_MS = 50;   // `sound` = share of the cycle's 50 ms windows that were loud
constexpr uint32_t SOUND_MIN_MS = 2;       // a window is loud once the sensor heard sound for 2 of its ms
// The CZN-15E pulls its output LOW, and lights its LED, while it hears sound. A module that does
// the opposite: false.
constexpr bool SOUND_ACTIVE_LOW = true;

// Alert thresholds. Raised at the threshold, cleared only once back under it minus the
// hysteresis: one Alert per transition, no flapping. Calibrate them on the real kit by watching
// the readings on the serial monitor or the dashboard.
constexpr int GAS_WARNING = 1500;          // MQ-2, millivolts at IO34 behind the divider (0–3300)
constexpr int GAS_CRITICAL = 2500;
constexpr int GAS_HYSTERESIS = 200;
constexpr uint32_t GAS_WARMUP_MS = 60000;  // the MQ-2 reads high while its heater warms up

constexpr float THERMAL_WARNING = 40.0f;   // °C
constexpr float THERMAL_CRITICAL = 55.0f;
constexpr float THERMAL_HYSTERESIS = 2.0f;

constexpr float NOISE_RAISE = 0.10f;       // a clap fills a couple of windows
constexpr float NOISE_QUIET = 0.05f;
constexpr uint32_t NOISE_HOLD_MS = 3000;   // quiet for this long before `noise` clears

constexpr uint32_t PIR_WARMUP_MS = 60000;  // the HC-SR501 triggers on its own while it settles
constexpr uint32_t PRESENCE_HOLD_MS = 5000;  // PIR low for this long before `presence` clears

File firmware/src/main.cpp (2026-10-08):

// The Sentinel: reads the Probes, decides its own Alerts, sounds the Alarm by itself, and streams
// a telemetry snapshot per cycle to the Command Post over MQTTS. Contract: docs/ARCHITECTURE.md.
#include <Arduino.h>
#include <ArduinoJson.h>

#include "alerts.h"
#include "config.h"
#include "probes.h"
#include "speaker.h"
#include "uplink.h"

namespace {

char telemetryTopic[64], alertTopic[64];
Readings readings;
uint32_t lastCycle = 0;

// Alert transitions wait here while the broker is out of reach; when full, the oldest goes.
struct Pending {
  AlertEvent event;
  char ts[24];  // when it happened; empty if the time was not known yet
};
constexpr size_t QUEUE_SIZE = 16;
Pending queue[QUEUE_SIZE];
size_t queued = 0;

double rounded(float value, int decimals) {
  double scale = pow(10, decimals);
  return round(value * scale) / scale;
}

void enqueue(const AlertEvent &event) {
  Serial.printf("[alert] %s %s %s (%s)\n", event.kind, event.raised ? "raised" : "cleared",
                severityName(event.severity), event.alertId);
  if (queued == QUEUE_SIZE) {
    memmove(queue, queue + 1, sizeof(Pending) * (QUEUE_SIZE - 1));
    queued--;
  }
  Pending &pending = queue[queued++];
  pending.event = event;
  if (!uplink::isoNow(pending.ts, sizeof pending.ts)) pending.ts[0] = '\0';
}

bool publishAlert(const Pending &pending) {
  const AlertEvent &event = pending.event;
  JsonDocument doc;
  doc["alert_id"] = event.alertId;
  doc["kind"] = event.kind;
  doc["severity"] = severityName(event.severity);
  doc["state"] = event.raised ? "raised" : "cleared";
  if (!isnan(event.value)) doc["value"] = rounded(event.value, 2);
  doc["detail"].to<JsonObject>();
  char now[24];
  if (pending.ts[0]) doc["ts"] = pending.ts;
  else if (uplink::isoNow(now, sizeof now)) doc["ts"] = now;
  else return false;
  char payload[256];
  serializeJson(doc, payload);
  return uplink::publish(alertTopic, payload);
}

void flushAlerts() {
  size_t sent = 0;
  while (sent < queued && publishAlert(queue[sent])) sent++;
  memmove(queue, queue + sent, sizeof(Pending) * (queued - sent));
  queued -= sent;
}

void publishTelemetry() {
  char ts[24];
  // The contract wants every reading and a real time: wait for the DHT22 and for the Pi's clock.
  if (isnan(readings.temp) || !uplink::isoNow(ts, sizeof ts)) return;
  JsonDocument doc;
  doc["ts"] = ts;
  JsonObject r = doc["readings"].to<JsonObject>();
  r["temp"] = rounded(readings.temp, 1);
  r["humidity"] = rounded(readings.humidity, 1);
  r["air"] = readings.air;
  r["pir"] = readings.pir;
  r["sound"] = rounded(readings.sound, 2);
  char payload[256];
  serializeJson(doc, payload);
  uplink::publish(telemetryTopic, payload);
}

void onCommand(const char *payload, size_t length) {
  JsonDocument doc;
  if (deserializeJson(doc, payload, length)) {
    Serial.println("[command] not JSON, ignored");
    return;
  }
  const char *actuator = doc["actuator"] | "";
  const char *action = doc["action"] | "";
  Serial.printf("[command] %s %s\n", actuator, action);
  // The contract still calls the Alarm `buzzer`: it is the speaker now.
  if (strcmp(actuator, "buzzer") == 0) speaker::command(action);
}

// After a reconnection, the api may have missed transitions: it gets every raised Alert again.
void onBrokerConnect() {
  alerts::reemitActive(enqueue);
  flushAlerts();
}

void cycle(uint32_t now) {
  probes::read(readings);
  alerts::evaluate(readings, now, enqueue);
  speaker::setLocal(alerts::critical());
  if (uplink::brokerUp()) {
    flushAlerts();
    publishTelemetry();
  }
  Serial.printf("T=%.1f H=%.0f air=%d pir=%d son=%.2f | wifi=%d heure=%d broker=%d %s\n", readings.temp,
                readings.humidity, readings.air, readings.pir, readings.sound, uplink::wifiUp(), uplink::timeKnown(),
                uplink::brokerUp(), uplink::problem());
}

}  // namespace

void setup() {
  Serial.begin(115200);
  Serial.printf("\n[sentinel] %s booting\n", SENTINEL_ID);
  snprintf(telemetryTopic, sizeof telemetryTopic, "sentinel/%s/telemetry", SENTINEL_ID);
  snprintf(alertTopic, sizeof alertTopic, "sentinel/%s/alert", SENTINEL_ID);

  speaker::begin();
  speaker::beep(120);
  probes::begin();
  alerts::begin();
  uplink::begin(onCommand, onBrokerConnect);
}

void loop() {
  uint32_t now = millis();
  uplink::update(now);
  if (now - lastCycle >= CYCLE_MS) {
    lastCycle = now;
    cycle(now);
  }
}

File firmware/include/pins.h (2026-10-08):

#pragma once

// Sentinel wiring on the ESP32 DevKitC V4 (AZ-Delivery): GPIO numbers, as on the wiring diagram.

constexpr int PIN_MQ2_AO = 34;  // MQ-2 analog output, through the 10k/20k divider (ADC1)
constexpr int PIN_SOUND = 26;   // CZN-15E digital output
constexpr int PIN_PIR = 27;     // HC-SR501 output, already 3.3 V
constexpr int PIN_DHT = 4;      // DHT22 data, 10k pull-up to 3V3
constexpr int PIN_SPEAKER = 25;  // the speaker through 100R, or the buzzer, to GND: never to 5V

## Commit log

2026-10-05 Lock architecture after brainstorm: 3-node, ESP32, Pi Command Post
    - 3-node Edge-to-Server: Sentinel (ESP32) / Command Post (Pi 4) / AI Worker (laptop)
    - CSI camera owned by the Pi; heavy inference delegated to the laptop
    - Alert ownership map + autonomous local Alarm on the Sentinel
    - Two-path ingress contract (MQTTS + POST /api/v1/alerts) with concrete JSON schemas
    - Digital Twin = Outpost; intruder via x_norm; Status (nominal/elevated/critical)
    - GLOSSARY: Command Post, AI Worker, Status, Tamper; Sentinel=ESP32
    - Committed sensor core: air, PIR, DHT, accelerometer, camera + buzzer/MP3/joystick/fingerprint
    - Synced README, docs and all pillar READMEs to the decisions
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2026-10-05 docs: align the hardware with the team's actual kit
    - Command Post is a Raspberry Pi 4 with a ZIF (CSI) camera module,
    listed as deviations from the brief next to the ESP32 one.
    - Sentinel probes: DHT22, MQ-2, PIR and a sound sensor (new `sound`
    reading and `noise` Alert); LCD 16x128 instead of the OLED.
    - Drop the accelerometer/tamper, fingerprint, joystick and MP3 speaker
    (contract, demo beat 3, Tier 2, Twin mapping, MCO console).
    - Vision builds on automaticdai/rpi-object-detection (TFLite person
    detection + Picamera2) instead of YOLOv8n/NCNN; ignore *.tflite.
2026-10-05 feat(backend): align the contract with the team's actual kit
    docs/ARCHITECTURE.md (37d6039) is the source of truth: the Sentinel has
    no accelerometer and no speaker, but gains a sound sensor.
    - Telemetry readings: drop `accel`, add `sound` (raw ADC, 0–4095).
    - Alert kinds: `tamper` becomes `noise`, decided by the ESP32, with no
    detail (the sound level goes in `value`).
    - Actuators: `buzzer` and `led` only.
    Without this the strict schema would reject the real ESP32's telemetry
    at the MQTTS ingress (#4). Fixtures, mock feed and backend README follow.
2026-10-05 fix(dashboard): keep retrying the feed when a connection attempt fails
    Node's WebSocket (undici, Node 22) fires only `error` on a refused
    connection, never the `close` the feed client waited for to schedule
    the next attempt: after one failure it stopped retrying for good. Treat
    `error` and `close` alike, once per socket, so the backoff loop goes on
    whichever runtime the feed runs in.
    Fixes the "keeps retrying while the Command Post is down" test, which
    failed on every run.
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2026-10-05 feat(backend): take Sentinel Alerts in over MQTTS (#22)
    The ingress now subscribes to sentinel/+/alert too. Each Alert goes
    through the same pipeline as POST /api/v1/alerts: paired by alert_id,
    recorded, broadcast, Status recomputed.
    The channel sets source (esp32) and sentinel (from the topic), whatever
    the payload says. Only the kinds the Sentinel decides alone come in this
    way (gas, thermal, presence, noise); anything else, or a payload that
    does not pass the schema, is dropped and logged, and the subscription
    carries on.
2026-10-05 feat(contract): sound is the share of the cycle the sensor heard sound
    The CZN-15E has a digital output only (above or below the threshold set
    by its potentiometer), no analog level. As decided in the backend PRD
    (#1), `sound` stays a number but now means the share of the cycle it
    heard sound, 0 to 1, instead of a raw ADC value. Docs, mock and
    fixtures follow.
2026-10-05 feat(backend): a mock feed with every kind of Alert, through the real pipelines
    The mock only sent telemetry and Status frames: the front could not show
    active Alerts, place an intruder or replay an Incident without hardware.
    Each tick now carries a telemetry snapshot plus the Alerts its producers
    would send, and goes through the same telemetry and Alert pipelines as
    MQTTS and POST /api/v1/alerts: paired by alert_id, recorded, broadcast,
    Status recomputed. One 40-tick loop plays a gas leak the predictive
    model flags first (gas warning -> critical -> warning, heat, someone
    past the PIR), a clap on the sound sensor, and an intruder crossing the
    camera's field with x_norm moving left to right: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
2026-10-05 feat(backend): rate limits on login, Alerts and commands
    As in docs/ARCHITECTURE.md: 5 logins a minute per address, 2 commands a
    second, 20 Alerts a second per service token. Past that: 429 with
    Retry-After, before anything is parsed or relayed. A fixed-window
    limiter in the process, no dependency.
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2026-10-05 docs: name the exact parts and drop the LED
    - LCD is a 1.8" 160x128 ST7735S (sold for the micro:bit, no pin
    header), not 16x128.
    - Camera is a Joy-IT RB-Camera-JT (OV5647, 5 MP) on the CSI port.
    - Sound sensor is a CZN-15E: digital output only, so `sound` is the
    share of the cycle that was loud (0-1).
    - ESP32 board is an AZ-Delivery DevKitC V4 (WROOM-32, 38 pins).
    - No LED in the kit: the Alarm is the buzzer alone, and the actuator
    command only targets `buzzer` (no `params.led`).
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2026-10-05 feat(dashboard): the Twin full screen, in studio light, with an orbiting camera (#30)
    /twin now takes the whole window under the top bar; / keeps its padded page. The Outpost stands on a black background under a key light that casts soft shadows and a cold rim light, and the camera goes around it by itself. The Operator can turn it and zoom between bounds that keep the Outpost in frame; three seconds after they let go, the orbit picks up speed again (autoOrbitSpeed, a pure function).
    The Status's grade (#12) now plays on that stage: it colors the key light and the perimeter ring. The sky stays black, so the grade's background is no longer drawn.
    Only what emits light glows: the halo is the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
2026-10-05 feat(dashboard): the Twin's Enclosure, with its LCD and LED ring alive (#31)
    The simple box of #20 gives way to the Sentinel-X product itself: a dark
    anodized, bevelled module on a mast, at an exaggerated scale, built in
    code (RoundedBoxGeometry, canvas-drawn textures), no external model.
    - Front: the LCD band, the camera lens, the PIR dome, the mic grille.
    Under the body: the ventilated Probe compartment, louvres front and
    back, the DHT22 and the MQ-2 between them. On top: the buzzer and the
    LED ring. Right side: the engraving AetherCorp / SENTINEL-X / serial.
    - Each Probe and actuator is a named object (ENCLOSURE_PARTS), for the
    later slices to find and drive.
    - toScene now gives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
2026-10-06 feat(dashboard): the Outpost as a maquette, on its socle, behind its fence (#32)
    The Enclosure no longer stands alone on a disc: around it is the site it protects. A socle of terrain cut clean, with fine contour lines, afloat in the black; the micro power plant (generator hall, two chimneys, transformer station, a gas tank and the pipe from it to the hall); a fence of posts around the site, open at the gate. The plant is built in code from two bevelled volumes, Box and Turned, in graphite and off-white: color stays with the Status and the signals.
    The site has one ground plan, SITE, which the components only draw and which the later reactions will be anchored on. Its tests hold it together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
2026-10-06 feat(dashboard): the Twin lights the camera sector on an intrusion and pulses the drifting Probes (#13)
    The two threats the AI services see now show on the maquette. While an intrusion Alert is active, the camera sector on the ground lights up in the critical red: the zone of the perimeter the camera watches, whole, wherever the intruder stands in it. It goes out when the last intrusion is cleared. Placing the intruder from x_norm stays for #23.
    A predictive Alert names what drifts in its drivers, and DRIVER_PROBES gives the Probe each one is read from: temp_slope is the DHT22, air_slope the MQ-2. Those Probes pulse in an orange of their own, which is not a Status color, so the drift shows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
2026-10-06 feat(dashboard): the Twin sends a wave from its Enclosure over the socle on a clap (#37)
    Each noise Alert raised sends a wave of light from the foot of the Enclosure's mast over the socle: it spreads for 1.5 s, lights up within its first tenth and fades out to nothing as it ends. The louder the clap (the Alert's value, 0-1), the further it goes and the brighter it shines: the loudest crosses the whole socle.
    A noise Alert can be cleared on the next cycle, so the wave is an event, not a state: it starts from the raised frame itself, read from the feed's history, and plays to its end whatever comes after. framesSince gives the frames that came in since the last one seen, clapsIn the claps amo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
2026-10-06 feat(dashboard): the Twin labels the drifting Probes with the predictive model's score (#39)
    The drift now says what it is. Under the Probes a predictive Alert makes pulse, a card reads « dérive · score 0.91 »: the anomaly_score of the last raised of the active predictive Alerts that pulse a Probe, to two decimals. An Alert whose drivers are all unknown pulses nothing and labels nothing.
    toScene gives it as scene.enclosure.drift, { score, label }, and driftLabel(score) the text: both from the mapper, tested without a render, next to the drivers → Probes mapping of #13.
    The card is a sprite drawn over the mast and the body: it faces the camera wherever the orbit takes it, so the drift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
2026-10-06 fix(dashboard): the Twin keeps its whole stage, and capture mode its bare window, under the sidebar layout (#30, #40)
    The sidebar layout dropped .shell and .topbar, which gave /twin the whole window and hid the top bar in
    capture mode. The Twin's route now says it is a stage (handle), and layoutMode() picks the layout: the
    padded page, the whole space under the header, or the stage alone on the window with ?capture.
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2026-10-06 feat(ai): the vision tracker turns the camera's detections into one intrusion Alert that follows the intruder and clears when they leave (#70)
    vision.tracker.IntruderTracker, pure and stdlib only: the most confident
    person, raised after 2 inferences in a row, raised again on the same
    alert_id when x_norm moves by 0.05 (at most every 500 ms, a held-back
    move sent once the interval is over), cleared 3 s after the last
    sighting with the last known detail, also through tick() when inference
    stalls. Time is passed in, so the tests replay detection sequences and
    check every Alert against the contract mirror.
    vision/tests is a package: under importlib mode pytest otherwise names
    its modules vision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
    [test_tracker.py, tracker.py]
2026-10-06 feat(ai): the AI services post their Alerts through one client that keeps their order and retries what the api could not take (#68)
    sentinel_common.alerts.AlertClient queues each Alert and returns at once; a
    single worker thread sends the queue in order to POST /api/v1/alerts with the
    service's Bearer token, so a cleared never overtakes its raised. A network
    error, a 5xx or a 429 (after its Retry-After) is retried with an exponential
    backoff; any other 4xx is logged with the api's message and skipped. The
    queue is bounded, close() flushes it within a deadline, and the token stays
    out of logs, errors and repr(), off any proxy and off any redirect.
    sentinel_common.config reads a service's env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
2026-10-06 feat(dashboard): one top bar again, and no icon library
    The shadcn sidebar gives way to the bar the app had before: Sentinel-X,
    the two surfaces as plain links, then the Status, the feed's state and
    the sign-out on the right. `● En direct` is back at full strength, a
    colored dot and the word, no longer small and grey. The Twin keeps its
    whole stage under the bar, and capture mode its bare window.
    lucide-react is gone: a state is said with a colored dot and words, a
    trend with ▲ / ▼ (status card, reading tiles, incidents, camera,
    toasts, login). The alarm buttons keep their labels only.
    The sidebar and what only it used (sheet, separator, tooltip,
    use-mobile) are removed, with the sid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
2026-10-06 feat(ai): the predictive service scores the live telemetry over MQTTS and posts its drift Alerts (#72)
    `python -m predictive run`, the image's default: subscribed to sentinel/+/telemetry over mqtts://
    only (user predictive, broker verified against the team CA, TLS >= 1.2), one Monitor per Sentinel
    taken from the topic, transitions posted through the common AlertClient. Invalid messages are
    ignored and counted, the broker retried forever. It starts without a model, says so, and loads
    MODEL_FILE as soon as it appears or changes; a broken file keeps the previous model. A new model
    or a stop clears the episodes still raised.
    Dockerfile (context ai/, non-root uid 10001, read_only + cap_drop: ALL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
    [service.py]
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2026-10-06 Merge origin/main into claude/ai-vision-pipeline-73
    The vision service's tests become test_vision_service.py: with every
    service's tests named tests.*, they collided with the predictive service's
    test_service.py merged in #85. The tests/__init__.py files now say a test
    module's name must be unique across ai/.
    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
    [test_vision_service.py]
2026-10-06 feat(infra): vision and predictive join the Command Post's stack, their secrets come from setup.sh and the camera feed sits behind the Operator session (#75)
    - docker-compose.yml: vision and predictive, hardened, on the internal network only, built from ai/.
    predictive reads the api's history (api-data mounted :ro at /history) and keeps its model on the
    new predictive-model volume; `docker compose run --rm predictive train --from … --to …`.
    vision gets the host's video group (VIDEO_GID, 44 by default) and CAMERA_SOURCE (opencv:0 until
    Picamera2, #46); its camera nodes are in docker-compose.camera.yml, so a missing node never stops
    the whole stack (on the Pi: COMPOSE_FILE in .en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
2026-10-06 feat(dashboard): the Twin pulses a Probe for every driver the predictive model can name (#76)
    DRIVER_PROBES covers the model's 7 features, the closed vocabulary of docs/ARCHITECTURE.md:
    temp, temp_slope, temp_mean and humidity pulse the DHT22; air, air_slope and air_mean the MQ-2.
    An Alert whose drivers are a Reading or a mean no longer leaves the Twin still, and gets its
    drift label. A driver outside the vocabulary still pulses nothing.
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2026-10-06 feat(dashboard): a session that ends brings the login screen back, and the feed stops retrying (#48)
    After 12 h, or a restart of the API (it keeps its sessions in memory), the feed's socket was
    turned down and retried for ever behind a "Signal lost": nothing asked for the session again.
    - AuthGate asks GET /api/v1/auth/check again each time the feed goes down (LiveFeedProvider's
    onDown, wired in app.tsx): 401 → the login screen, and the feed below unmounts, so it no longer
    retries. 204 or no answer → still in: a Command Post out of reach has lost its signal, not its
    Operator. afterCheck(session, answer) is that rule, pure and tested.
    - Any call the API answers 401 says it too (onU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
2026-10-06 feat(dashboard): the Twin's intruder stands in detection brackets, under the vision model's confidence (#93)
    Four brackets frame the figurine like a detection in an image and face the Twin's camera whatever the orbit; a label over its marker reads « PERSONNE · 88 % », from the intrusion Alert's confidence. Both follow the figurine as it glides and fade in and out with it.
    The scene mapper gives the intruder its confidence and its label; x_norm alone still places it, bbox is not read. The label is drawn on the card of the drift's label, now a component of its own (LabelCard).
2026-10-06 feat(infra): plug-and-play.sh gets a French terminal interface
    - infra/ui.sh: numbered steps with a spinner and their time, the commands'
    output in ~/.local/share/sentinel-x/plug-and-play.log with its last line
    under the running step, a framed reason and the failed command's last lines
    on an error, a framed summary with the commands to copy at the end
    - sudo and the Operator password are asked first: the steps then run alone
    - plain lines without a terminal, NO_COLOR honoured, Ctrl-C stops cleanly
    - docs/INSTALLATION-PI.md follows the new steps and messages
2026-10-06 feat(dashboard): the Twin's intruder walks to where it is seen, turned the way it goes (#94)
    The figurine no longer glides upright from one x_norm to the next: it walks there, arms and legs in opposition, facing the way it goes along the fence, and comes back to rest facing the lens once it has stopped. A newly raised intruder appears at rest, without a step from where a previous one stood.
    The walk cycle is a pure function of a phase (utils/walk.ts), and the phase goes by the ground covered on the arc, not by the time: the planted foot stays where it was put down at any pace and any frame rate.
    The intruder's track (utils/track.ts, formerly glide.ts) now walks at the pace of the sightings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
2026-10-06 feat(infra): the status screen is an HDMI screen on the Pi, the ESP32's LCD goes
    The brief's IP/Wi-Fi status screen moves from the Sentinel to the Command
    Post: an 800x480 HDMI screen plugged into the Pi.
    - infra/screen.py draws it on the console (tty1), every second, in large
    Terminus letters: the table Wi-Fi and its access point, the dashboard's
    address, the Sentinel (online, on the Wi-Fi, silent, absent), its last
    readings and raised Alerts, the webcam and the containers. The Pi OS's
    Python and python3-paho-mqtt only; text from the network is stripped of
    control characters before it reaches the console
    - it reads the broker with its own account, screen, which may only read
    se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
    [main.cpp, pins.h, uplink.cpp]
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2026-10-07 feat(ai): vision tells how near each person is, follows the nearest with a servo and lists the others
    The intrusion Alert's detail gains four optional fields: h_norm (the share of the image's height the
    person's box takes), pan (degrees the camera is turned from where it rests), id and others (up to 4
    more people in the image). An Alert without them is still valid: recorded history and a fixed camera
    are unchanged.
    The tracker keeps each person from one inference to the next, follows the nearest and stays on them,
    and raises again when someone comes nearer, comes or leaves, or the camera has turned. PAN_DRIVE=pwm
    turns the camera with a servo on a hardware PWM channel of the Pi to keep that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
    [pan.py, service.py, test_pan.py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]
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2026-10-07 feat(firmware): the Alarm sounds on a DFPlayer Mini and its speaker, the buzzer goes
    The Sentinel's buzzer is replaced by a DFPlayer Mini (UART2: IO16 from
    its TX, IO17 to its RX through 1k) and a passive speaker on SPK_1/SPK_2.
    It plays the sounds of its own microSD card.
    - src/speaker.* in place of src/buzzer.*: the same Alarm, a siren while
    an Alert is critical; on (steady tone) / pattern (siren) / off from the
    Operator, off silencing until the next critical. The DFPlayer's serial
    protocol by hand, no new library: the Pi still builds offline
    - it resets the DFPlayer at boot and waits for it to say it reads its
    card, then sets the volume (ALARM_VOLUME in config.h) and beeps; with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
    [config.h, main.cpp, pins.h]
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2026-10-07 fix(firmware): the Alarm plays on the speaker through a transistor, the DFPlayer goes
    The DFPlayer Mini turned out faulty: it answered on the serial line but
    read no microSD card, with two cards formatted FAT32 on an MBR. The
    speaker is now driven by the ESP32 itself: IO25 through 1k to the base
    of an NPN (2N2222 or BC547), emitter to GND, the speaker between the 5V
    (through 47R, about 90 mA) and the collector.
    - src/speaker.*: a square wave on IO25, the buzzer's logic again: the
    1800/2600 Hz siren while an Alert is critical, on (steady 2600 Hz) /
    pattern (siren) / off from the Operator, a beep at boot
    - the DFPlayer's serial protocol, firmware/sd (its sounds and their
    generator), ALA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
    [config.h, main.cpp, pins.h]
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2026-10-08 feat(vision): the camera turns on a stepper motor, and the wiring diagrams join the docs
    The camera's servo was lost to a wiring mistake: a 28BYJ-48 stepper on
    its ULN2003 board replaces it, driven by the Pi's GPIOs. And the Alarm's
    speaker, with no transistor at hand, is wired the safe way.
    - vision: PAN_DRIVE=stepper (vision.pan.GpioStepper). Half-steps on IN1
    to IN4 through the kernel's GPIO chip and libgpiod (versions 1 and 2),
    one every PAN_STEP_MS (2 ms) at most, 4096 a turn; a thread of its own
    steps toward the last angle and lets the coils go once there. It counts
    its steps from where it starts: the camera is taken to rest there, and
    parked there at shutdown. A missing chi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
    [pan.py, pins.h, test_pan.py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]
2026-10-08 fix(firmware): the sound no longer reads 1 in silence, and the gas no longer 0 in clean air
    On the kit, `sound` stayed at 1, `air` was often 0 and `pir` always 0.
    - sound: its active level was guessed at boot, from 0.4 s of listening.
    A module that heard anything then, or set at the edge of its threshold,
    got it backwards, and silence counted as sound. It is now set:
    SOUND_ACTIVE_LOW in config.h, LOW as the CZN-15E does. And any edge
    made a 50 ms window loud, a few microseconds of glitch from the Wi-Fi
    too: the pin is now sampled every millisecond, and a window is loud
    past 2 ms of sound (SOUND_MIN_MS). The boot warns on the serial monitor
    when the module hears sound all the t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
    [config.h, probes.cpp]
2026-10-08 feat(vision): the Alerts say how far the stepper really turned the camera, which no longer swings past the person, and infra/plug-and-play.sh gives the motor to vision on its own
    The stepper is told where to turn once an inference: it is always behind where the follower has it, by 4 degrees at 100 ms an inference, more when the inference is slower or PAN_SPEED_DEG_S above what it steps at. The image was then taken for seen from further round than it was, and the camera swung past the person: by 9 degrees at 250 ms, by 12 at 60 degrees a second. GpioStepper now says where it counted the camera to be when the image was taken (angle_at), and the service takes its word.
    plug-and-play.sh takes d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
    [pan.py, service.py, test_pan.py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]
2026-10-08 fix(firmware): the siren keeps the riff's tempo while the loop waits on the broker, and plays its rests
    [main.cpp]
2026-10-09 feat(vision): the camera goes back to its 0 after a short wait, and patrols ±30° around it
    Where the camera stands when vision starts is its 0. With no intrusion it waits PAN_HOME_AFTER_S (2 s)
    where it lost the person, goes back to its 0, then looks around for intruders, PAN_PATROL_DEG (30°)
    either way at PAN_PATROL_SPEED_DEG_S (8°/s). Someone seen on the way is followed as before.
    Claude-Session: https://claude.ai/code/session_01XruM6qsx9ucVVjxGydfsLR
    [pan.py, test_pan.py, test_vision_service.py]
2026-10-09 fix(vision): the camera patrols on one side when where it rests is an end of its travel, instead of not at all
    With PAN_MIN_DEG=0 or PAN_MAX_DEG=0 the patrol was dropped without a word. It now goes from its 0 to
    PAN_PATROL_DEG on the side it can turn to, and back.
    [pan.py, test_pan.py]
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
